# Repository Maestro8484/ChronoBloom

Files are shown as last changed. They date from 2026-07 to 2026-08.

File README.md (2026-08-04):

# ChronoBloom

A 3-ring NeoPixel wall clock on the Seeed XIAO ESP32-C3. Seconds and minutes share the outer 60-LED ring, the way they share one track of marks on a real clock, and the hour hand is a spoke across the 24 and the 12. Web UI, NTP sync, OTA updates, ambient-light auto dimming, and Focus Reminder nudges for when you lose track of time. The diffused rings bloom like a flower, hence the name.

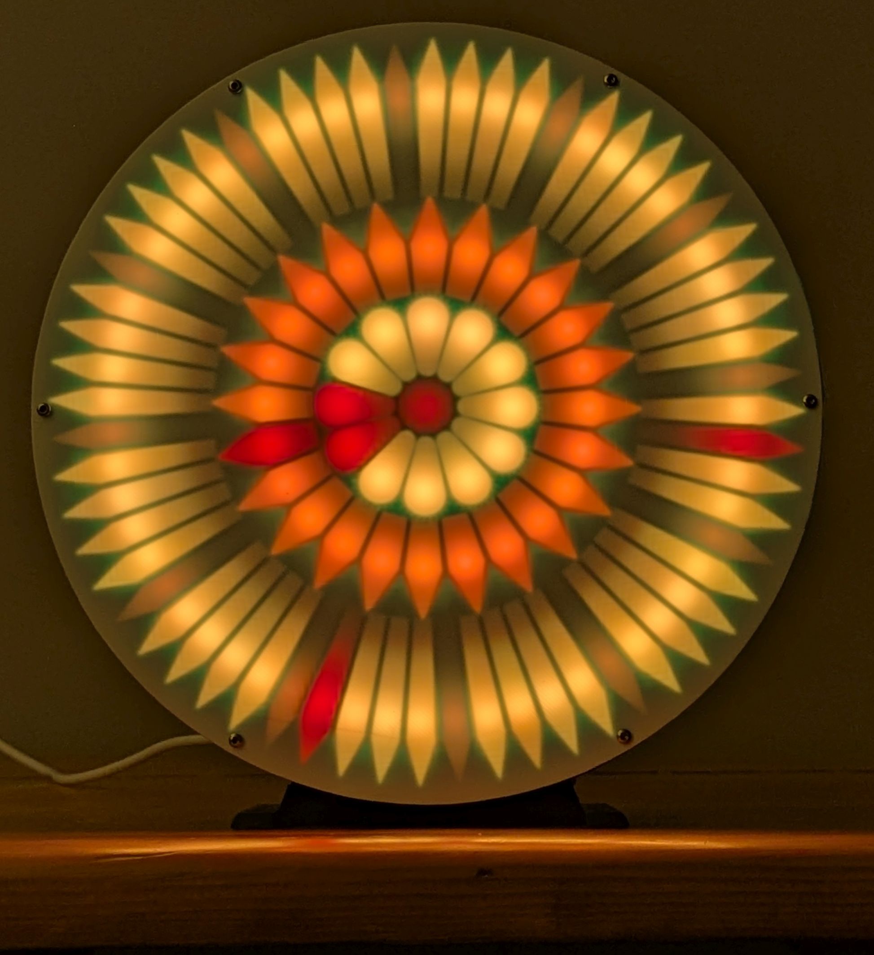
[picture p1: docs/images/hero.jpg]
ChronoBloom 8-inch build, Sunflower theme


ChronoBloom Demo (https://www.youtube.com/watch?v=KO6YdUoTq6A)

## You run the whole thing from a web page

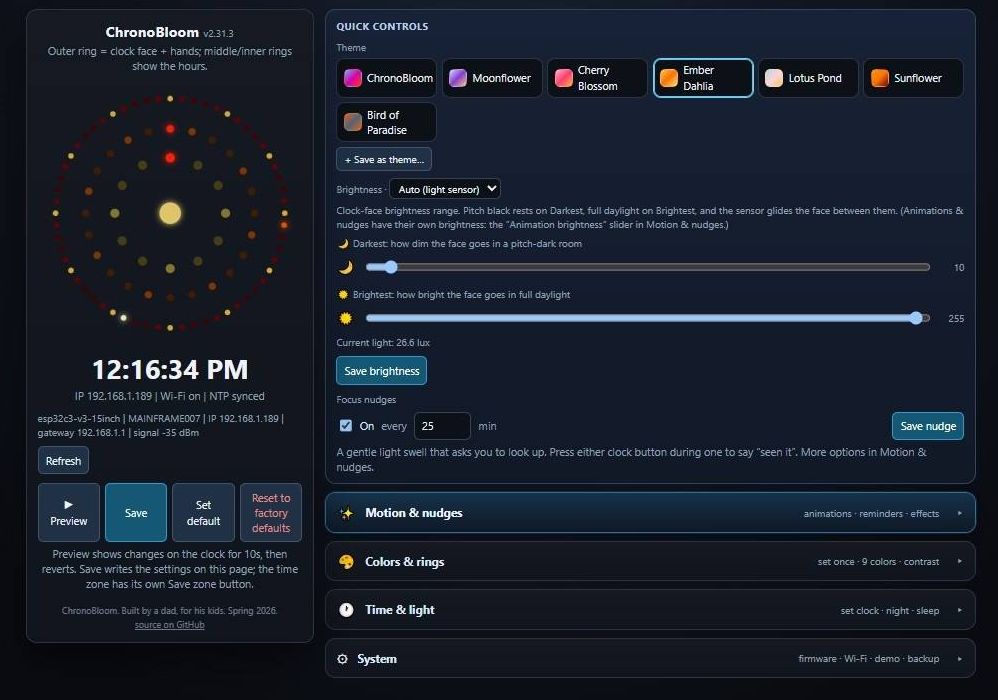
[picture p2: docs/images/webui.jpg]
The ChronoBloom web UI


No app, no account, no cloud. The clock serves this page itself, so you open it from a phone or a
laptop on the same wifi and everything is live as you change it: seven face themes, the color and
brightness of every ring on its own, eleven contrast presets, which animation the chimes and the
nudges play, the light sensor limits, your time zone, firmware updates and a settings backup.

More on it below, and there's a [full three and a half minute
tour](https://www.youtube.com/watch?v=FKXAHg8D2Fs) of every setting.

## Why I built it

I hyperfocus, and I lose hours to the wrong thing. Alarms don't fix it. One lands mid-thought, I
swipe it away, and I've already forgotten it. A change of light in the room does work. So I put it
in the thing I already look up to. And to look pretty.

The clock doesn't nag and there's nothing to dismiss. Every so often the light does something slow
and obvious at the edge of your vision, and you get to decide what happens next. An alarm demands.
A nudge asks. It helps that it's pretty, and that it's already on the wall doing a job, so I never
resent it going off.

The version that gets me is small and ordinary: I went downstairs to print a coloring page, found a
project on the way, and came back up an hour later empty-handed. The project will still be there
tomorrow. My kids being this age won't.

ChronoBloom is a clock built by a dad to keep time, and to keep life above the project at hand.
Look up. Shift gears. Tend to what matters.

The feature is called Focus Reminders and it's in [docs/FOCUS_REMINDERS.md](docs/FOCUS_REMINDERS.md).
Everything else on this clock got built around it.

### About the photos and the video

They don't do it justice, and I don't think a camera can. These are bright, narrow-band
addressable LEDs behind a diffuser. Your eye adapts locally, so a deep saturated red sitting
right next to a pale gold reads correctly, both at once. A sensor can't do that. It clips
whichever channel is brightest, fights the white balance, and blooms the highlights, so the
saturated hues come back either washed out or blown to white.

Getting even these shots took far more takes than it should have (ISO 10, 1/50, dark room) for
quality I'd call barely acceptable. So treat them as a hint, not a record. In other words it
looks better in person, and that's the one thing here I can't show you.

## What it does

- Time from NTP over WiFi, with timezone and DST rules. No RTC chip.
- Web UI on your LAN for colors, brightness, animations, and per-ring settings
- Seven face themes, six named for real blooming flowers (Moonflower, Cherry Blossom, Ember Dahlia, Lotus Pond, Sunflower, Bird of Paradise) and built from that flower's own colors
- Eleven curated contrast presets, plus nine colors you can set one ring element at a time
- Animation palettes are radial: petals on the outer ring, throat on the inner, stamen at the
  center, color ramping rim to core so a chime or a nudge reads as the clock blooming
- Quarter-hour, half-hour, and top-of-hour chime animations (3/3/5 styles)
- A light sensor drives auto-brightness. Pitch black room, LEDs sleep. Light returns, clock wakes.
- Focus Reminders: visual nudge animations at intervals you pick, built for interrupting hyperfocus. A peripheral ask, not an alarm.
- WiFi setup in the browser at flash time, or via captive portal on first boot. No hardcoding credentials.
- OTA firmware updates from a browser after the first USB flash
- Settings persist in EEPROM, with a user-saved defaults slot

## How this compares

[WLED](https://kno.wled.ge/) is a brilliant effects engine with a huge ecosystem, and it beats this project on effect count and community by a mile, but a ring clock like this one is a usermod you compile yourself. [Clockwise](https://github.com/jnthas/clockwise) is a browser-flashable 64x64 matrix clock, and nothing here touches its pixel-art faces. ChronoBloom is clock-first for this three-ring shape: per-ring hands, chimes, focus nudges, a per-frame power budget, lux sleep, and its own browser flasher. If you want an LED playground, run WLED. If you want this clock, this is its firmware.

## Bill of materials

Prices swing. Shop around.

| Part | Qty | Notes | Where |
|---|---|---|---|
| Seeed XIAO ESP32-C3 | 1 | The brain. USB-C, WiFi, tiny. About $10 for one, cheaper per board in a 3-pack. | [Amazon, single](https://www.amazon.com/dp/B0B94JZ2YF?tag=maestro8484-20) / [Amazon, 3-pack](https://www.amazon.com/dp/B0DGX3LSC7?tag=maestro8484-20) |
| WS2812B 241-LED ring set | 1 | Sold as a 9-ring kit (WESIRI), about $26. You use the 60, 24, and 12 rings plus 1 loose pixel for the center. Rest goes in the parts bin. Rings come pre-assembled with 3-wire JST leads. | [Amazon](https://www.amazon.com/WESIRI-WS2812B-Individually-Addressable-Controller/dp/B083VWVP3J?tag=maestro8484-20) |
| VEML7700 lux sensor module | 1 | Optional but worth it. Auto-brightness and dark-room sleep. Usually sold as a 2-pack. | [Amazon](https://www.amazon.com/dp/B0DRRGVTLH?tag=maestro8484-20) |
| Momentary push buttons | 2 | Time up/down, factory reset combo. Prewired 7mm ones save you a soldering job. | [Amazon](https://www.amazon.com/Gebildet-250VAC-Prewired-Momentary-Railway/dp/B083JWJPW5?tag=maestro8484-20) |
| USB-C panel-mount socket | 1 | The power inlet. Mounts in the printed stand; its 5V and ground run up to the XIAO's 5V pin. The charger plugs in here, not into the XIAO. | [Amazon](https://www.amazon.com/dp/B0FNN4JMG3?tag=maestro8484-20) |
| USB-C phone charger, 2A | 1 | Plugs into the panel-mount socket. Any phone charger does it. I run mine on 2A. You almost certainly own one already. | Whatever is in your drawer |
| 300 ohm resistor | 1, optional | Inline on the LED data line. Good practice, and it costs nothing if you have one. Mine run fine without it, so do not let a missing resistor stop you building. | Parts bin, or any resistor kit |
| M2.5 fine thread bolts | 8 | The only fastener in the build. They pass through the front three parts and the back cover, and thread into the ring. **Fine thread, not coarse.** Coarse will strip a printed hole. An assorted box is cheaper than buying one size. | [Amazon](https://www.amazon.com/gp/product/B0GT4PFGSK?tag=maestro8484-20) |

**Why 2A is enough.** All 97 LEDs at full white would want about 5.8A, which sags the rail and browns
the board out. The firmware never lets that happen: before every frame it adds up what the pixels are
about to draw and, if it would cross the budget, dims that one frame to fit. The ceiling is set to
1800mA, sized for a 5V 2A supply. Normal frames pass through untouched.

*Some links above are Amazon affiliate links. As an Amazon Associate I earn from qualifying purchases. It costs you nothing extra and it doesn't change which parts I recommend. Buy them anywhere you like, the build doesn't care.*

Plus a 3D printer, a spool of basic PLA, a bit of white PLA for the front diffuser, some wire, and hot glue or cable ties.

## Build it, step by step

Six steps from a box of parts to a running clock. Each one has a check. If a check fails, jump to the matching row in [If it doesn't work](#if-it-doesnt-work).

**What you need to be able to do:** print, and ideally solder a little. Flashing needs no toolchain, it's a web page.

The rings arrive pre-assembled with 3-wire JST connectors, so nothing here is fine-pitch or fiddly. Soldering the chain is about getting a joint that stays put in a clock hanging on a wall for years, not about making the connection possible in the first place. If you buy the XIAO with pins presoldered, and use the prewired buttons from the BOM, you can get most of the way with a scrap of protoboard and Dupont jumpers. You can force Dupont pins into the JST housings too, but they are the wrong size for it and it will let you down eventually, so solder the ring chain if you can.

1. **Print the parts.** Print the 8" set (below): the frame ring, the **reflector** that sits behind the LEDs and shapes the light into pointed hands, the **front diffuser** that softens them into a bloom, the **spacer** that sets the depth and keeps light from bleeding between rings, the back cover and the stand. The reflector and the diffuser do opposite jobs, so do not swap them, and the spacer is not optional. Settings and the front-diffuser rules are in [docs/PRINTING.md](docs/PRINTING.md). Basic PLA for everything except the front diffuser, which has to be white.
   *Check:* parts release cleanly from the bed, and the three ring seats hold the 60, 24, and 12 LED rings without forcing.
2. **Wire it.** Follow [Wiring](#wiring). Ring data leaves GPIO10, ideally through the 300 ohm resistor, the rings feed from the XIAO's 5V pin, and the sensor takes 3V3.
   *Check:* meter on continuity across 5V and GND before you plug anything in. No beep means no short.
3. **Flash the firmware.** Easiest is the browser flasher at [maestro8484.github.io/ChronoBloom/flasher](https://maestro8484.github.io/ChronoBloom/flasher/). Building from source works too, see [Flash it](#flash-it).
   *Check:* within a few seconds the rings glow blue, or the browser offers to set up WiFi. Blue means the firmware is alive.
4. **Get it on WiFi.** Use the browser WiFi setup if it appears, or join the `esp32c3-clock-setup` network and pick yours. See [WiFi setup](#wifi-setup).
   *Check:* `http://esp32c3-v3-8inch.local/` opens the web UI.
5. **Set your time zone.** In the web UI, Time & light, Time zone. Pick a zone or paste your own.
   *Check:* the clock shows your correct local time within a few seconds. No reboot needed.
6. **Fit the front diffuser and close it up.** The thin printed white PLA sheet sits over the rings.
   *Check:* the light blooms soft and even, with no single LED points poking through.

## Two builds

### 8" build (start here)

The recommended path, and the one the files here are tuned for. The scale is what it is: sized so the rings from the 241-LED kit seat precisely, not to suit any particular printer. Largest part is 209 mm square, which fits a 220 mm bed (Ender 3 class) and sits comfortably on a 256 mm one. Single NeoPixel chain of 97 LEDs: the three rings, then the center pixel. A thin white PLA front diffuser over the face. A desk kickstand ships with the files; there's no wall-mount feature in the 8" parts, so hanging it is on you. Weighs about 500g.

Build environment: `esp32c3_v3_8inch`

### 15" build (showcase)

198% scale, which is where the outer ring's LED spacing lands right. Frame prints in thirds with alignment pins. The front diffuser needs one of:

- Laser-cut acrylic (600mm x 410mm bed) with parchment paper behind it
- 0.5mm white PLA face printed on an XXL-bed printer

Separate center pixel strip on GPIO20. This is the wall piece. Build the 8" first, then decide if you want to go big.

Build environment: `esp32c3_v3_15inch`

### 3D print files

Current 8" set: [docs/publish/ChronoBloom_3D_Files/ChronoBloom_8inch/V13/](docs/publish/ChronoBloom_3D_Files/ChronoBloom_8inch/V13/). Six printable parts plus an assembly 3MF with the print profiles already set, a second 3MF showing the stack in assembly order, and SVGs of the flat parts for anyone cutting rather than printing. 15" set: [ChronoBloom_15inch/](docs/publish/ChronoBloom_3D_Files/ChronoBloom_15inch/). Print settings and the front-diffuser rules are in [docs/PRINTING.md](docs/PRINTING.md). CC BY 4.0, credit Steve Manley (see [NOTICE](NOTICE)).

Two of those parts do opposite jobs and the names matter. The **reflector** sits behind the LEDs and shapes the light into pointed hands, and that's the part remixed from Steve Manley's design. The **front diffuser** is a separate thin white sheet over the face that softens the pixels into a bloom. That one's mine, and it's the fussy one to print.

The **spacer** is the third one people skip, and it earns its place twice. Its raised rings stand exactly as tall as the WS2812B rings sit once they're seated in the reflector, so the stack closes at the right height, and those same rings sit between the 60, the 24 and the 12 as walls so one ring's light doesn't wash into the next. Flat side faces away from the front of the clock.

**Holding it together.** M2.5 fine thread bolts, and nothing else. No glue, no pins, no inserts. The ring is the spine: it's 21 mm thick and everything threads into it. One bolt runs from the front through all three front parts, the diffuser, the reflector and the spacer, and bites into the ring. The back cover bolts into that same ring from behind. The pass-through holes are 2.9 mm so the bolt slides, and the ring's own holes are 2.6 mm so the thread cuts in and holds.

Use **fine** thread. Coarse M2.5 strips a printed hole on the first turn. If your printer runs tight and a bolt won't start, open the ring holes with a 2.6 mm bit rather than forcing it, and leave the 2.9 mm holes alone.

The LED rings drop straight into the recessed seats in the printed core, no forcing, no rework. Measured with calipers, the rings are 172 mm across the outer 60, 92 mm across the middle 24 and 52 mm across the inner 12, with a 6 mm opening in the middle for the single center LED. Any WS2812B rings at those diameters will seat.

## Wiring

```
XIAO Pin    GPIO    Function                Notes
─────────────────────────────────────────────────────────────
D10         GPIO10  NeoPixel data (rings)   Through 300 ohm resistor (optional)
D7          GPIO20  NeoPixel data (center)  15" build only
D3          GPIO5   Button UP               INPUT_PULLUP, polled
D9          GPIO9   Button DOWN             INPUT_PULLUP, polled
D4          GPIO6   I2C SDA                 VEML7700
D5          GPIO7   I2C SCL                 VEML7700
5V/VIN      -       LED power rail          Fed from the panel-mount USB-C socket in the stand; one charger powers everything
GND         -       Common ground           Board and LED rings
3V3         -       VEML7700 power only     Do NOT power LEDs
─────────────────────────────────────────────────────────────
AVOID: GPIO2, GPIO8 (boot strapping); GPIO3/GPIO4 (JTAG)
```

Don't hold the DOWN button (GPIO9) at power-on. It's the ESP32-C3 boot pin.

Two USB-C sockets exist in a finished build, and they are not interchangeable. The
**panel-mount socket in the stand** is the power inlet: the charger plugs in there, and its
5V and ground run up to the XIAO's 5V/VIN pin. The **XIAO's own USB-C port** is for flashing
only. They share one power net inside the board, so never have both live at once: unplug the
stand's power before you connect a flashing cable.

### Chain order

One data line runs through everything, biggest ring first, each ring's DOUT into the next one's DIN:

```
GPIO10 --[300 ohm]--> DIN [ 60-ring ] DOUT --> DIN [ 24-ring ] DOUT --> DIN [ 12-ring ] DOUT --> center pixel
                          seconds and                24h hand                12h hand              status
                          minutes
```

That's 97 LEDs on one wire, and the firmware counts them in exactly that order: the center is
the last pixel in the chain. Get the order wrong and the clock lights up but the face is
scrambled, because every index lands on the wrong ring.

The rings all run the same way, outer to inner, most LEDs to fewest. Watch the DIN and DOUT
markings on each ring rather than guessing from the physical layout.

They come pre-assembled with 3-wire JST leads, one set in and one set out: 5V, ground and data.
That makes the direction easy to read, and it means you can dry-fit the whole chain and power it
up to check the order before committing to solder.

**The center pixel can be its own wire instead.** The 15" build already does this, on GPIO20,
and the firmware supports it as a build option. Worth doing if you'd rather drive the center
from something else, since it is only the status indicator: it shows WiFi and board state, and
the web UI can set it to a bloom pulse, status only, off, or a temperature readout if you ever
add a sensor for it.

Full pin maps, LED indexing, power math, and assembly notes: [docs/HARDWARE.md](docs/HARDWARE.md)

## Flash it

Easiest way: [maestro8484.github.io/ChronoBloom/flasher](https://maestro8484.github.io/ChronoBloom/flasher/). Chrome or Edge on a desktop, plug the board in over USB-C, click the button. No install.

If you'd rather build from source, that path stays fully open too. Needs [PlatformIO](https://platformio.org/) (VS Code extension or CLI).

```
git clone https://github.com/Maestro8484/ChronoBloom.git
cd ChronoBloom
```

The 8" is what `pio run` builds by default. Pass `-e esp32c3_v3_15inch` if you want the 15".

First flash over USB:

```
pio run -e esp32c3_v3_8inch -t upload --upload-protocol esptool --upload-port COMx
```

Swap `COMx` for your port (`/dev/ttyACM0` on Linux). Serial monitor runs at 115200.

Every flash after that is OTA from a browser:

1. Build: `pio run -e esp32c3_v3_8inch`
2. Open `http://esp32c3-v3-8inch.local/update`
3. Upload `.pio/build/esp32c3_v3_8inch/firmware.bin`

Inner ring shows blue during update, green on success, red on failure. Device reboots itself.

## WiFi setup

No credentials in code. On first boot the clock listens over the same USB cable for a browser-based WiFi setup (the flasher page above may offer this right after flashing). Type your network name and password there and you're done.

If that doesn't show up, or you skip it, the clock opens its own captive portal instead:

1. Join the WiFi network `esp32c3-clock-setup` from your phone (no password)
2. A setup page opens (or go to `http://192.168.4.1`)
3. Pick your network, enter the password
4. Clock saves it and connects. It remembers across power cuts

After that it auto-connects on boot. If the password changes or the network disappears, the portal comes back.

Then open the web UI: `http://esp32c3-v3-8inch.local/` (or the IP from your router's device list).

## The web UI

Everything is set from here. No app, no account, no cloud. It is one page served off the clock itself, so it works on a phone or a laptop on the same network.

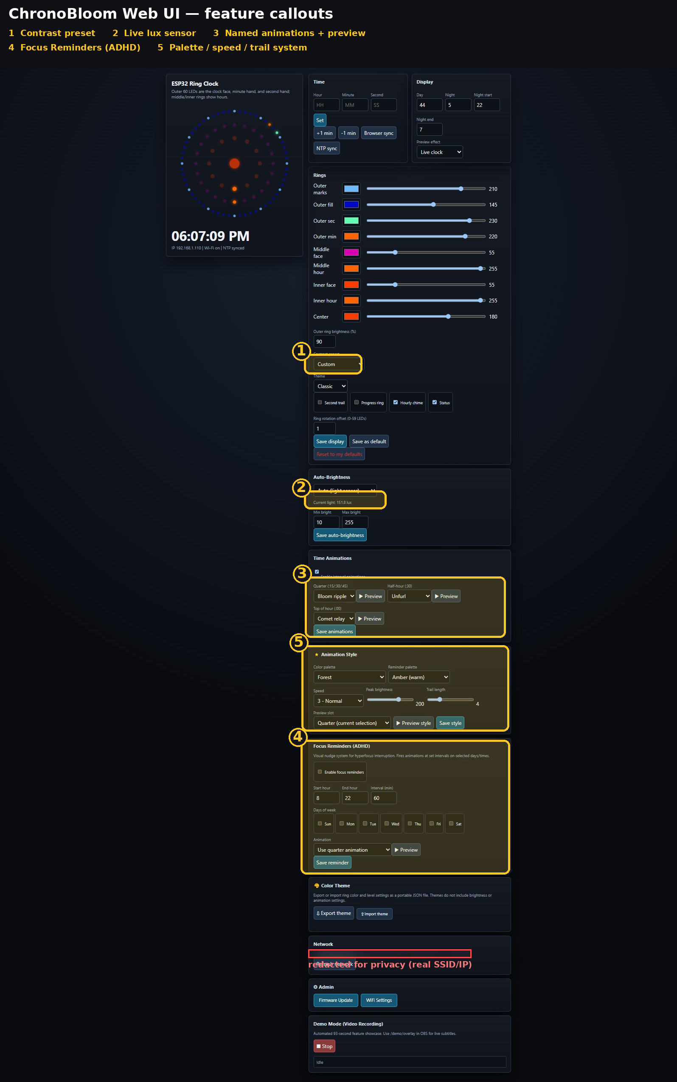
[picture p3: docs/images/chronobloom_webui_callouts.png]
The ChronoBloom web UI, with the main controls labelled


Quick controls sit at the top for the things you change often. The four sections below them hold the rest: motion and nudges, colors and rings, time and light, and system tools like firmware updates and settings backup.

There's a full tour of it on video, about three and a half minutes, every setting: [ChronoBloom web UI walkthrough](https://www.youtube.com/watch?v=FKXAHg8D2Fs).

**One thing to know before you hang it up.** There's no password on any of this. Anyone who can reach the clock on your network can open the page, change every setting, read which network it's joined to, and push new firmware to it. That's a deliberate trade for a thing that lives on your wall and gets set up once, and it's the same trade most LAN gadgets make, but it does mean this belongs on your home network and not on the open internet. Don't port-forward it.

If an update ever leaves it unable to boot, there's no automatic rollback. Plug it into USB and flash it again with the [browser flasher](https://maestro8484.github.io/ChronoBloom/flasher/), which is the same two minutes as the first flash.

## If it doesn't work

The likeliest snags, keyed to the build steps above.

| What you see | Step | Try this |
|---|---|---|
| Parts warp, or a ring won't seat in its seat | 1 | Slow the print, check bed adhesion. A little cleanup of stringing around the seats is normal. |
| Everything lights, but the hands are on the wrong rings | 2 | Chain order. It has to be 60, then 24, then 12, then the center pixel, each ring's DOUT into the next ring's DIN. Any other order and the firmware's indexes land on the wrong ring. |
| One ring works, everything after it stays dark | 2 | A joint failed at that point in the chain. Data only flows one way through these rings, so the break is at the DOUT of the last ring that works, or the DIN of the first that doesn't. |
| Something smells hot | 2 | Kill power immediately. Continuity-test 5V to GND before powering up again. |
| No serial port shows up when flashing | 3 | Use a USB-C cable that carries data, not a charge-only one. Close anything else holding the port (serial monitor, Arduino IDE). |
| Rings never turn blue after a flash | 3 | Reseat the cable and flash again. The rings feed from the XIAO 5V pin, so if they never light, check that joint and the data line. A weak computer USB port may not carry full demo brightness; a 2A charger will. |
| `esp32c3-v3-8inch.local` won't open | 4 | Use the clock's IP from your router's device list. Some networks block mDNS name lookup. |
| Time is wrong by whole hours | 5 | Set the time zone in step 5. A missing or bad zone falls back to UTC. |
| Light looks patchy or single dots show through | 6 | That's the front diffuser. Check it printed solid with no sparse gap in the middle, and that the surface fill came out Monotonic and not Concentric. Thickness is worth a couple of tries. See [docs/PRINTING.md](docs/PRINTING.md). |

## Docs

- [docs/HARDWARE.md](docs/HARDWARE.md): pins, LED mapping, power, construction
- [docs/PRINTING.md](docs/PRINTING.md): print settings and the diffuser
- [docs/FEATURES.md](docs/FEATURES.md): every feature, current and planned
- [docs/ANIMATIONS.md](docs/ANIMATIONS.md): animation catalog and triggers
- [docs/API.md](docs/API.md): web endpoints, settings JSON, client examples
- [docs/TROUBLESHOOTING.md](docs/TROUBLESHOOTING.md): when it doesn't work
- [docs/ARCHITECTURE.md](docs/ARCHITECTURE.md): codebase structure, for contributors
- [docs/FOCUS_REMINDERS.md](docs/FOCUS_REMINDERS.md): the focus-nudge feature in depth
- [docs/HISTORY.md](docs/HISTORY.md): the full decade-long design story
- [docs/CHANGELOG.md](docs/CHANGELOG.md): version history

## Support

One person built and maintains this as a hobby project. Support is best effort. Open an issue with the bug report or build help template and I'll get to it when I can. No SLA, no promises, but I do read everything.

If ChronoBloom saved you time, you can [buy me a coffee](https://buymeacoffee.com/maestro8484). Never expected, always appreciated.

## Origin story and credits

**Steve Manley** built the original NeoPixel Ring Clock in 2015 (Arduino Nano, DS3234 RTC, 3D printed frame). The electronics weren't the draw (ESP32s and addressable LEDs were already familiar territory). It was his 3D-printed design: the way the reflector shapes and throws the LED glow into crisp pointed hands, like a real clock. The printed reflector in this repo, the part that casts and shapes the light, is a remix of his design. The front diffuser is a separate part and a separate job, and that one is mine.

From there, a decade of builds by **Maestro8484**:

- **First edition**: Arduino Nano + RTC + two buttons. Setting time through interrupt-driven buttons was fiddly, but it ran for 2-3 years.
- **ESP8266 port**: same clock, new brain. Ran fine for years; never needed WiFi features.
- **8" build**: the replicable one, and what this repo targets. Sized until the off-the-shelf rings seated precisely. Largest part measures 209 mm square, about 8 inches, which is where the name comes from. Alongside it, a custom 10" glow-in-dark wall clock built around Steve's reflector with UV LEDs behind the frame.
- **15" build**: the 8" design scaled ~198% so the outer ring pitch exactly matches side-lit WS2812B strip LED spacing. Much print-and-diffuser trial and error; parchment paper beat every 3D-printed diffuser from 0.8mm down to 0.2mm.
- **ChronoBloom (2026)**: ground-up rewrite on the XIAO ESP32-C3: web UI, NTP, OTA, lux-sensor auto-brightness, Focus Reminders. The two buttons stay as a hardware fallback.

Thanks to Steve for the design that started all of this. Attribution: [NOTICE](NOTICE). Full story: [docs/HISTORY.md](docs/HISTORY.md).

## License

Firmware: [Apache 2.0](LICENSE). Hardware/STL files: [CC BY 4.0](LICENSE-HARDWARE).

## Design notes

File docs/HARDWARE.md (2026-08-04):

# ChronoBloom ESP32-C3 -- Hardware Specifications

## LED Configuration

### Ring Layout
- **Outer ring**: 60 LEDs (seconds hand + minute hand + quarter-hour markers)
- **Middle ring**: 24 LEDs (hour hand display + ambient fill)
- **Inner ring**: 12 LEDs (hour hand display + ambient fill)
- **Center pixel**: 1 LED (status indicator, breathing animation)

### Variants
**8" Clock (esp32c3_v3_8inch)**:
- Total: 97 LEDs on single strip (60 + 24 + 12 rings, then center pixel)
- Ring pixel offset: 0 (logical ring LED 0 is physical index 0)
- Center pixel: physical index 96 (last in chain)
- Data line: GPIO10 -> 300 ohm resistor (optional) -> DIN of the outer ring

Physical index 0 is a working ring LED. If it dies, everything after it goes dark
too -- a known WS2812B property, because each pixel reads the data and re-sends it
to the next one. The fix is replacing that one pixel, not the whole ring.

> **Note on "sacrificial" first pixels.** Some WS2812B builds put an extra LED
> ahead of the rings, keep it permanently dark, and use it purely to clean up the
> data signal: the ESP32-C3 drives its data pin at 3.3 V, the LEDs want about
> 3.5 V to read a reliable "1" off a 5 V supply, and the first LED re-sends the
> signal at its own full 5 V for everything behind it. ChronoBloom's original 8"
> prototype carried one from early signal troubleshooting. **It was removed on
> 2026-08-01, along with the firmware support for it.** All builds are now the
> plain 97-LED chain.
>
> **Placement is the point.** The sacrificial LED goes right at the board, beside
> the 5 V rail, so the weak 3.3 V signal only travels a couple of centimetres
> before being re-sent as a clean full-swing 5 V one -- and it is that strong
> signal which then makes the long run out to the rings. So it buys data-line
> distance as well as reliability: not by boosting the far end, but by shrinking
> the fragile stretch to almost nothing. Put it at the far end instead and it
> achieves nothing, because the marginal signal has already made the trip.
>
> It is still worth understanding, because it explains a family of "first LED
> flickers", "random sparkle", "works cold, glitches warm" faults -- and one
> genuinely counter-intuitive case where a *better* 5 V supply makes things worse,
> because the LED's threshold scales with its supply voltage. `src/main.cpp` has
> the full plain-English write-up above the LED geometry constants, including the
> symptom list. A 74AHCT125 buffer is the purpose-built version of the same idea,
> fitted in the same place for the same reason, and is what to use on a long run.

**15" Clock (esp32c3_v3_15inch)**:
- Main strip: 96 LEDs (rings only, physical indexes 0-95)
- Separate center strip: 1 LED on GPIO20 (CENTER_PIXEL_SEPARATE_OUTPUT=1)
- Ring offset: 0 -- physical index 0 is the first ring LED (12 o'clock, outer ring)

---

## Pin Assignments (XIAO ESP32-C3)

### NeoPixel Data
| Pin | GPIO | Function | Notes |
|---|---|---|---|
| D10 | GPIO10 | NeoPixel rings (DIN) | 300 ohm resistor inline, optional |
| D7 | GPIO20 | Center pixel (DIN) | 15" variant only |

### User Input
| Pin | GPIO | Function | Notes |
|---|---|---|---|
| D3 | GPIO5  | Button UP | INPUT_PULLUP, polled (no ISR), 50ms debounce |
| D9 | GPIO9  | Button DOWN  | INPUT_PULLUP, polled (no ISR), 50ms debounce; also XIAO BOOT pin -- do not hold at power-on reset |
| (n/c)  | GPIO3  | Unused | JTAG TCK -- do NOT use for ISR inputs |
| (n/c)  | GPIO4  | Unused | JTAG TDI -- do NOT use for ISR inputs |

> **Button hold-to-repeat**: Short press plus or minus 1 min. Hold >500ms: repeat plus or minus 1 min every 150ms.
> Hold >2s: repeat plus or minus 60 min per fire. Release stops immediately.
>
> **Factory reset**: Hold UP (GPIO5) at power-on -> red LEDs appear ->
> add DOWN (GPIO9) and hold both 3s -> white flash -> reboot into WiFi portal.
> GPIO9 must NOT be held at the power-on instant (enters download mode).

### I2C Bus (Sensors)
| Pin | GPIO | Function  | Wire Color | Connected Devices |
|---|---|---|---|---|
| D4 | GPIO6  | I2C SDA | Green | VEML7700 (0x10) |
| D5 | GPIO7  | I2C SCL | Yellow | VEML7700 |

### Power
| Pin | Function | Notes |
|---|---|---|
| 5V / VIN  | Board input AND LED power rail | Fed from the USB-C panel-mount socket in the stand, the build's power inlet. The XIAO's own USB-C port is for flashing only; its VBUS line and this pin share one internal net, so power put on either one reaches both. The rings tap this same pin; there is no separate LED supply |
| GND | Common ground | Rings share ground with the XIAO |
| 3V3 | Logic power only | **Do NOT power LEDs from 3.3V.** The VEML7700 lux sensor is its only load |

**Never power the board from the 5V pin and the XIAO's own USB-C port at the same
time.** The hazard is a flashing cable in the XIAO's socket while the stand's
panel-mount inlet is live; the panel-mount inlet alone is the normal route.
Because the two are the same net, doing both back-feeds one source into the
other with nothing in between to stop it. That is only safe with a blocking
diode (an "OR-ing" or ideal-diode circuit) between the two inputs. This board
has no such diode fitted. Pick one power source and unplug the other before
connecting the second.

A 5V 2A supply wired directly to the 5V pin powers the whole clock. The
firmware sums each frame's LED draw and dims any frame that would cross the
1.8A budget, so the supply is never overdrawn. Details under Power
Requirements below.

### Avoid These Pins
- **GPIO2, GPIO8** -- ESP32-C3 boot strapping pins. Never use for peripherals.
- **GPIO9** -- also a strapping pin (BOOT). It works for exactly one job: the polled
  pull-up Button DOWN, as wired above. Nothing else, and never held low at the
  power-on instant (that puts the chip in download mode).

---

## Sensors

### VEML7700 Ambient Light Sensor
- **I2C Address**: 0x10 (default, fixed)
- **Range**: 0-120,000 lux with auto-gain
- **Power**: 3.3V
- **Purpose**: auto-brightness and dark-room display sleep
- **Library**: Adafruit_VEML7700

**Wiring**:
```
VEML7700 VCC -> XIAO 3.3V
VEML7700 GND -> XIAO GND
VEML7700 SDA -> GPIO6 (green wire)
VEML7700 SCL -> GPIO7 (yellow wire)
```

---

## Physical Construction

### Materials
**Frame**:
- Any PLA, 3D printed. UV glow-in-the-dark PLA is a nice touch: it charges off the LEDs and glows softly after the display sleeps.

**Diffuser**:
- 8": 0.6mm printed white PLA over the face (see [PRINTING.md](PRINTING.md))
- 15": laser-cut acrylic with parchment paper behind it, or a 0.5mm printed PLA face

### Scale Variants
**8" Clock**:
- Sized so the 241-LED kit's rings seat precisely. Largest part measures 209 mm square, about 8 inches, so a 220 mm bed (Ender 3 class) is enough
- Single-piece parts where possible

**15" Clock**:
- 200% scale
- Frame prints in thirds, joined with alignment pins
- Acrylic face needs a 600mm x 410mm laser bed

### Assembly Notes
- LED rings mounted with cable ties or hot glue
- Wire management: route all wires through center, exit at bottom

---

## Power Requirements

### LED Power Consumption
- **Per LED**: ~60mA at full white (all channels 100%)
- **Typical usage**: ~20mA per LED (colored, not full brightness)
- **Total worst-case** (97 LEDs, 8" variant): 5.8A @ 5V (rare, only during full-white test)
- **Typical operation**: 1.5-2A @ 5V (clock display mode)

### Recommended Power Supply
A 5V 2A supply wired to the 5V/VIN pin is enough. The firmware caps total LED draw at 1800mA (`MAX_LED_MILLIAMPS`): before every frame it adds up what the pixels are about to draw and dims that frame if it would cross the budget. So the worst-case 5.8A can't actually happen.

### ESP32-C3 Power
- **Active WiFi**: ~120mA @ 3.3V
- **Powered via**: 5V/VIN pin on this build. The USB-C socket is an alternate input on the same net, not a second simultaneous source -- see the warning under Pin Assignments > Power.

---

## Mounting
- **Wall-mounted**: Keyhole slots in back frame (15" variant)
- **Desktop stand**: 3D printed kickstand (8" variant)
- **Weight**: ~500g (8"), ~1.2kg (15")

---

## Firmware Pin Mapping (Code Reference)

### Build Flags (platformio.ini)
```ini
-D LED_DATA_PIN=10
-D CENTER_PIXEL_PIN=20           # 15" variant only
-D CENTER_PIXEL_SEPARATE_OUTPUT=1 # 15" variant only
-D LUX_SENSOR_I2C_SDA=6
-D LUX_SENSOR_I2C_SCL=7
```

### Ring Config (main.cpp)
```cpp
// Both variants use RING_PIXEL_OFFSET = 0.
// Raise it only if your chain has unused LEDs before the outer ring.
constexpr RingConfig RING_OUTER_60  = {60, RING_PIXEL_OFFSET,      true};  // 60 LEDs
constexpr RingConfig RING_MIDDLE_24 = {24, RING_PIXEL_OFFSET + 60, true};  // 24 LEDs
constexpr RingConfig RING_INNER_12  = {12, RING_PIXEL_OFFSET + 84, true};  // 12 LEDs
```

### LED Indexing (8" variant, default geometry)
- **Physical strip indexes 0-59**: Outer ring (seconds/minutes), logical 0-59
- **Physical strip indexes 60-83**: Middle ring (hours), logical 0-23
- **Physical strip indexes 84-95**: Inner ring (hours), logical 0-11
- **Physical strip index 96**: Center pixel

> If a chain ever carries unused LEDs ahead of the outer ring, raise
> `RING_PIXEL_OFFSET` and `CLOCK_PIXEL_COUNT` to match, via a `[led_chain]`
> override in `platformio.local.ini`. Firmware geometry and real wiring must
> always agree: a mismatch rotates the whole clock face by one LED.

### LED Indexing (15" variant)
- **Physical strip indexes 0-59**: Outer ring, logical 0-59
- **Physical strip indexes 60-83**: Middle ring, logical 0-23
- **Physical strip indexes 84-95**: Inner ring, logical 0-11
- **Separate strip index 0**: Center pixel (GPIO20)

---

## Testing & Calibration

### I2C Bus Scan (Check Sensor Connection)
```cpp
Wire.begin(6, 7);
for (uint8_t addr = 1; addr < 127; addr++) {
  Wire.beginTransmission(addr);
  if (Wire.endTransmission() == 0) {
    Serial.print("Found I2C device at 0x");
    Serial.println(addr, HEX);
  }
}
// Expected: 0x10 (VEML7700)
```

### LED Mapping Test
Add to `setup()` for visual verification:
```cpp
// Light each ring in sequence
for (int i = 0; i < 60; i++) {
  strip.setPixelColor(i + RING_PIXEL_OFFSET, strip.Color(255, 0, 0));
  strip.show();
  delay(50);
}
```

### Brightness Calibration
- **Dark room** (0-1 lux): Target brightness ~15
- **Evening light** (10 lux): Target brightness ~60
- **Indoor day** (100 lux): Target brightness ~120
- **Bright window** (1000 lux): Target brightness ~200
- **Direct sun** (10,000+ lux): Target brightness 255

Adjust logarithmic curve in `LuxSensor::autoBrightness()` if needed.

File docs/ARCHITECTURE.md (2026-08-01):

# Architecture: Focus Reminder System (v2.0+)

## Overview
The Focus Reminder system is a non-blocking scheduler that fires attention-grabbing NeoPixel animations at user-configured intervals during active hours on selected days. Designed for ADHD hyperfocus interruption and task switching cues.

## Components

### FocusReminderScheduler Class
- **Location:** `src/main.cpp` (new in v2.0)
- **Scope:** Application-level scheduler, independent of WebUI
- **Loop cycle:** Called once per main loop iteration (every ~1ms)
- **State stored in:** `ClockSettings.focusReminder_*` fields (EEPROM-backed)

### Scheduling Logic
```
checkAndFire(now) {
  1. Check master enable flag
  2. Get current day-of-week (from the NTP-synced epoch; filter skipped if never synced)
  3. Validate day matches bitmask
  4. Validate current hour in window [startHour, endHour)
  5. Validate interval elapsed: (now - lastFireMs) >= (intervalMinutes * 60000ms)
  6. If all pass: trigger animation + update lastFireMs
}
```

### Animation Reuse
Reminders can invoke existing `ClockRenderer` methods (or fire a dedicated nudge):
- `triggerQuarterAnimation(now)` -- Slow Comet, Dual Orbit, or Bloom Ripple
- `triggerHalfHourAnimation(now)` -- Unfurl, Three Comets, or Breathe
- `triggerHourAnimation(now)` -- Ceremony, Galaxy Spin, Supernova, Comet Relay, or Deep Breath

Six dedicated nudge animations also exist (modes 6-11: Gentle Pulse, Orbiting Orb, Ripple In, Heartbeat, Slow Bloom, Firefly). All reminder animations are non-blocking `millis()`-based state machines; the loop, web UI, and time-keeping run throughout.

### EEPROM Schema
```cpp
struct ClockSettings {
  // ... existing 180 bytes ...
  
  // Focus Reminders (16 bytes total)
  uint8_t focusReminder_enabled;          // 1 byte: 0=off, 1=on
  uint8_t focusReminder_startHour;        // 1 byte: 0-23
  uint8_t focusReminder_endHour;          // 1 byte: 0-23
  uint16_t focusReminder_intervalMinutes; // 2 bytes: 1-1440
  uint8_t focusReminder_daysMask;         // 1 byte: bitmask Sun(0)-Sat(6)
  uint8_t focusReminder_animation;        // 1 byte: 0-11 (0-5 reuse chime anims, 6-11 dedicated nudges)
  uint8_t focusReminder_durationSeconds;  // 1 byte: reserved for v2 (currently unused)
  uint32_t focusReminder_lastFireMs;      // 4 bytes: reserved; fire time is tracked in RAM only
  // 3 bytes reserved for future expansion
};
```

**Validation:** `SettingsStore::valid()` checks all fields are in legal range.
**Defaults:** Reminder disabled, 08:00-22:00 window, 60-min interval, no days selected, animation 0 ("Use quarter animation").
**Persistence:** Auto-saved to EEPROM on WebUI "Save reminder" button.

### WebUI Integration
- **Panel:** "Focus Reminders (ADHD)" (new section in main settings page)
- **Controls:**
  - Enable/disable toggle
  - Start/end hour (number inputs, 0-23)
  - Interval (number input, 1-1440 minutes)
  - Days-of-week selector (7 checkboxes, Sun-Sat, stored as bitmask)
  - Animation dropdown (9 options: reuse the quarter/half-hour/hour chime animation, or one of the six dedicated nudges)
  - Save button (POSTs to `/settings` endpoint)
- **Real-time sync:** Reminder config loaded at page load, updates reflected after save

### Time Validation
- Window is half-open: `[startHour, endHour)` (e.g., 08:00-22:00 fires 08:00-21:59)
- Wrapped windows supported: if `startHour > endHour`, window crosses midnight (e.g., 22:00-08:00)
- Day-of-week: 0=Sunday, 6=Saturday (bitmask, e.g., 0x7F = all days)

### Interval Timing
- Last fire timestamp stored as `millis()` at time of animation trigger
- Interval calculated as: `uint32_t(intervalMinutes) * 60000UL` milliseconds
- Clock wraps at ~49 days; interval logic handles correctly via unsigned arithmetic
- Fire occurs when: `(now - lastFireMs) >= intervalMs`

### Serial Logging
Each fire logs:
```
[FocusReminder] Fired at HH:MM (interval=N min)
```
Enable via Serial monitor at 115200 baud.

### No Blocking on Reminder Fire
- Scheduler call is non-blocking (< 1ms)
- Animation trigger calls `renderer_.triggerReminderDirectAnimation(mode, now)`
- Reminder animations are non-blocking `millis()`-based state machines; no `delay()`

### Day-of-Week Calculation
Computed from the NTP-synced system epoch via `localtime_r()` (`tm_wday`, 0=Sun).
If the epoch was never synced (offline boot, time set via buttons/web), the day
filter is skipped rather than silently never firing; the hour window still applies.

---

## Testing Checklist

- [ ] Firmware compiles (pio build)
- [ ] Device boots, WebUI loads, new "Focus Reminders (ADHD)" panel visible
- [ ] Enable toggle works (setting persists after reboot)
- [ ] Start/end hour inputs work (0-23 range enforced)
- [ ] Interval input works (1-1440 range, clamped)
- [ ] Days-of-week toggles set bitmask correctly
- [ ] Animation dropdown selects animation type
- [ ] Save button POSTs to `/settings` and triggers reload
- [ ] Disable reminder: animation does not fire (confirmed via console log)
- [ ] Set time to within window + matching day, wait interval: animation fires
- [ ] Interval fires multiple times: every 60 min (if set to 60)
- [ ] Outside time window: no fire
- [ ] Non-matching day: no fire (requires an NTP-synced clock)

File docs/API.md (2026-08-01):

# ChronoBloom ESP32-C3 -- Web API Reference

> Ground truth: `src/main.cpp` (`setupRoutes()`, `setupDemoModeRoutes()`, `struct ClockSettings`).
> If this document and the source disagree, the source wins and this file is stale.
> Schema below matches `SETTINGS_VERSION 19` (firmware v2.30.x/v2.31.0 era).

## HTTP Endpoints

**Base URL**: `http://esp32c3-v3-8inch.local/` (or direct IP address)

Example IPs in this document use the documentation range `192.0.2.x`; your device will have a real LAN address (check `/net` or your router).

---

## GET Endpoints

### `GET /`
**Description**: Serve main web UI page

**Response**: HTML page with embedded JavaScript and CSS

**Features**:
- Live SVG clock preview (updates every 90ms)
- Time controls (manual set, browser sync, NTP sync, +/- minute, time zone)
- Display settings (brightness, schedule, themes)
- Ring color pickers (9 elements: outer marker, outer fill, seconds, minutes, hours, middle face, inner face, inner hour, center)
- Petal depth slider (0-100, all three rings)
- Animation controls (second trail, progress ring, chimes, interval animations, Animation Style panel with preview)
- Auto-brightness controls (mode, Darkest/Brightest sliders, live lux display)
- Focus Reminders panel
- Demo mode controls (start/stop, pre-roll, live status)
- Network info panel

---

### `GET /time`
**Description**: Get current clock time and status

**Response**:
```json
{
  "hour": 14,
  "minute": 32,
  "second": 18,
  "ntpSynced": true,
  "wifi": true,
  "ip": "192.0.2.100"
}
```

**Polling**: Web UI polls this every 1 second

---

### `GET /temperature`
**Description**: Get temperature sensor reading (future)

**Response** (when sensor available):
```json
{
  "available": true,
  "celsius": 22.5
}
```

**Response** (when sensor not available):
```json
{
  "available": false
}
```

**Note**: Currently placeholder. BME280/SHT31 sensor not yet implemented.

---

### `GET /lux`
**Description**: Get ambient light sensor reading

**Response** (when VEML7700 available):
```json
{
  "available": true,
  "lux": 123.4,
  "autoBrightness": 150
}
```

**Response** (when sensor not available):
```json
{
  "available": false
}
```

**Polling**: Web UI polls this every 2 seconds when auto-brightness mode active

**Fields**:
- `lux`: Current light level (0-120,000 lux range, auto-gain)
- `autoBrightness`: Calculated brightness value (0-255) based on logarithmic curve

---

### `GET /lux/override`
**Description**: Diagnostic lux override -- pin the sensor to any value so the brightness response can be swept remotely, or release it back to the real sensor

**Parameters** (query string, one required):
- `lux` (float, >= 0): hold the sensor at this value
- `clear` (any value): release the override

**Response**:
- `{"override":true,"lux":42.0}` when set
- `{"override":false}` when cleared
- `{"available":false}` when no sensor
- `400 {"error":"need ?lux=X or ?clear=1"}` when neither parameter given

---

### `GET /net`
**Description**: Get network information

**Response**:
```json
{
  "hostname": "esp32c3-v3-8inch",
  "ssid": "YOUR_SSID",
  "ip": "192.0.2.100",
  "gateway": "192.0.2.1",
  "subnet": "255.255.255.0",
  "dns": "192.0.2.1",
  "rssi": -45,
  "status": 3
}
```

**Fields**:
- `rssi`: WiFi signal strength in dBm (typical range: -30 to -80)
- `status`: WiFi connection status code (3 = WL_CONNECTED)

---

### `GET /diag`
**Description**: One-call diagnostics: uptime, firmware and settings version, time, NTP state, WiFi state, lux and the full brightness chain, ring levels, power-limiter state, animation state, timezone, save count

**Response fields** (JSON): `uptime_sec`, `firmware_version`, `settings_version`, `time`, `ntp_synced`, `ntp_last_delta_sec`, `wifi_status`, `wifi_ssid`, `wifi_rssi`, `wifi_ip`, `lux`, `brightness_target`, `brightness_ramped`, `effective_brightness`, `outer_marker_level`, `outer_filler_level`, `hours_level`, `middle_hour_level`, `inner_hour_level`, `center_level`, `middle_ambient_scale`, `inner_ambient_scale`, `button_event_count`, `free_heap`, `clock_pixel_count`, `ring_pixel_offset`, `default_outer_ring_offset`, `outer_ring_offset`, `anim_phase`, `last_anim_source`, `last_anim_mode`, `display_sleep`, `reel_active`, `master_fade`, `est_milliamps`, `limiter_brightness`, `max_milliamps`, `timezone`, `settings_save_count`

`effective_brightness` is computed through the same `autoSpanMap()` the renderer uses, so `/diag` can never disagree with what the LEDs are doing.

---

### `GET /settings`
**Description**: Get all current settings

**Response** (all keys, values are examples):
```json
{
  "dayBrightness": 44,
  "nightBrightness": 5,
  "nightStartHour": 22,
  "nightEndHour": 7,
  "centerSource": 0,
  "secondTrail": 0,
  "progressSeconds": 0,
  "hourlyChime": 1,
  "statusAnimations": 1,
  "outerMarkerColor": "#6EB9FF",
  "outerMarkerLevel": 225,
  "outerFillerColor": "#0008C8",
  "outerFillerLevel": 145,
  "secondsColor": "#64FFB4",
  "secondsLevel": 230,
  "minutesColor": "#FF6400",
  "minutesLevel": 220,
  "hoursColor": "#DC00B4",
  "hoursLevel": 255,
  "middleFaceColor": "#DC00B4",
  "innerFaceColor": "#FF3C00",
  "innerHourColor": "#6EB9FF",
  "innerHourLevel": 255,
  "centerColor": "#FF3C00",
  "centerLevel": 180,
  "autoBrightnessMode": 1,
  "minAutoBrightness": 10,
  "maxAutoBrightness": 153,
  "quarterAnimation": 3,
  "halfHourAnimation": 1,
  "hourAnimation": 4,
  "intervalAnimationsEnabled": 1,
  "focusReminder_enabled": 0,
  "focusReminder_startHour": 8,
  "focusReminder_endHour": 22,
  "focusReminder_intervalMinutes": 60,
  "focusReminder_daysMask": 0,
  "focusReminder_animation": 0,
  "focusReminder_durationSeconds": 60,
  "outerRingOffset": 0,
  "animationPalette": 7,
  "animationSpeed": 3,
  "animationBrightness": 157,
  "trailLength": 6,
  "reminderPalette": 0,
  "outerRingBrightness": 77,
  "middleFaceScale": 39,
  "innerFaceScale": 39,
  "darkRoomOff": 0,
  "secondTrailLength": 4,
  "secondTrailStyle": 2,
  "progressLevel": 90,
  "progressStyle": 0,
  "petalDepth": 45,
  "timezone": "MST7MDT,M3.2.0,M11.1.0",
  "tzConfigured": true,
  "hasUserDefaults": false
}
```

**Color format**: Hex RGB (`#RRGGBB`)
**Level values**: 0-255 (brightness intensity for each element)
**Mode enums**: See Settings Structure section below
**`tzConfigured`** (v2.31.0): read-only. `true` once a time zone has been saved to NVS; drives the first-run timezone banner in the web UI. `POST /settings` does not accept it -- strip it before re-POSTing a saved settings backup.

---

### `GET /anim/status`
**Description**: Whether an animation is currently playing, and which phase. Lets an external sequencer (the demo reel designer's Live Run) event-pace triggers instead of guessing wall-clock durations.

**Response**: `{"animating":true,"phase":"HR2"}`

**CORS**: This is the one CORS-open endpoint (`Access-Control-Allow-Origin: *`) -- read-only status, no side effects, and the designer tool runs from a different origin.

---

### `GET /wifi`
**Description**: WiFi settings page (HTML). Shows the saved SSID and current connection status; form posts to `POST /wifi`.

---

### `GET /update`
**Description**: Firmware update page (HTML). Shows the running firmware version and accepts a `.bin` upload via `POST /update`.

---

### `GET /demo/status`
**Description**: Demo mode state for the web UI and overlay

**Response** (running): `active`, `preroll` (bool), `preroll_ms` (remaining pre-roll, when pre-rolling), `step`, `steps`, `subtitle`, `elapsed_ms`, `step_duration_ms`
**Response** (idle): `{"active":false}`

---

### `GET /demo/overlay`
**Description**: Full-screen 1920x1080 OBS-ready browser source (HTML) with fade transitions; mirrors `/demo/status` subtitles. Stays blank during pre-roll so no subtitle is composited onto the black lead-in.

---

## POST Endpoints

### `POST /set`
**Description**: Manually set clock time

**Parameters** (application/x-www-form-urlencoded):
- `hour` (int, 0-23, required)
- `minute` (int, 0-59, required)
- `second` (int, 0-59, required)

**Example**:
```
POST /set
Content-Type: application/x-www-form-urlencoded

hour=14&minute=30&second=0
```

**Response**: `200 OK "ok"` or `400 Bad Request "missing hour/minute/second"`

**Side effects**: Triggers STATUS_TIME_SYNC animation (1.2 sec)

---

### `POST /syncBrowser`
**Description**: Sync clock to browser's local time

**Parameters** (application/x-www-form-urlencoded):
- `hour` (int, 0-23, required)
- `minute` (int, 0-59, required)
- `second` (int, 0-59, required)

**Example**:
```javascript
const d = new Date();
fetch('/syncBrowser', {
  method: 'POST',
  headers: {'Content-Type': 'application/x-www-form-urlencoded'},
  body: `hour=${d.getHours()}&minute=${d.getMinutes()}&second=${d.getSeconds()}`
});
```

**Response**: `200 OK "ok"` or `400 Bad Request "missing hour/minute/second"`

**Side effects**: Triggers STATUS_TIME_SYNC animation (1.5 sec)

---

### `POST /syncNtp`
**Description**: Force immediate NTP time sync

**Parameters**: None

**Response**: `200 OK "ok"` or `503 Service Unavailable "ntp unavailable"`

**Side effects**:
- Triggers STATUS_TIME_SYNC animation (1.5 sec) on success
- Triggers STATUS_WIFI_FAIL animation (1.5 sec) on failure

**Failure conditions**:
- WiFi not connected
- NTP server unreachable
- Time received is before cutoff (< Jan 2024)

---

### `POST /addMinute`
**Description**: Increment time by 1 minute

**Parameters**: None

**Response**: `200 OK "ok"`

**Side effects**: Triggers STATUS_BUTTON animation (0.7 sec)

---

### `POST /subMinute`
**Description**: Decrement time by 1 minute

**Parameters**: None

**Response**: `200 OK "ok"`

**Side effects**: Triggers STATUS_BUTTON animation (0.7 sec)

---

### `POST /previewAnimation`
**Description**: Fire an animation immediately for preview -- does not modify saved settings

**Parameters** (application/x-www-form-urlencoded):
- `type` (string, required): `quarter` | `halfhour` | `hour` | `reminder`
- `mode` (int, required): animation index within the type
  - `quarter`: 1-3
  - `halfhour`: 1-3
  - `hour`: 1-5
  - `reminder`: 0-11

**Optional style overrides** (non-persistent, apply to this preview only, auto-cleared when the animation ends):
- `palette` (0-3 moods, 7 = clock colors)
- `speed` (1-5)
- `brightness` (50-255)
- `trail` (2-12)
- `reminderPalette` (0-3 moods, 7 = clock colors)

**Example**:
```
POST /previewAnimation
Content-Type: application/x-www-form-urlencoded

type=hour&mode=4
```

**Response**: `200 OK "ok"` | `400 Bad Request "<error>"`

**Side effects**: Triggers the specified animation on the LED rings immediately. No settings are written -- the old flow persisted the style via `POST /settings` before every preview, which cost an EEPROM flash commit per click.

---

### `POST /settings`
**Description**: Update display settings. Only keys present in the request are touched; everything else keeps its saved value.

**Parameters** (application/x-www-form-urlencoded, all optional):

**Brightness**:
- `dayBrightness` (int, 0-255)
- `nightBrightness` (int, 0-255)
- `nightStartHour` (int, 0-23)
- `nightEndHour` (int, 0-23)

**Display**:
- `centerSource` (int, 0-4: 0=status + bloom breathing, 1=bloom only, 2=status only, 3=temperature when a sensor exists, 4=off)
- `secondTrail` (int, 0-1)
- `progressSeconds` (int, 0-1)
- `hourlyChime` (int, 0-1)
- `statusAnimations` (int, 0-1)

**Ring Colors** (hex format `#RRGGBB`):
- `outerMarkerColor`, `outerFillerColor`, `secondsColor`, `minutesColor`, `hoursColor`, `middleFaceColor`, `innerFaceColor`, `innerHourColor`, `centerColor`

**Ring Levels** (int, 0-255):
- `outerMarkerLevel`, `outerFillerLevel`, `secondsLevel`, `minutesLevel`, `hoursLevel`, `innerHourLevel`, `centerLevel`

**Auto-Brightness**:
- `autoBrightnessMode` (int, 0-2: 0=manual, 1=auto, 2=scheduled)
- `minAutoBrightness` (int, 5-255) -- the Darkest slider
- `maxAutoBrightness` (int, 5-255) -- the Brightest slider

**Time-Interval Animations**:
- `quarterAnimation` (int, 0-3: 0=off, 1=Slow comet, 2=Dual orbit, 3=Bloom ripple)
- `halfHourAnimation` (int, 0-3: 0=off, 1=Unfurl, 2=Three comets, 3=Breathe)
- `hourAnimation` (int, 0-5: 0=off, 1=Ceremony, 2=Galaxy spin, 3=Supernova, 4=Comet relay, 5=Deep breath)
- `intervalAnimationsEnabled` (int, 0-1)

**Animation Style**:
- `animationPalette` (int; shared 5-option list, v2.27.0: `0`=Golden hour (warm), `1`=Moonlight (cool), `2`=Dawn (soft-warm), `3`=Twilight (muted-cool), `7`=Clock colors -- default. Any other value is coerced to `7`. Moods live in `tools/palettes/palettes.json` `mood_palettes`; `7` is ring-mapped from the face colors in firmware)
- `animationSpeed` (int, 1-5: 1=slow, 3=normal, 5=fast)
- `animationBrightness` (int, 50-255)
- `trailLength` (int, 2-12)
- `reminderPalette` (int; **same** 5-option list as `animationPalette`: `0-3` moods, `7`=Clock colors. Independent of `animationPalette` so a nudge can read differently from a chime)

**Focus Reminders**:
- `focusReminder_enabled` (int, 0-1)
- `focusReminder_startHour` (int, 0-23)
- `focusReminder_endHour` (int, 0-23) -- start == end is treated as an always-on 24h window (v2.31.0)
- `focusReminder_intervalMinutes` (int, 1-1440)
- `focusReminder_daysMask` (int, 0-127: bitmask Sun=bit0 .. Sat=bit6)
- `focusReminder_animation` (int, 0-11: 0-5 delegate to the chime animation slots, 6-11 dedicated nudges)
- `focusReminder_durationSeconds` (int, 1-60) -- **reserved**: accepted and stored, not yet used by the firmware

**Face / ring tuning**:
- `outerRingOffset` (int, 0-59: clockwise LED rotation applied to all rings at render time)
- `outerRingBrightness` (int, 0-100: percent multiplier on outer ring colors)
- `middleFaceScale` (int, 0-255: middle ring ambient level)
- `innerFaceScale` (int, 0-255: inner ring ambient level)
- `darkRoomOff` (int, 0-1: blank all LEDs in a pitch-black room, auto mode only)
- `petalDepth` (int, 0-100: how deeply ring fills are shaded between petals; 0 = flat fill). Legacy `petalMode` (0/1) is still accepted as an alias when `petalDepth` is absent, so custom themes saved before v2.30.0 keep their texture.

**Second-hand accessories**:
- `secondTrailLength` (int, 2-12)
- `secondTrailStyle` (int, 0-2: 0=classic geometric, 1=linear, 2=smooth gamma comet)
- `progressLevel` (int, 0-255: tint strength of the progress arc)
- `progressStyle` (int, 0-1: 0=uniform arc, 1=comet gradient)

**Timezone**:
- `timezone` (string, POSIX TZ, e.g. `MST7MDT,M3.2.0,M11.1.0`). Not a `ClockSettings` field -- it lives in NVS. An invalid string returns `400` and nothing is saved.

**Misc**:
- `silent` (any value): suppress the settings-saved status animation

**Example**:
```
POST /settings
Content-Type: application/x-www-form-urlencoded

dayBrightness=200&nightBrightness=20&autoBrightnessMode=1&secondsColor=#FF0000
```

**Response**: `200 OK "ok"` | `400 Bad Request` (invalid timezone) | `503 Service Unavailable` (firmware update in progress -- settings are locked so a flash write cannot collide with the OTA partition write)

**Side effects**:
- Settings saved to EEPROM
- Triggers STATUS_SETTINGS_SAVED animation (1.3 sec) unless `silent`
- Clock display updates immediately with new colors/brightness

---

### `POST /settings/preview`
**Description**: Non-persistent "Preview on clock": render the posted settings for a short TTL with no EEPROM write, then auto-revert to the saved face. Safe during OTA. Same parameter set as `POST /settings`.

**Extra parameter**: `ttl` (int, ms, optional; default 10000, clamped 1000-30000)

**Response**: `200 OK "ok"`

---

### `POST /settings/preview/clear`
**Description**: Cancel an in-flight preview and return to the saved face immediately

**Response**: `200 OK "ok"`

---

### `POST /settings/reset`
**Description**: Reset settings to defaults (user-saved defaults if present, else factory)

**Response**: `200 OK "ok"` | `503` during a firmware update

---

### `POST /settings/saveDefault`
**Description**: Save the current settings as the user defaults (second EEPROM slot at offset 128, magic 0xD2). `POST /settings/reset` restores this set from then on.

**Response**: `200 OK "ok"` | `503` during a firmware update

---

### `POST /reel/begin`
**Description**: Latch demo-reel Live Run mode: the live clock face is not drawn between previewed animations (black instead) and the device generates gentle cross-dissolves itself off each animation's start/end edges

**Parameters**: `ms` (int, optional; default 8000, clamped 2000-20000) -- idle crash-guard: if nothing animates for this long the clock returns to its face on its own, so a closed or crashed browser can never strand it black

**Response**: `200 OK "ok"`

---

### `POST /reel/end`
**Description**: End reel mode: gently dissolve back to the live clock face

**Response**: `200 OK "ok"`

---

### `POST /wifi`
**Description**: Save WiFi credentials from the `/wifi` page and reconnect

**Parameters**: `ssid` (string, 1-32 chars, required), `pass` (string)

**Response**: `200 OK "Saved. Reconnecting to <ssid>..."` | `400` on bad SSID length

---

### `POST /update`
**Description**: Upload a firmware `.bin` (multipart form upload from the `/update` page). Streams chunks to the OTA partition, verifies, reboots on success.

**Response**: `200` "Update successful, rebooting..." | `400` "No update in progress" | `413` "File too large" | `500` on begin/write/end failure

---

### `POST /demo/start`
**Description**: Start the demo reel (video recording sequence)

**Parameters**: `delay` (int, seconds, optional, clamped 0-60) -- capture pre-roll: holds the clock fully dark before the reel opens, so a camera can be rolling and settled and frame one is a fade-up out of clean black. Handled on-device, so the countdown survives the browser tab closing.

**Response**: `200 {"status":"started"}`

---

### `POST /demo/stop`
**Description**: Stop the demo reel immediately

**Response**: `200 {"status":"stopped"}`

---

### `POST /demo/brightnessCycle`
**Description**: Run only the auto-brightness demo cycle (lux override sweep), standalone

**Parameters**: `ms` (int, optional; default 14000) -- cycle duration

**Response**: `200 {"status":"started"}`

---

## Settings Structure (EEPROM, SETTINGS_VERSION 19)

### ClockSettings Struct

Regenerated from `src/main.cpp` (`struct ClockSettings`, `SETTINGS_VERSION = 19`). Field order below is the EEPROM layout order.

```cpp
struct ClockSettings {
  uint8_t magic;                    // 0xC1 (validation byte)
  uint8_t version;                  // 19 (SETTINGS_VERSION)

  // Brightness
  uint8_t dayBrightness;            // 0-255, default 44
  uint8_t nightBrightness;          // 0-255, default 5
  uint8_t nightStartHour;           // 0-23, default 22
  uint8_t nightEndHour;             // 0-23, default 7

  // Display
  uint8_t centerSource;             // 0-4: what the center LED shows when idle
                                    // (0=status+bloom, 1=bloom, 2=status, 3=temperature
                                    // when a sensor exists, 4=off). Reuses the EEPROM
                                    // byte of the retired colorTheme field.
  uint8_t secondTrail;              // 0-1 (tints over the face since v16)
  uint8_t progressSeconds;          // 0-1 (tints over the face since v16)
  uint8_t hourlyChime;              // 0-1, default 1
  uint8_t statusAnimations;         // 0-1, default 1

  // Ring colors. Note middleFace and innerFace are RGB only (their levels are
  // the *FaceScale fields further down); the rest are RGB + level.
  uint8_t outerMarkerRed, outerMarkerGreen, outerMarkerBlue, outerMarkerLevel;
  uint8_t outerFillerRed, outerFillerGreen, outerFillerBlue, outerFillerLevel;
  uint8_t secondsRed, secondsGreen, secondsBlue, secondsLevel;
  uint8_t minutesRed, minutesGreen, minutesBlue, minutesLevel;
  uint8_t hoursRed, hoursGreen, hoursBlue, hoursLevel;          // middle 24h hand
  uint8_t middleFaceRed, middleFaceGreen, middleFaceBlue;       // middle ring ambient
  uint8_t innerFaceRed, innerFaceGreen, innerFaceBlue;          // inner ring ambient
  uint8_t innerHourRed, innerHourGreen, innerHourBlue, innerHourLevel; // inner 12h hand
  uint8_t centerRed, centerGreen, centerBlue, centerLevel;

  // Auto-brightness
  uint8_t autoBrightnessMode;       // 0=manual, 1=auto, 2=scheduled; default 1
  uint8_t minAutoBrightness;        // 5-255 (Darkest), default 10
  uint8_t maxAutoBrightness;        // 5-255 (Brightest), default 153

  // Time-interval animations
  uint8_t quarterAnimation;         // 0-3, default 3 (Bloom Ripple)
  uint8_t halfHourAnimation;        // 0-3, default 1 (Unfurl)
  uint8_t hourAnimation;            // 0-5, default 4 (Comet Relay)
  uint8_t intervalAnimationsEnabled; // 0-1, default 1

  // Focus Reminders (added v8)
  uint8_t  focusReminder_enabled;         // 0-1, default 0
  uint8_t  focusReminder_startHour;       // 0-23, default 8
  uint8_t  focusReminder_endHour;         // 0-23, default 22
  uint16_t focusReminder_intervalMinutes; // 1-1440, default 60
  uint8_t  focusReminder_daysMask;        // bitmask Sun(bit0)..Sat(bit6)
                                          // (factory default becomes all days in v2.31.0)
  uint8_t  focusReminder_animation;       // 0-11: 0-5 reuse the chime anims,
                                          // 6-11 dedicated nudges
  uint8_t  focusReminder_durationSeconds; // 1-60. RESERVED: accepted via POST
                                          // /settings and stored, but not yet
                                          // used by the firmware.
  uint32_t focusReminder_lastFireMs;      // INTERNAL: RAM-only bookkeeping,
                                          // ignore it. Never meaningfully
                                          // persisted; not settable.

  // Ring rotation (added v10)
  uint8_t outerRingOffset;          // 0-59: clockwise LED rotation, all rings

  // Animation customization (added v11)
  uint8_t animationPalette;         // 0-3 moods, 7=Clock colors (default); others coerce to 7
  uint8_t animationSpeed;           // 1-5, default 3
  uint8_t animationBrightness;      // 50-255, default 157
  uint8_t trailLength;              // 2-12, default 6
  uint8_t reminderPalette;          // same 5-option list, independent of animationPalette

  // Face tuning (added v12-v14)
  uint8_t outerRingBrightness;      // 0-100 percent, default 77
  uint8_t middleFaceScale;          // 0-255, default 39
  uint8_t innerFaceScale;           // 0-255, default 39

  uint8_t darkRoomOff;              // 0-1 (added v15), default 0

  // Second-hand accessory tuning (added v16)
  uint8_t secondTrailLength;        // 2-12, default 4
  uint8_t secondTrailStyle;         // 0-2, default 2 (smooth)
  uint8_t progressLevel;            // 0-255, default 90
  uint8_t progressStyle;            // 0-1, default 0 (uniform)

  // Petal depth (added v17 as an on/off flag, widened to 0-100 in v19)
  uint8_t petalDepth;               // 0-100, default 45. 0 = flat fill.

  // RETIRED (v19): held autoBrightnessGain (v18). Folded into
  // maxAutoBrightness on migration; byte kept zeroed to preserve the layout.
  uint8_t reservedGain;
};
```

**EEPROM window**: 256 bytes total. Main slot at offset 0 (magic 0xC1); user-saved defaults slot at offset 128 (magic 0xD2, written by `POST /settings/saveDefault`). Compile-time static_asserts guard both boundaries.

**Not in the struct**: the timezone (NVS, `clock`/`tz`) and WiFi credentials (NVS, `wifi` namespace). Neither is touched by settings migrations or factory reset of the struct.

### Default Values

`SettingsStore::defaults()` in `src/main.cpp` is authoritative -- the values below were read from it at settings v19 and are the ChronoBloom theme:

**Brightness**:
- Day: 44 (~17%), Night: 5 (~2%), night schedule 22:00-07:00
- Auto: mode 1 (sensor), Darkest 10, Brightest 153 (the same daylight peak the pre-v19 defaults produced)

**Colors** (RGB @ level):
- Outer marker: periwinkle blue (110, 185, 255) @ 225
- Outer filler: deep royal blue (0, 8, 200) @ 145
- Seconds: mint green (100, 255, 180) @ 230
- Minutes: orange (255, 100, 0) @ 220
- Hours (middle hand): hot pink/magenta (220, 0, 180) @ 255
- Middle face: hot pink (220, 0, 180), scale 39
- Inner face: warm orange (255, 60, 0), scale 39
- Inner hour hand: periwinkle (110, 185, 255) @ 255 (v2.30.1 -- was magenta, zero hue contrast against the middle hand)
- Center: warm orange-red (255, 60, 0) @ 180

**Animations** (factory defaults):
- Quarter-hour: Bloom Ripple (mode 3), Half-hour: Unfurl (mode 1), Top of hour: Comet Relay (mode 4), interval animations enabled
- Style: palette 7 (Clock colors), speed 3, brightness 157, trail 6; reminder palette 0 (Golden hour)
- Petal depth: 45

---

## Error Responses

### `400 Bad Request`
**Causes**:
- Missing required parameters
- Invalid parameter format
- Out-of-range values
- Invalid POSIX timezone string on `POST /settings`

**Example**: `POST /set` without `hour` parameter returns:
```
400 Bad Request
missing hour/minute/second
```

### `503 Service Unavailable`
**Causes**:
- NTP sync requested but WiFi disconnected, NTP unreachable, or time invalid (`POST /syncNtp`)
- Settings write requested while a firmware update is running (`POST /settings`, `/settings/reset`, `/settings/saveDefault` all answer `Firmware update in progress -- settings locked`; a flash commit mid-OTA can corrupt the half-written image)

---

## CORS & Security

**CORS**: `GET /anim/status` is CORS-open (`Access-Control-Allow-Origin: *`; read-only, no side effects). Every other endpoint is same-origin only.

**Authentication**: None. Anyone on the local network can access all endpoints.

**Rate limiting**: None. Endpoints can be called unlimited times.

**Future considerations**:
- Basic authentication for `/settings` POST
- Rate limiting for NTP sync (max 1/minute)
- API key for external integrations

---

## WebSocket Support

**Status**: Not implemented

**Future**: Live time updates could use WebSocket instead of 1-second polling to reduce HTTP overhead.

---

## MQTT Topics (Future)

**When MQTT support added**:

> Note: topic prefix `chronobloom-clock` below is the planned firmware identifier. Final topic names will be confirmed when MQTT is implemented.

**Subscribe** (commands from Home Assistant):
- `chronobloom-clock/command/brightness` -- Set brightness (0-255)
- `chronobloom-clock/command/mode` -- Set display mode
- `chronobloom-clock/command/animation` -- Trigger specific animation

**Publish** (state to Home Assistant):
- `chronobloom-clock/state` -- Current time, brightness, mode (JSON)
- `chronobloom-clock/sensor/lux` -- Ambient light level
- `chronobloom-clock/sensor/temperature` -- Temperature (when sensor added)

---

## Client Libraries

### JavaScript (Web UI)

**Fetch time**:
```javascript
const response = await fetch('/time');
const data = await response.json();
console.log(`Current time: ${data.hour}:${data.minute}:${data.second}`);
```

**Save settings**:
```javascript
const params = new URLSearchParams();
params.set('dayBrightness', 200);
params.set('secondsColor', '#FF0000');

await fetch('/settings', {
  method: 'POST',
  headers: {'Content-Type': 'application/x-www-form-urlencoded'},
  body: params.toString()
});
```

### Python (Home Automation)

**Get current time**:
```python
import requests

response = requests.get('http://esp32c3-v3-8inch.local/time')
data = response.json()
print(f"Current time: {data['hour']}:{data['minute']}:{data['second']}")
```

**Set brightness**:
```python
requests.post('http://esp32c3-v3-8inch.local/settings', data={
  'dayBrightness': 200,
  'nightBrightness': 10
})
```

### Curl (Command Line)

**Sync to NTP**:
```bash
curl -X POST http://esp32c3-v3-8inch.local/syncNtp
```

**Get diagnostics**:
```bash
curl http://esp32c3-v3-8inch.local/diag
```

**Set time**:
```bash
curl -X POST http://esp32c3-v3-8inch.local/set \
  -d "hour=14&minute=30&second=0"
```

---

## WiFi Provisioning

### First-Boot Portal

**Behavior**:
- On first boot, if no saved WiFi credentials exist, the device first listens for Improv WiFi over USB serial (bounded window, used by the browser flasher), then opens a WiFi access point
- SSID: `esp32c3-clock-setup` (no password required)
- IP address: `192.168.4.1`
- Portal window (v2.31.0): 10 minutes on a never-provisioned first boot, 2 minutes on a previously-connected unit, 15 minutes after factory reset (then falls through to AP mode)

### WiFi AP Fallback

If all STA connection attempts fail (wrong password, network unavailable), the device starts a software AP and runs the full web server at `192.168.4.1`. Clock display, web UI, and settings are all functional in AP mode. NTP, mDNS, and OTA are skipped until a STA connection is established. While nobody is connected to the setup AP, the device retries the known credentials every 5 minutes and reboots into normal mode on success.

**Portal page**:
1. Displays list of available WiFi networks (SSIDs)
2. User selects their SSID and enters password
3. Device stores credentials (WiFiManager library manages storage)
4. Device connects to saved network
5. Portal closes automatically

**Credential Storage**:
- WiFi SSID and password stored in NVS (separate from clock settings)
- Persists across reboots
- Can also be changed any time via the `/wifi` page

**Error Handling**:
- If the portal window closes without credentials, the portal reappears on next boot
- Invalid credentials (password changed in router): portal reappears on next boot
- WiFi network unavailable: portal reappears on next boot

---

## OTA (Over-The-Air) Firmware Updates

### Overview

After initial USB flash, firmware updates can be deployed over WiFi using ArduinoOTA protocol on port 3232, or by uploading a `.bin` on the `/update` page.

### OTA Protocol Details

**Port**: 3232 (TCP)
**Authentication**: None. Current firmware calls `ArduinoOTA.begin()` without a password; OTA is open to the local network.
**Protocol**: ArduinoOTA binary protocol (not HTTP/HTTPS)

### Update Command

```powershell
# Build new firmware
pio run -e esp32c3_v3_8inch

# Upload via OTA to device at mDNS hostname
pio run -e esp32c3_v3_8inch -t upload --upload-port esp32c3-v3-8inch.local:3232

# Or upload to device by IP address
pio run -e esp32c3_v3_8inch -t upload --upload-port 192.0.2.100:3232
```

### Update Flow

1. **Build phase**: PlatformIO compiles firmware (.bin file)
2. **Connection phase**: PlatformIO connects to device on port 3232
3. **Upload phase**: Binary streamed to device (shows progress % in serial monitor if connected)
4. **Flash phase**: Device writes new firmware to flash memory
5. **Verify phase**: Device verifies flash integrity
6. **Reboot phase**: Device automatically reboots with new firmware
7. **Status animations**:
   - During upload: inner ring shows blue
   - On success: inner ring shows green
   - On failure: inner ring shows red

### Status Indicators

**Serial output during OTA**:
```
[OTA] Update starting...
[OTA] Progress: 45000/703962 (6.4%)
[OTA] Progress: 90000/703962 (12.8%)
...
[OTA] Update complete, rebooting...
```

### Troubleshooting OTA

**Port 3232 not responding**:
- Device must be on WiFi (test with `ping esp32c3-v3-8inch.local`)
- Check firewall: port 3232 may be blocked
- Restart device and try again (OTA server initializes ~30-60s after boot)
- Verify mDNS is working: ping should resolve hostname to IP

**Network interruption during upload**:
- Blue animation stops, device may reboot
- Try again with stronger WiFi signal (move closer to router)
- Check router is not dropping connection on specific devices

**Authentication failure**:
- Current firmware sets no OTA password, so an auth failure means the device is still running an older build that did
- Reflash once over USB (or the `/update` page) to bring it to the current firmware

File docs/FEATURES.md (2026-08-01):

# ChronoBloom ESP32-C3 -- Feature Catalog

## Current Features (Implemented ✅)

### Time Display
- ✅ **Analog 3-ring clock** -- Hours/minutes/seconds shown via LED position
- ✅ **Per-ring color customization** -- RGB color pickers for 9 elements (outer marker, outer fill, seconds, minutes, hours, middle face, inner face, inner hour, center)
- ✅ **Per-ring brightness control** -- Independent intensity sliders (0-255)
- ✅ **Quarter-hour markers** -- Every 5th LED on outer ring
- ✅ **Progress fill** -- Dim arc showing seconds elapsed
- ✅ **Fading trail** -- 4-LED trail behind second hand
- ✅ **Petal depth on all three rings** (v2.30.0) -- one 0-100 slider shades every ring's fill with the same crest-to-seam profile, so the face reads as rows of petals instead of flat glow. Crests align into four radial spokes at 12/3/6/9; the outer ring's 5-minute markers are never shaded so the hour marks stay crisp. 0 = flat fill (the old off). Per-theme depths ship in `tools/themes/themes.json`
- ✅ **Center status pixel** -- Breathing idle animation, status indicator

### Brightness Control
- ✅ **Manual brightness** -- Day/night sliders
- ✅ **Scheduled brightness** -- Auto-switch at configurable hours
- ✅ **VEML7700 auto-brightness** -- Lux-based logarithmic curve
- ✅ **Three modes** -- Manual / Auto (sensor) / Scheduled (day/night)
- ✅ **Two-slider auto response: Darkest / Brightest** (v2.30.0) -- the lux curve is span-mapped onto exactly [Darkest..Brightest]: pitch black lands on the Darkest slider, full daylight on the Brightest slider, and neither can be silently defeated. Replaces the retired v18 "Overall dimness" gain, whose label read backwards and whose pre-clamp multiply could pin the face at the floor with the sensor ignored. Migration folds the stored gain into Brightest so no deployed unit's daylight peak jumps
- ✅ **Dark-room display sleep** (v2.5.0) -- Auto mode + `darkRoomOff`: 30 s below 0.3 lux blanks all LEDs, wakes above 2.0 lux

### Animations
- ✅ **Hourly chime** -- Sweep + center pulse (8 sec)
- ✅ **Status animations** -- WiFi connect, button press, NTP sync, settings save
- ✅ **Center idle breathing** -- Slow pulse when no status active
- ✅ **Time-interval animations** -- Escalating intensity at :15/:30/:00 (v2.4.0 overhaul: 29 legacy modes replaced with 16 palette-aware animations)
  - Quarter-hour (:15/:45, modes 1-3): Slow comet, Dual orbit, Bloom ripple
  - Half-hour (:30, modes 1-3): Unfurl, Three comets, Breathe
  - Top of hour (:00, modes 1-5): Ceremony, Galaxy spin, Supernova, Comet relay, Deep breath
- ✅ **Animation palette system** (simplified v2.27.0) -- **one shared 5-option list** applies to both interval chimes and reminders: `Clock colors (default)` (ring-mapped from the configured face colors) + 4 temperature/mood palettes **Golden hour (warm)**, **Moonlight (cool)**, **Dawn (soft-warm)**, **Twilight (muted-cool)**. Each mood is **four explicit per-ring colors** (outer/middle/inner/center) rendered solid per ring -- the same model as Clock colors. Since v2.31.1 each mood **travels hue from ring to ring** (outer rim to center core) while brightening inward; before that they were single-hue lightness ramps, which made every bloom animation read as one flat wash. Keep the hue travel when re-tuning -- it is the point. Source of truth `tools/palettes/palettes.json` (`mood_palettes` -> `rings`) -> `tools/gen_palettes.py` -> `src/anim_palettes.h`. Values are authored **gamma-aware** (route through `gammaColor`, gamma 2.2); the `target` field records the intended on-strip appearance and `rings` is its inverse-gamma. Try candidates on a live clock without flashing via `scripts/tune_palette.py`. The 10 prior flower palettes were removed and archived (`docs/archive/flower_palettes_2026-07-14.md`)
- ✅ **Animation style controls** -- Speed (1-5), peak brightness (50-255), trail length (2-12 LEDs)
- ✅ **Reminder palette** -- an **independent selection** from the same 5-option list (Clock colors + 4 moods), so a reminder/nudge can read differently from an interval chime. Applies to every reminder-triggered animation incl. nudge modes 0-2, which delegate to the chime animations

### Smart Features
- ✅ **NTP time sync** -- Network Time Protocol with timezone/DST support
- ✅ **Runtime time zone** (v2.28.0) -- set in the web UI (Time & light -> Time zone): 18 common zones plus an "Other" field taking any POSIX TZ string. Stored in NVS (`clock`/`tz`), not in `ClockSettings`, so no settings migration; `NTP_TIMEZONE_TZ` in `platformio.ini` is only the default for a fresh or factory-reset unit. Applies immediately with no reboot and no NTP round trip, since the ESP keeps the system clock in UTC and only `tzset()` has to re-run. Rejected strings return 400 rather than silently meaning UTC
- ✅ **First-run timezone banner** (v2.31.0) -- a freshly flashed clock prompts for its time zone in the web UI instead of silently running in the build default, so the first thing a new builder sees is the right time
- ✅ **Time-truth cue** (v2.31.0) -- until NTP syncs or the time is set by hand, a short amber inner-ring chase fires every 10 s, so unconfirmed time looks different from set time. Respects the status-blips toggle
- ✅ **Offline DST tick** (v2.31.0) -- local time is re-derived from the epoch once a minute while WiFi is down, so a DST change lands on time offline. Suppressed after a manual time set
- ✅ **Web UI** -- Full-featured control interface with live preview
- ✅ **Unified Save** (v2.31.0) -- the main Save button now writes the reminder and animation-style fields too, so one press covers the whole settings set. The sectional save buttons remain as conveniences. Time zone is the exception: it has its own Save zone button; the main Save does not write it
- ✅ **Browser time sync** -- One-click sync from phone/computer clock
- ✅ **EEPROM persistence** -- All settings survive power cycles (settings schema v19; see Settings Structure below)
- ✅ **WiFi web server** -- mDNS hostname (esp32c3-v3-8inch.local)
- ✅ **Live SVG preview** -- Clock updates every 90ms in web UI
- ✅ **Animation toggles** -- Enable/disable individual effects
- ✅ **Theme selection** -- 7 presets: ChronoBloom (clock default), Moonflower, Cherry Blossom, Ember Dahlia, Lotus Pond, Sunflower, Bird of Paradise. Each sets the full face color set plus animation style in one click
- ✅ **Manual time adjustment** -- H:M:S entry and +/- minute controls via WebUI
- ✅ **Improv WiFi (v2.29.0)** -- Browser-configured WiFi over USB serial at flash time (official improv-wifi/sdk-cpp protocol, `improv/Improv @ 1.2.6`). Window on an unprovisioned device before falling back to the captive portal: 10s of silence closes it, but any complete Improv frame from a browser holds it open another 60s, so the window survives a user reading the dialog and typing a password (v2.31.4). Serviced only while unprovisioned/AP-fallback, never once connected
- ✅ **WiFi provisioning portal** -- Captive portal on first boot; AP fallback at 192.168.4.1 if STA unavailable. Portal windows (v2.31.0): 10 min on a never-provisioned first boot, 2 min on a previously-connected unit, 15 min after factory reset (then falls through to AP mode)
- ✅ **OTA firmware updates** -- ArduinoOTA (espota) and web UI `/update` page; no USB cable required after first flash
- ✅ **mDNS reconnect** -- Hostname re-advertised automatically after WiFi reconnect

### Physical Buttons
- ✅ **Physical UP/DOWN buttons** -- GPIO5(UP) / GPIO9(DOWN), polled (no ISRs), 50ms debounce
  - Short press: +1/-1 minute
  - Hold >500ms: auto-repeat +1/-1 minute every 150ms
  - Hold >2000ms: switches to +60/-60 minutes per fire (hour jump)
  - Release: repeat stops immediately
  - No-WiFi time adjustment without WebUI

### Focus Reminders
- ✅ **Focus Reminders (ADHD support)** -- Visual nudge animations at configurable intervals to interrupt hyperfocus
  - Single configurable rule: interval (1-1440 min), active hours window, days-of-week bitmask
  - Modes 0-2: delegate to existing time-interval animations (quarter/half/hour slots)
  - Modes 6-11: dedicated reminder animations (Gentle pulse, Orbiting orb, Ripple in, Heartbeat, Slow bloom, Firefly)
  - All reminder animations use the reminder palette, capped by a shared `NUDGE_CEIL` (205/255) so a nudge reads as a swell, never an alert flash -- an ask, not an alarm
  - Enable/disable toggle
  - Configurable per-day schedule (Sun-Sat)
  - **Gentle escalation** (v2.31.0) -- from the second unacknowledged nudge on, the same swell plays a second time ~6 s after the first: it asks twice, at the same brightness, never louder. Before v2.31.0 every nudge was identical and played once
  - **Button acknowledgment** (v2.31.0) -- pressing either physical button during a nudge or within ~15 s after acknowledges it: escalation clears and the interval restarts. The ack press does not adjust the time; later presses do, as usual
  - **Quick nudge control** (v2.31.0) -- a Focus nudges row in the web UI Quick controls: on/off + interval + save, two taps from landing
  - **Preset buttons** (v2.31.0) -- Pomodoro 25m / Check-in 30m / Hourly buttons in the reminder section fill the common setups in one click
  - **24h window** (v2.31.0) -- start hour == end hour now means always-on (previously a zero-width window that never fired)
  - **Factory default days: all 7** (v2.31.0) -- a fresh unit that enables reminders gets nudges immediately instead of a silently empty days mask
  - Fire timestamp stored in RAM only -- not persisted to EEPROM (field `focusReminder_lastFireMs` reserved in struct but unused since v2.1.1)
  - Web UI panel: "Focus Reminders (ADHD)"

### Demo Mode
- ✅ **Demo Mode** -- press **Demo** in the web UI and the clock plays itself: a hands-off tour through the chimes, the hour animations, the nudges and the auto-brightness range, then returns to telling the time. Good for showing someone what it does without waiting for the top of the hour. Non-blocking state machine, so the clock stays responsive throughout
  - 9-step sequence (`DemoMode::steps[]` in `src/main.cpp`): title card (8.8s), quarter chime (5.6s), half-hour chime (11s), top-of-hour chime (17s), hour animation showcase (36.5s), focus reminder nudges (20s), center LED status (6.8s), auto-brightness cycles (14.85s), open-source end card (10.85s)
  - Total runtime: ~131 seconds. The animation steps are event-paced and depend on which styles are configured, so per-step figures are estimates at `animationSpeed` 3, not exact bounds; each transition includes a ~0.8s dissolve and breather
  - LuxSensor override: simulates two quick room-darkening/brightening cycles to demo the faster (150ms poll) auto-brightness response
  - **Pre-roll** (v2.30.0): `POST /demo/start?delay=<seconds>` (0-60) holds the clock fully dark before the demo opens, so a camera can be rolling and settled and frame one is a fade-up out of clean black. Handled on-device, so the countdown survives the browser tab closing; web UI has a Pre-roll seconds box with live countdown
  - Web endpoints: `POST /demo/start`, `POST /demo/stop`, `POST /demo/brightnessCycle` (auto-brightness sweep standalone), `GET /demo/status`, `GET /demo/overlay`
  - `/demo/status` returns: active state, pre-roll state (`preroll` + `preroll_ms`), current step, subtitle, elapsed time, step duration
  - `/demo/overlay` HTML: full-screen 1920x1080, OBS-ready browser source with fade transitions; stays blank during pre-roll so no subtitle lands on the black lead-in
  - Web UI controls: Start/Stop buttons, live status display (step counter + progress bar)
  - Buttons ignored during demo; all web endpoints continue normal operation
  - No settings version change, no EEPROM impact

### Web UI Features
- ✅ **Time controls** -- Manual set, browser sync, NTP sync, increment/decrement (WebUI); physical buttons re-added v2.0.6 (GPIO5=UP, GPIO9=DOWN)
- ✅ **Display settings** -- Day/night brightness, schedule hours
- ✅ **Ring controls** -- 9 color elements: outer marker, outer fill, seconds, minutes, hours, middle face, inner face, inner hour, center (levels where applicable), plus the petal depth slider
- ✅ **Animation controls** -- Second trail, progress ring, hourly chime, status animations, interval animations, palette/speed/brightness/trail controls
- ✅ **Animation preview** -- Preview button on every animation selector; Animation Style panel with live preview by type
- ✅ **12-hour AM/PM display** -- Clock header shows 12h format with AM/PM
- ✅ **Live sensor data** -- Current lux reading updates every 2 seconds
- ✅ **Auto-brightness controls** -- Mode selection, min/max limits
- ✅ **Network info** -- IP address, WiFi SSID, signal strength, NTP sync status
- ✅ **Demo Mode controls** -- Start/Stop buttons, live status display for video recording sequences

---

## Planned Features (Priority Order)

### High Priority
- [ ] **Sunrise/sunset detection** -- VEML7700 detects daylight transitions, triggers warm fade animations
- [ ] **Holiday auto-animations** -- Date-triggered effects (Christmas, Halloween, New Year, Easter, user birthday)
- [ ] **Multiple Focus Reminder rules** -- 3-5 concurrent reminder rules

### Medium Priority
- [ ] **Theme presets** -- Save/load entire color schemes to EEPROM slots (named presets)
- [ ] **BME280 temp/humidity sensor** -- Color-coded center pixel (blue=cold, red=hot), web UI display
- [ ] **MQTT for Home Assistant** -- Publish state, subscribe to commands
- [ ] **Sunrise alarm** -- 5-minute gradual brightness increase simulating dawn
- [ ] **Pomodoro timer mode** -- 25/5 work/break visual countdown on outer ring

### Low Priority
- [ ] **Lux history graph** -- 60-minute trend chart in web UI (canvas or SVG)
- [ ] **Circadian rhythm color shift** -- Warm orange evening, cool blue morning (auto-adjusts based on lux)
- [ ] **Motion detection proxy** -- Sudden lux spike = person approaching, trigger welcome animation
- [x] **Power saving mode** -- Done v2.5.0 as dark-room display sleep (`darkRoomOff`)
- [ ] **Multi-clock network sync** -- Master/slave mode for synchronized animations across multiple clocks
- [ ] **LED mapping test mode** -- `/ledtest?pixel=N` and `/ledwalk` endpoints for physical verification
- [ ] **Animation playlist** -- Auto-rotate effects every N minutes in demo mode
- [ ] **Custom schedules** -- Different animations at different times/days
- [ ] **Voice control** -- Alexa/Google Assistant via MQTT bridge

---

## Removed Features (Was Implemented, Now Removed)

**Physical buttons (GPIO3/GPIO4)** -- removed v2.0.4, re-added v2.0.6 on safe pins
- Originally GPIO3/GPIO4 (JTAG TCK/TDI): spurious ISR fires with USB connected -> removed v2.0.4
- Re-added v2.0.6 on GPIO5(UP)/GPIO9(DOWN) using polled reads, no ISRs
- v2.0.7: GPIO swap to GPIO5=UP, GPIO9=DOWN; hold-to-repeat added (500ms->1min/150ms, 2s->60min/fire)
- See CHANGELOG [2.0.4], [2.0.6], [2.0.7] for full context

---

## Rejected Features (Do Not Implement)

### Why These Don't Fit
The clock's purpose is **elegant analog timekeeping through light and color**. The 3-ring LED topology (60/24/12) is optimized for circular time display, not general-purpose pixel matrix.

### Specific Rejections

❌ **Game modes** (Tetris/Snake/Pong)
- Requires rectangular pixel grid
- Obscures time display entirely
- Wrong use case for a clock

❌ **Text scrolling / message display**
- Insufficient pixel density (96 LEDs total)
- Ring topology makes text unreadable
- Better suited for 8x8 or larger matrices

❌ **Pixel art upload / painting interface**
- 96 LEDs in concentric circles ≠ rectangular canvas
- Can't map bitmap images to ring topology meaningfully

❌ **7-segment digital display overlay**
- Conflicts with analog aesthetic
- Would require hiding ring LEDs = wasted hardware
- If you want digital, buy a different clock

❌ **Music visualization / audio reactive mode**
- Would obscure time display during playback
- I2S mic + FFT would constantly override clock
- Dedicated LED strip projects exist for this purpose

❌ **Social media counters / stock tickers**
- This is not an information dashboard
- No way to display numbers/text clearly
- Use Tidbyt or LaMetric for this

❌ **Audio speaker mode / Bluetooth speaker**
- Feature creep beyond timekeeping
- Adds speaker hardware complexity
- Not what this project is about

❌ **E-ink companion display**
- Unnecessary complexity
- If you need date/temp text, add a separate e-ink module elsewhere

❌ **Video playback / GIF animation upload**
- 96 LEDs total, circular topology
- Cannot render video meaningfully
- Wrong hardware entirely

---

## Feature Request Guidelines

### Before Proposing a New Feature, Ask:

1. **Does it enhance timekeeping?** (Better readability, more accurate, more informative about time?)
2. **Does it use the ring topology effectively?** (Radial symmetry, position = time metaphor?)
3. **Is it visually compatible?** (Light bloom aesthetic, flower-like petal effect?)
4. **Does it stay true to analog display?** (No trying to make digital displays from circular LEDs)
5. **Is the complexity justified?** (Simple is better, don't add features just because you can)

### Good Feature Examples:
- ✅ Moon phase indicator (inner ring changes color based on lunar cycle)
- ✅ Tide indicator (for coastal users, outer ring shows high/low tide position)
- ✅ Countdown to event (outer ring fills as event approaches)
- ✅ Weather-based color themes (cloudy = gray, sunny = yellow, rainy = blue)
- ✅ Air quality indicator (center pixel color = AQI level)

### Bad Feature Examples:
- ❌ Display email notifications as scrolling text
- ❌ Play YouTube videos on the LED rings
- ❌ Cryptocurrency price charts
- ❌ Turn it into a smart speaker
- ❌ Instagram follower counter

---

## Settings Structure (EEPROM v19)

> The struct sketch below is a summary; `src/main.cpp` (`struct ClockSettings`,
> `SETTINGS_VERSION`) is authoritative -- `docs/API.md` carries the full
> regenerated field list. Additions since v11:
> `middleFace*`/`innerFace*`/`innerHour*` colors, `outerRingBrightness`,
> `middleFaceScale`, `innerFaceScale` (v12-v14), `darkRoomOff` (v15),
> `secondTrailLength`/`secondTrailStyle`/`progressLevel`/`progressStyle` (v16),
> petal flag (v17), auto-brightness gain (v18, retired), petal depth 0-100 +
> gain fold (v19). A second EEPROM slot at offset 128 stores user-saved
> defaults (v2.4.5+, magic 0xD2); compile-time static_asserts guard both
> layout boundaries.

### Stored Configuration
**Total size**: 256 bytes (main slot at 0, user-defaults slot at 128)  
**Magic byte**: 0xC1 (main), 0xD2 (user defaults)  
**Version**: 19

**Fields**:
```cpp
struct ClockSettings {
  uint8_t magic;                    // 0xC1 (validation)
  uint8_t version;                  // 19 (SETTINGS_VERSION)
  
  // Brightness
  uint8_t dayBrightness;            // 0-255
  uint8_t nightBrightness;          // 0-255
  uint8_t nightStartHour;           // 0-23
  uint8_t nightEndHour;             // 0-23
  
  // Display
  uint8_t centerSource;             // 0-4: idle center LED role (reuses the retired colorTheme byte)
  uint8_t secondTrail;              // 0=off, 1=on (tints over the face, v16)
  uint8_t progressSeconds;          // 0=off, 1=on (tints over the face, v16)
  uint8_t hourlyChime;              // 0=off, 1=on
  uint8_t statusAnimations;         // 0=off, 1=on
  
  // Ring colors (9 elements; middleFace/innerFace are RGB only -- their levels
  // are the *FaceScale fields below. Full layout in docs/API.md)
  uint8_t outerMarkerRed, outerMarkerGreen, outerMarkerBlue, outerMarkerLevel;
  uint8_t outerFillerRed, outerFillerGreen, outerFillerBlue, outerFillerLevel;
  uint8_t secondsRed, secondsGreen, secondsBlue, secondsLevel;
  uint8_t minutesRed, minutesGreen, minutesBlue, minutesLevel;
  uint8_t hoursRed, hoursGreen, hoursBlue, hoursLevel;         // middle 24h hand
  uint8_t middleFaceRed, middleFaceGreen, middleFaceBlue;      // v14
  uint8_t innerFaceRed, innerFaceGreen, innerFaceBlue;         // v14
  uint8_t innerHourRed, innerHourGreen, innerHourBlue, innerHourLevel; // v14
  uint8_t centerRed, centerGreen, centerBlue, centerLevel;
  
  // Auto-brightness (VEML7700)
  uint8_t autoBrightnessMode;       // 0=manual, 1=auto, 2=scheduled
  uint8_t minAutoBrightness;        // 5-255
  uint8_t maxAutoBrightness;        // 5-255
  
  // Time-interval animations (v2.4.0 set; higher legacy modes are sanitized away)
  uint8_t quarterAnimation;         // 0=off, 1=Slow comet, 2=Dual orbit, 3=Bloom ripple
  uint8_t halfHourAnimation;        // 0=off, 1=Unfurl, 2=Three comets, 3=Breathe
  uint8_t hourAnimation;            // 0=off, 1=Ceremony, 2=Galaxy spin, 3=Supernova, 4=Comet relay, 5=Deep breath
  uint8_t intervalAnimationsEnabled; // 0=off, 1=on

  // Focus Reminders (added v8)
  uint8_t focusReminder_enabled;             // 0=off, 1=on
  uint8_t focusReminder_startHour;           // 0-23 (active window start)
  uint8_t focusReminder_endHour;             // 0-23 (active window end)
  uint16_t focusReminder_intervalMinutes;    // 1-1440 (minutes between nudges)
  uint8_t focusReminder_daysMask;            // bitmask Sun(bit0)..Sat(bit6); factory default all days since v2.31.0
  uint8_t focusReminder_animation;           // 0-5=delegate to time anims; 6-11=dedicated reminder anims
  uint8_t focusReminder_durationSeconds;     // 1-60 (added v9). RESERVED: accepted+stored, not yet used
  uint32_t focusReminder_lastFireMs;         // INTERNAL: RAM-only bookkeeping, ignore

  // Ring rotation (added v10)
  uint8_t outerRingOffset;          // 0-59: clockwise LED rotation applied to all rings at render time

  // Animation customization (added v11)
  uint8_t animationPalette;         // Shared 5-option list (v2.27.0): 0=Golden hour(warm),1=Moonlight(cool),2=Dawn(soft-warm),3=Twilight(muted-cool),7=Clock colors (default). Other values -> 7.
  uint8_t animationSpeed;           // 1-5 (1=slow, 3=normal, 5=fast)
  uint8_t animationBrightness;      // 50-255 peak brightness during animations
  uint8_t trailLength;              // 2-12 LEDs (chase/sweep trail length; interval anims)
  uint8_t reminderPalette;          // Same 5-option list as animationPalette (v2.27.0): 0-3 moods, 7=Clock colors

  // ...outerRingBrightness, middleFaceScale, innerFaceScale (v12-14), darkRoomOff (v15)...

  // Second-hand accessory tuning (added v16)
  uint8_t secondTrailLength;        // 2-12 LEDs (clock-face second trail length)
  uint8_t secondTrailStyle;         // 0=classic geometric, 1=linear, 2=smooth (gamma comet)
  uint8_t progressLevel;            // 0-255 tint strength (alpha) of the progress arc over the face
  uint8_t progressStyle;            // 0=uniform arc, 1=comet gradient (brighter toward the second hand)

  // Petal depth (added v17 as an on/off flag, widened to 0-100 in v19)
  uint8_t petalDepth;               // 0-100 seam shading across all three rings; 0=flat fill

  // Retired v19: held autoBrightnessGain (v18); folded into maxAutoBrightness
  // on migration, byte kept zeroed to preserve the layout
  uint8_t reservedGain;
};
```

### Version History
- **v1-5**: Original ESP8266 versions (deprecated)
- **v6**: Initial ESP32-C3 release (March 2026)
- **v7**: Added VEML7700 auto-brightness + time-interval animations (May 2026)
- **v8**: Added Focus Reminders scheduler (May 2026); v7 settings auto-reset to v8 defaults on first boot
- **v9**: Added `focusReminder_durationSeconds` (animation duration 1-60s; repurposed from reserved block)
- **v10**: Added `outerRingOffset` (software ring rotation 0-59 LEDs; web UI "Ring rotation offset" control)
- **v11**: Added `animationPalette`, `animationSpeed`, `animationBrightness`, `trailLength`, `reminderPalette` (animation customization system)
- **v12**: Added per-ring face brightness (`outerRingBrightness`, `middleFaceScale`, `innerFaceScale`) -- v2.4.2
- **v13**: v2.4.4/2.4.5 era (user-saved defaults slot added alongside)
- **v14**: Split inner-ring palettes (`middleFace*`, `innerFace*`, `innerHour*` color/level fields) -- v2.4.7
- **v15**: Added `darkRoomOff` (dark-room display sleep) -- v2.5.0
- **v16**: Added `secondTrailLength`, `secondTrailStyle`, `progressLevel`, `progressStyle` (second-hand accessory tuning; trail/progress now tint over the face) -- v2.12.0. **First version bump with a prefix-preserving migration** -- deployed units keep all their settings (no wipe).
- **v17**: Added `petalMode` (petal texture on/off flag) -- v2.25.0
- **v18**: Added `autoBrightnessGain` (retired one version later; its pre-clamp multiply could pin the face at the floor) -- v2.26.0
- **v19**: `petalMode` widened to `petalDepth` (0-100, all three rings, one shared profile); gain retired to `reservedGain` (zeroed, folded into `maxAutoBrightness` on migration so no unit's daylight peak jumps). Same offsets, no struct growth, no wipe -- v2.30.0

### Bumping Settings Version
When adding fields (append at the end -- never reorder existing ones):
1. Update `ClockSettings` struct (append new fields)
2. Update `SettingsStore::defaults()` with new defaults
3. Increment `SETTINGS_VERSION` by 1
4. Add a migration branch in `SettingsStore::begin()` (see the v15->v16 case): keep the old struct prefix, seed the new fields, re-stamp the version. This preserves every existing setting -- **no wipe**. (Omitting the migration falls back to a full reset to `defaults()` on next boot, the pre-v16 behavior.)

---

## Stability / OTA Infrastructure (Maturation Track)

Target state: device is flashable, debuggable, and verifiable entirely over WiFi with
no USB cable or serial monitor required.

### Done
- ✅ **Task 2** -- `WiFi.setAutoReconnect(true)` confirmed in `setupWiFi()`
- ✅ **Task 3** -- `ArduinoOTA.onError()` calls `ESP.restart()` on stall
- ✅ **Task 4** -- Software watchdog: `esp_task_wdt` 10s window in `loop()`
- ✅ **Web UI firmware update** -- `/update` page accepts `.bin` upload; fixed FormData + `UPDATE_SIZE_UNKNOWN`

### Planned
- ✅ **Task 1** -- `/diag` endpoint: uptime, firmware version, boot reason, free heap, WiFi stats, NTP sync status, NTP last delta, button event count (2026-05-13)
- ✅ **Task 6** -- Physical buttons re-added: GPIO9(UP)/GPIO5(DOWN), polled, 50ms debounce, `ButtonInput` class (2026-05-13)
- ✅ **Task 5** -- Button-hold factory reset on boot (2026-05-13): hold UP at power-on -> red LEDs; add DOWN, hold both 3s -> clears EEPROM, blue LEDs while portal broadcasts `esp32c3-clock-setup`

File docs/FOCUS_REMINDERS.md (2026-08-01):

# Focus Reminders Guide

## What is it?
A visual interrupt built into the clock. When enabled, the rings fire a short light animation at set intervals during your chosen hours. A nudge to look up: check in, stretch, hydrate, switch tasks. It's an ask, not an alarm. Some sessions you'll blow right past it, and that's fine. The clock asks, it doesn't demand.

**Good for:** redirecting hyperfocus, pomodoro-style breaks, homework reminders, bedtime cues, leaving-the-house alerts, screen break nudges.

## Quick Start

### Fast path: Quick controls
The **Focus nudges** row in the Quick controls at the top of the page turns nudges on or off and sets the interval. Two taps from landing. Use the full section below when you want the window, days, animation, or colors.

### 1. Open WebUI
- Desktop: `http://esp32c3-v3-8inch.local` (or device IP address)
- Expand the **Motion & nudges** card (it starts collapsed)
- Scroll to the **Focus reminders (nudges)** section

### 2. Configure
- **Enable focus reminders:** Check the box
- **Start hour:** When you want nudges to begin (e.g., 08 for 8 AM)
- **End hour:** When you want them to stop (e.g., 22 for 10 PM). Same hour in both fields means a full 24-hour window (v2.31.0). End earlier than start wraps past midnight (e.g., 22 to 06).
- **Interval (min):** How often in minutes (e.g., 60 for every hour)
- **Presets:** The Pomodoro 25m, Check-in 30m, and Hourly buttons in the reminder section fill the common setups in one click
- **Days of week:** Check which days to enable (Mon-Fri for work, all days for hobby)
- **Reminder animation:** Pick the visual style. Six dedicated gentle nudges (Gentle Pulse, Orbiting Orb, Ripple In, Heartbeat, Slow Bloom, Firefly), or "Use quarter/half-hour/hour animation" to reuse one of your configured clock animations
- **Colors:** The **Reminder colors (nudges)** picker sits under Animation style in the same card. Pick a different palette there so a nudge reads differently from a chime, then click **Save style**.

### 3. Save
- Click the **Save reminder** button (since v2.31.0 the main Save button writes these fields too; Save reminder stays as a convenience)
- Settings save to device memory (persist across power-off/reboot)
- The first nudge fires as soon as the current day and hour match your window, no full-interval wait. After that the interval counts from the last fire or acknowledgment, on device uptime, not wall-clock marks like :00 or :30. A reboot restarts the cadence.

### 4. Test
- Click the preview arrow next to the Reminder animation dropdown to fire the nudge on the device right now
- Or set the clock time to within your window on a selected day; the first nudge fires as soon as the window matches
- Check Serial monitor (115200 baud) for the log: `[FocusReminder] Fired at...`

## Examples

### Pomodoro-Style (Work)
- Enable: YES
- Start: 09 (9 AM)
- End: 17 (5 PM)
- Interval: 25 (every 25 min, Pomodoro timer)
- Days: Mon-Fri
- Animation: Gentle Pulse (soft, frequent-friendly)

### Bedtime Reminder (Daily)
- Enable: YES
- Start: 21 (9 PM)
- End: 22 (10 PM)
- Interval: 10 (every 10 min for 1 hour)
- Days: All
- Animation: Heartbeat (a noticeable two-thump)

### Screen Break (Background)
- Enable: YES
- Start: 08 (8 AM)
- End: 23 (11 PM)
- Interval: 120 (every 2 hours)
- Days: All
- Animation: Slow Bloom (pretty, unhurried)

## Animation Styles

| Name | Feel | Use Case |
|---|---|---|
| **Gentle Pulse** | A slow breath with a warm hue drift | Frequent reminders (25-60 min) |
| **Orbiting Orb** | Quiet and localized: one orb on the inner ring | Background nudges you don't want to intrude |
| **Ripple In** | Rings swell inward in sequence | Moderate reminders (60-120 min) |
| **Heartbeat** | Two soft thumps | Important cues you shouldn't miss |
| **Slow Bloom** | An unhurried flower opening | Calm, meditative reminders |
| **Firefly** | An asynchronous warm twinkle swarm | Gentle but clear check-ins |

All six are capped at ~80% brightness so they read as a swell, never an alarm, and render in the reminder palette you select (Clock colors, Golden hour, Moonlight, Dawn, or Twilight). You can also pick "Use quarter/half-hour/hour animation" to fire one of your configured clock animations as the reminder instead.

## Known Limitations (v1)

- **Single reminder only:** Only one rule configured. Plan for multi-reminder in future update.
- **No quiet mode:** Reminder fires even during night/sleep hours inside your window (tighten the start/end window, or use the separate night-brightness schedule as a workaround).
- **Day filter needs NTP:** The day-of-week comes from the NTP-synced clock. If the clock has never synced (offline boot, time set by hand), the day filter is skipped and the reminder fires on any selected-hours day.
- **No snooze:** Once fired, interval resets. No way to delay the next fire.
- **Escalation is gentle and new (v2.31.0):** From the second unacknowledged nudge on, the same swell plays a second time about 6 seconds after the first. It asks twice; it never gets brighter. Press either clock button during a nudge, or within about 15 seconds after, to acknowledge: escalation clears and the interval restarts. That press does not adjust the time; the next one does, as usual. Before v2.31.0 every nudge was identical and played once. Still an ask, not an alarm.
- **Brief visual takeover:** While a reminder plays (~2-4.4s) the animation owns the display, but it's non-blocking, so Wi-Fi, the web UI, and time-keeping keep running throughout.

## Troubleshooting

### Animation doesn't fire at expected time
- **Check 1:** Is it enabled? (Motion & nudges card, "Enable focus reminders" checkbox)
- **Check 2:** Is the clock's current time within the start/end window? (the time readout at the top of the page)
- **Check 3:** Is today a selected day? (verify days-of-week checkboxes)
- **Check 4:** Has a full interval passed since the last fire or acknowledgment? (The first nudge after enabling fires as soon as the window matches.)
- **Check 5:** Open Serial monitor (115200 baud), watch for `[FocusReminder] Fired at...` log

### Settings not saving
- Refresh WebUI (Ctrl+F5)
- Check browser console for errors (F12)
- Verify the clock is connected to WiFi (the status line under the live clock preview reads "Wi-Fi on")
- Try **Save brightness** first (quick controls at the top) to verify saves work at all

### Clock time is wrong
- Sync via NTP: **Time & light** card, "Sync to internet" button
- Or set manually: **Time & light** card, enter the time, "Set time" button
- Reminders only fire when time is correct

## Advanced: Debug via Serial

Connect USB to ESP32-C3, open serial monitor (115200 baud):
```
[FocusReminder] Fired at 14:30 (interval=60 min)
```

Decode: Fired at 2:30 PM on a 60-minute interval. Use to verify timing.

## Future Enhancements (Roadmap)

- [ ] Multiple reminder rules (3-5 simultaneous)
- [ ] Quiet/sleep mode exemption
- [ ] Custom labels ("Lunch break", "Leave house", etc.)
- [x] Test-now button (the preview arrow next to the animation dropdown fires the reminder on the device)
- [x] Gentle escalation + button acknowledgment (v2.31.0)
- [ ] Soft audio alert (buzzer) option
- [ ] Snooze/delay next fire
- [ ] Integration with Home Assistant automations

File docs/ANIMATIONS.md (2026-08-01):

# Animation Catalog

> **Current animation set -- verified against source at v2.27.3 (2026-07-17).**
> v2.4.0 replaced the original 29-mode catalog with 16 palette-aware animations.
> The per-mode descriptions below now document that live set (they were legacy /
> historical through v2.9.x and were rewritten to match source in v2.10.2).
> v2.9.7 made the bloom-family animations theme-faithful (each ring blooms in its
> own clock color). v2.27.0 collapsed the 10 flower palettes and the 4 separate
> reminder palettes into ONE shared 5-option list (Clock colors + 4 moods) used
> by both chimes and nudges; the removed flower palettes are archived in
> `docs/archive/flower_palettes_2026-07-14.md`. v2.27.2 added the Firefly nudge
> (mode 11). All reflected below.
> The live set (`AnimPhase` enum + Web UI labels):
>
> | Slot | Modes | Web UI labels |
> |---|---|---|
> | Quarter (:15/:45) | 1-3 | Slow comet, Dual orbit, Bloom ripple |
> | Half-hour (:30) | 1-3 | Unfurl, Three comets, Breathe |
> | Top of hour (:00) | 1-5 | Ceremony, Galaxy spin, Supernova, Comet relay, Deep breath |
> | Reminder | 6-10 (0-5 delegate to the slots above) | Gentle pulse, Orbiting orb, Ripple in, Heartbeat, Slow bloom |
>
> Since v2.5.0, firmware bounds (`sanitize()`, POST clamps, `/previewAnimation`)
> match this set exactly. The Animation Style system (palette/speed/brightness/
> trail) still applies as described in its section below.

## v2.8.0 Feel Pass (2026-07-03)

No modes were added, removed, or renumbered -- this pass reworked the following in
place, purely for visual feel. Full detail in `docs/CHANGELOG.md` [2.8.0]; summary:

- **Reminder nudges (modes 6/8/9/10 -- Gentle Pulse, Ripple In, Heartbeat, Slow Bloom)**:
  every reminder's peak brightness is now capped by a shared `NUDGE_CEIL` (205/255,
  ~80%) so a nudge never blasts full intensity. Gentle Pulse and Ripple In got longer,
  softer envelopes with a subtle warm hue drift. Heartbeat was rebuilt from a hard
  140ms/80ms strobe into two eased 350ms/550ms swells -- same two-thump cadence, now a
  breath instead of a warning flash. Slow Bloom now unfurls its inner-12 stamen ring
  (previously skipped).
- **Galaxy Spin (hour mode 2)**: `spinWave()` replaced by two-arm `galaxyWave()` with a
  true-black floor, applied to every palette (gradient palettes used to render flat
  with no dark lanes). Added slow hue drift, twinkling "star" pixels in the dark lanes,
  and a twinkling core.
- **Comet Relay (hour mode 4)**: each comet head now sweeps the palette as it travels,
  with the trail lagging a few hue-steps behind -- reads as a rainbow spiral instead of
  a flat-colored comet.
- **Bloom Ripple (quarter mode 3) / Unfurl (half-hour mode 1)**: explicit flower-part
  coloring from the center out -- warm gold stamen (center + inner-12, palette-independent)
  -> stigma (middle-24, palette) -> petals (outer-60, palette), via new `stamenColor()`.
  **Superseded:** v2.9.7 made both animations theme-faithful, so the center is now
  `bloomColor(3, 0)` -- its own configured/palette color -- not the palette-independent warm
  gold described above (verified `animQ3` main.cpp:2170, `animH1` main.cpp:2195).
  `stamenColor()` still exists but no longer drives these two.
- **Demo Mode**: hour showcase (step 4) now plays Ceremony -> Galaxy Spin -> Supernova ->
  Comet Relay (was 3, now 4); reminder step (step 5) plays Gentle Pulse -> Ripple In ->
  Heartbeat -> Slow Bloom once each (was Gentle Pulse x2 + Heartbeat x2) to demonstrate
  the full gentled-nudge range. Total demo runtime ~110s (was ~99s). The step table
  lives in `DemoMode::steps[]` in `src/main.cpp`.

## Animation Design Principles

### Core Philosophy
Animations exist to **acknowledge the passage of time** and **provide visual feedback**, not to obscure the clock display. All animations are time-bound and return to normal clock display.

### Rules
1. **Hands always win** -- After animation ends, clock display must be accurate
2. **Escalating intensity** -- More frequent events = shorter/subtler animations
3. **Configurable** -- User can disable or select specific animations
4. **Time-bound** -- All animations have fixed maximum duration
5. **Brightness-aware** -- Respect user's brightness settings (day/night/auto)

---

## Animation Triggers

### Time-Interval Animations

**Quarter-Hour** (:15, :30, :45) -- **Subtle acknowledgment** (2-3 sec)
- Frequency: 4x per hour
- Intensity: Low
- Purpose: Mark 15-minute intervals without disruption

**Half-Hour** (:00, :30) -- **Medium celebration** (4-6 sec)
- Frequency: 2x per hour
- Intensity: Medium
- Purpose: Significant time marker, brief visual interest

**Top of Hour** (:00 only) -- **Full spectacle** (8-12 sec)
- Frequency: 1x per hour
- Intensity: High
- Purpose: Hourly celebration, showcase LED capabilities

### Status Animations

**Wi-Fi Connecting** (up to 20 sec)
- Blue spinning dot on inner ring
- Shown during boot WiFi connection attempt
- Transitions to success/fail animation

**Wi-Fi Success** (1.5 sec)
- Green spinning dot on inner ring
- Confirms successful connection

**Wi-Fi Failure** (2 sec)
- Red spinning dot on inner ring
- Indicates connection timeout

**Button Press** (0.7 sec)
- Orange spinning dot on inner ring
- Immediate visual feedback for manual time adjustment

**Time Sync** (1.2-1.5 sec)
- Cyan spinning dot on inner ring
- Shown after NTP sync or browser sync

**Settings Saved** (1.3 sec)
- Purple spinning dot on inner ring
- Confirms EEPROM write success

**OTA Update In Progress** (variable duration)
- Blue spinning dot on inner ring (brighter: 0x0000FF)
- Shown during over-the-air firmware upload
- Duration: until upload completes or fails (typically 5-30 sec)
- No user action needed during update

**OTA Update Success** (2 sec)
- Green spinning dot on inner ring (bright: 0x00FF00)
- Confirms firmware written and verified successfully
- Device reboots automatically after animation

**OTA Update Failed** (2+ sec)
- Red spinning dot on inner ring (bright: 0xFF0000)
- Indicates upload error (connection lost, verification failed, etc.)
- Portal may reappear on next boot

**Center Idle** (continuous)
- Slow breathing pulse on center pixel (1.8 sec period)
- Only active when no other status showing
- Can be disabled via `statusAnimations` setting

---

## Quarter-Hour Animations (modes 1-3, ~2.3-2.8s)

Short, low-intensity acknowledgments fired at :15/:45 (and :30 if no half-hour animation is set).

### 1. Slow Comet
**Mode**: `quarterAnimation = 1` (`animQ1`, ~2.5s)

A single bright pixel travels once clockwise around the outer 60-ring, trailing `trailLength` fading tail LEDs behind it, with an eased brightness attack and release. Color comes from the outer band (`bandColor(0)`): the outer-marker color on **Clock colors**, or that ring's color on a mood palette.

### 2. Dual Orbit
**Mode**: `quarterAnimation = 2` (`animQ2`, ~2.8s)

Two pixels half a ring apart (30 LEDs) orbit the outer 60-ring together, each with its own fading trail. The lead orbiter uses the outer band color and the second uses the center band color, so the two arms read as distinct rather than as a duplicate.

### 3. Bloom Ripple (default)
**Mode**: `quarterAnimation = 3` (`animQ3`, ~2.3s)

A bloom ripples outward from the heart: center, then inner-12, then middle-24, then outer-60 light on staggered onsets and fade back. Since v2.9.7 each ring blooms in its own clock color: center->`centerColor`, inner->`innerHourColor`, middle->`hoursColor`, outer->`outerMarkerColor` via `bloomColor()`. On a mood palette each ring uses that palette's color for the ring instead. The default quarter animation and the signature ChronoBloom effect.

---

## Half-Hour Animations (modes 1-3, ~5s)

Medium-intensity markers fired at :30.

### 1. Unfurl (default)
**Mode**: `halfHourAnimation = 1` (`animH1`, ~5s)

Petals unfurl from the heart outward. The center stamen lights first, then the inner-12, middle-24 and outer-60 rings each fill in progressively, LED by LED, on staggered onsets -- a flower opening. Ring colors via `bloomColor()`.

### 2. Three Comets
**Mode**: `halfHourAnimation = 2` (`animH2`, ~5s)

One comet per ring (outer, middle, inner), all travelling the same direction, each with a fading trail in its ring's band color -- a coordinated three-ring relay rather than three unrelated chasers.

### 3. Breathe
**Mode**: `halfHourAnimation = 3` (`animH3`, ~5s)

All three rings breathe together on phase-offset sine waves (inner leads, outer lags), gamma-weighted so the troughs settle gently into dark instead of stepping through the low PWM levels. Ring colors via `bandColor()`.

---

## Top-of-Hour Animations (modes 1-5, ~8-9s)

The full hourly spectacle, fired at :00.

### 1. Ceremony (default)
**Mode**: `hourAnimation = 1` (`animHr1`, ~9s)

A stately full-clock reveal: the outer-60 fills clockwise, then the middle-24 fills counter-clockwise, then the inner-12 fills, and finally the center stamen eases in and gently pulses. The grandest of the hour animations. Ring colors via `bloomColor()`.

### 2. Galaxy Spin
**Mode**: `hourAnimation = 2` (`animHr2`, ~9-10s)

Two bright spiral arms rotate against dark "space" lanes (`galaxyWave()` with a true-black floor), the hue drifting slowly across the run, with occasional white "star" pixels twinkling in the dark lanes and a twinkling galactic core. Reworked in v2.8.0 to carve dark lanes on every palette.

### 3. Supernova
**Mode**: `hourAnimation = 3` (`animHr3`, ~8s)

A bright core ignites, then expanding shells detonate outward (inner->middle->outer), each easing in, before a global fade over the final second. Ring colors via `bloomColor()`; since v2.9.7 the outer shell lights on every palette (it used to go dark on some).

### 4. Comet Relay
**Mode**: `hourAnimation = 4` (`animHr4`, ~8s)

A relay of comets hands off outer->middle->inner. Each comet's head sweeps the palette as it travels, with its trail lagging a few hue-steps behind, so it reads as a rainbow spiral rather than a flat comet. A warm stamen dot lights at the finish.

### 5. Deep Breath
**Mode**: `hourAnimation = 5` (`animHr5`, ~9s)

The whole flower swells and settles on one long gamma-weighted breath -- every ring and the center rise and fall together. Ring colors via `bandColor()`.

---

## Reminder Animations (modes 6-11, ~2-4.4s)

Triggered by the Focus Reminder scheduler (not by clock time) when `focusReminder_animation` is 6-11. All use the **reminder palette** (`reminderPalette`), selected independently of the chime palette so a nudge can read differently from an interval chime. Since v2.10.3 the reminder palette applies to **every** reminder-triggered animation: nudge modes 0-2, which delegate to the quarter/half-hour/hour chime animations, also render in the reminder palette instead of the chime's animation palette. Every reminder's peak brightness is capped by a shared `NUDGE_CEIL` (205/255, ~80%) so it reads as a swell, never an alert flash (v2.8.0 feel pass).

### ANIM_REM1 -- Gentle Pulse
**Mode**: `focusReminder_animation = 6` (`animRem1`, ~3.6s)

A slow ~1.2s rise / brief crest / ~1.9s fall across all rings -- a breath, not a blink -- with a subtle warm hue drift over the swell.

### ANIM_REM2 -- Orbiting Orb
**Mode**: `focusReminder_animation = 7` (`animRem2`, ~3s)

The outer ring holds a dim wash while a single orb orbits the inner-12 with a short trail. The quietest, most localized nudge.

### ANIM_REM3 -- Ripple In
**Mode**: `focusReminder_animation = 8` (`animRem3`, ~2.8s)

Rings swell inward in sequence -- outer, middle, inner, center -- each with a soft ~600ms rise / ~1.1s fall.

### ANIM_REM4 -- Heartbeat
**Mode**: `focusReminder_animation = 9` (`animRem4`, ~2.1s)

Two eased swells in a two-thump cadence (350ms rise / 550ms fall), the second beat quieter -- a heartbeat that breathes rather than strobes (rebuilt from a hard strobe in v2.8.0).

### ANIM_REM5 -- Slow Bloom
**Mode**: `focusReminder_animation = 10` (`animRem5`, ~4s)

A slow bloom opens outer->middle->inner->center over ~4s, completing petals-inward to the stamen.

### ANIM_REM6 -- Firefly
**Mode**: `focusReminder_animation = 11` (`animRem6`, ~4s)

Fourteen fixed points scattered across the three rings breathe on their own staggered cycles (~1.4s period, roughly 55% of cycles hosting a light), so the swarm drifts rather than pulses in unison. The whole nudge fades in over ~0.7s and out over ~0.9s.

Unlike every other nudge, Firefly repaints the idle face first and drifts the swarm across it, rather than painting onto the cleared buffer `renderAnimFrame()` hands it. Lighting only a handful of pixels on a cleared strip would blank the clock for four seconds, which reads as the display switching off. The face keeps its own `effectiveBrightness` and the swarm is the overlay.

---

## Animation Style System

All palette-aware animations use these shared controls:

| Setting | Field | Range | Effect |
|---|---|---|---|
| Color palette (chimes) | `animationPalette` | 0-3, 7 | One shared 5-option list since v2.27.0: 7 = Clock colors (default, ring-mapped face colors), 0 = Golden hour (warm), 1 = Moonlight (cool), 2 = Dawn (soft-warm), 3 = Twilight (muted-cool). Each mood is four explicit per-ring colors (outer/middle/inner/center) rendered solid per ring. Any other value sanitizes to 7 (`sanitizePaletteValue`) |
| Reminder palette (nudges) | `reminderPalette` | 0-3, 7 | The same 5-option list as `animationPalette`, selected independently so a nudge can read differently from a chime. Applies to every reminder-triggered animation, including delegated nudge modes 0-2 |
| Speed | `animationSpeed` | 1-5 | 0.5x / 0.75x / 1x / 1.5x / 2x time multiplier |
| Peak brightness | `animationBrightness` | 50-255 | Max LED brightness during animation |
| Trail length | `trailLength` | 2-12 | LEDs in chase/sweep trail |

The `paletteColor(position, useReminderPalette)` helper maps 0-255 -> palette color at `animationBrightness`. The `scaledElapsed(elapsed)` helper applies speed scaling to timing.

### Palette 7 renders the face, including its sameness (know this before filming)

`Clock colors` (7) is the default and faithfully reproduces the configured face -- the rings
fusing into one flower is its documented intent (`bloomColor()`, main.cpp:1845-1847). The
consequence: **if the face theme is a tight color family, every bloom animation reads as one
hue.** Checked against both live units 2026-07-28 -- the 15" has `hoursColor #B30000` and
`innerHourColor #B40404` (the same red to the eye), and the 8" has outer/middle/center all one
orange. Bloom Ripple on palette 7 therefore looks monochrome on both, which is correct behavior,
not a bug.

For a camera, select a **mood palette (0-3)** instead. Since v2.31.1 the moods travel hue from
ring to ring (rim to core) while brightening inward, which is what makes a bloom read as radial
on video. Try any candidate ramp on a live clock without flashing:
`python scripts/tune_palette.py --mood 0 --anim quarter:3`.

---

## Implementation Reference

### Trigger Logic (loop)
```cpp
const ClockTime time = timeModel.get();
static uint8_t lastMinute = 255;

if (settingsStore.get().intervalAnimationsEnabled && time.minute != lastMinute && time.second == 0) {
  lastMinute = time.minute;
  
  if (time.minute == 0) {
    // Top of hour
    renderer.triggerHourAnimation(millis());
  } else if (time.minute == 30) {
    // Half-hour
    renderer.triggerHalfHourAnimation(millis());
  } else if (time.minute % 15 == 0) {
    // Quarter-hour
    renderer.triggerQuarterAnimation(millis());
  }
}
```

### Animation Method Signature
```cpp
void renderAnimationName(uint32_t now) {
  // Animation code here
  // Must restore clock display at end
}
```

### Key Helper Functions
```cpp
uint32_t scale(uint32_t color, uint8_t amount);        // Scale RGB by 0-255
uint32_t pulse(uint32_t color, uint32_t now, ...);     // Breathing effect
void setRingPixel(const RingConfig &ring, uint8_t idx, uint32_t color);
void setCenterPixel(uint32_t color);
```

---

## Adding New Animations

### Process
1. **Design** -- Sketch timing and visual effect on paper
2. **Implement** -- Add `renderMyAnimation(uint32_t now)` method to `ClockRenderer` class
3. **Integrate** -- Add enum value to appropriate trigger (quarter/half/hour)
4. **Web UI** -- Add option to dropdown selector
5. **Test** -- Verify animation duration, clean return to clock display

### Guidelines
- **Respect brightness** -- Use `settings_.get().dayBrightness` as reference
- **Time limit** -- Quarter=3s, Half=6s, Hour=12s maximum
- **Clean exit** -- Always return to accurate clock display
- **No blocking delays >50ms** -- Use state machine for longer animations
- **Test at extremes** -- Full brightness and minimum brightness
- **Test all variants** -- 8" and 15" clocks may look different

### Example Template
```cpp
void renderMyAnimation(uint32_t now) {
  const ClockSettings &settings = settings_.get();
  strip_.clear();
  
  // Animation sequence here
  // Use strip_.show() to update display
  // Use delay() sparingly (non-blocking preferred)
  
  // Restore normal display at end
  timeModel.markDirty();  // Force full redraw
}
```

---

## Animation Timing Chart

| Trigger | Frequency | Duration | Intensity | User Configurable |
|---|---|---|---|---|
| Quarter-hour | 4x/hour | 2-3 sec  | Low | ✅ 3 variants + off |
| Half-hour | 2x/hour | 4-6 sec  | Medium | ✅ 3 variants + off |
| Top of hour | 1x/hour | 8-12 sec | High | ✅ 5 variants + off |
| Wi-Fi connecting | Boot only | <20 sec  | Low | ❌ Always on |
| Wi-Fi success | Boot only | 1.5 sec  | Low | ✅ statusAnimations|
| Wi-Fi failure | Boot only | 2 sec | Low | ✅ statusAnimations|
| Button press | User | 0.7 sec  | Low | ✅ statusAnimations|
| Time sync | Variable  | 1.2 sec  | Low | ✅ statusAnimations|
| Settings saved | User | 1.3 sec  | Low | ✅ statusAnimations|
| Center idle | Continuous| N/A | Minimal | ✅ statusAnimations|

---

## Future Animation Ideas

### Sensor-Triggered
- **Sunrise detected** (VEML7700): 5-minute warm color fade (dark blue -> orange -> yellow)
- **Sunset detected** (VEML7700): 5-minute cool color fade (yellow -> orange -> deep purple)
- **Storm darkness** (sudden lux drop): Lightning flash effect (random white strobes)
- **Motion detected** (lux spike): Welcome rainbow chase
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

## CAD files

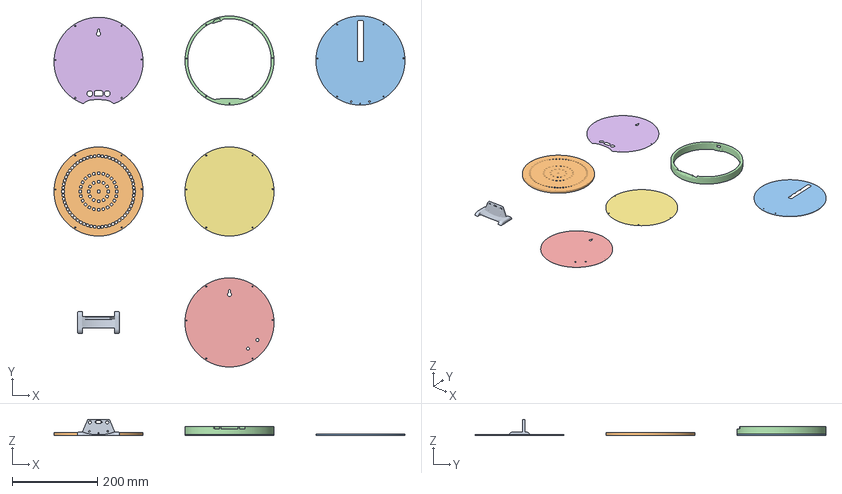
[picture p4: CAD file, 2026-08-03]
docs/publish/ChronoBloom_3D_Files/ChronoBloom_8inch/V13/Chronobloom-8inch-v13-All-AssemblyView.3mf
823.4 x 823.4 x 37.9 mm
Chronobloom-8inch-v11- (10).stl
Chronobloom-8inch-v13- (19).stl
Chronobloom-8inch-v13- (18).stl
Chronobloom-8inch-v13- (17).stl
Chronobloom-8inch-v13- (13).stl
Chronobloom-8inch-v13- (12).stl
Chronobloom-8inch-v13- (20).stl

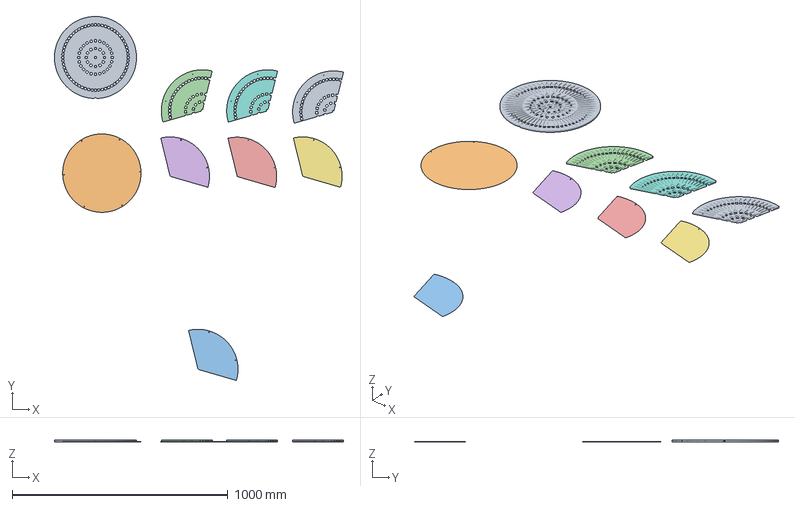
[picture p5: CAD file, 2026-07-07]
docs/publish/ChronoBloom_3D_Files/ChronoBloom_15inch/ChronoBloom-15inch-3-ring-clock(all).3mf
1339.2 x 1686.3 x 7.00 mm
Steve Manley - LED Clock Face Plate V2.1 for Neo Maximus - V1.0 - 6th May 2019.stl
led ring clock 200scale (2).stl
led ring clock 200scale (3).stl
led ring clock 200scale (8).stl x 3
led clock 185pc-diffuser.stl x 3

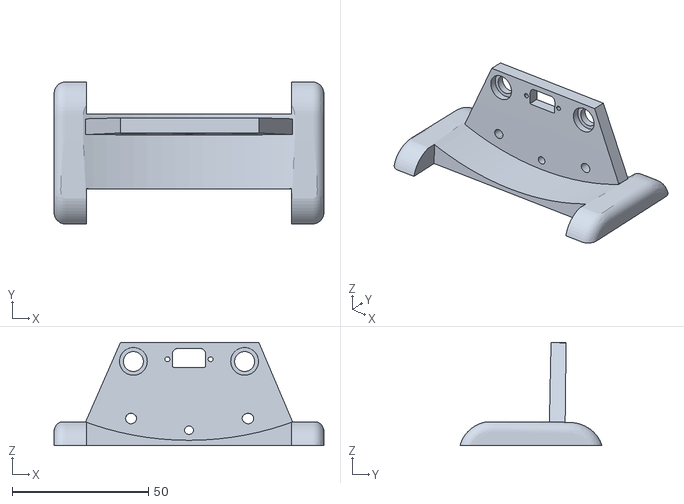
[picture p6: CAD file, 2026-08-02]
docs/publish/ChronoBloom_3D_Files/ChronoBloom_8inch/V13/Chronobloom-8inch-v13-stand.stl
99.2 x 52.1 x 37.9

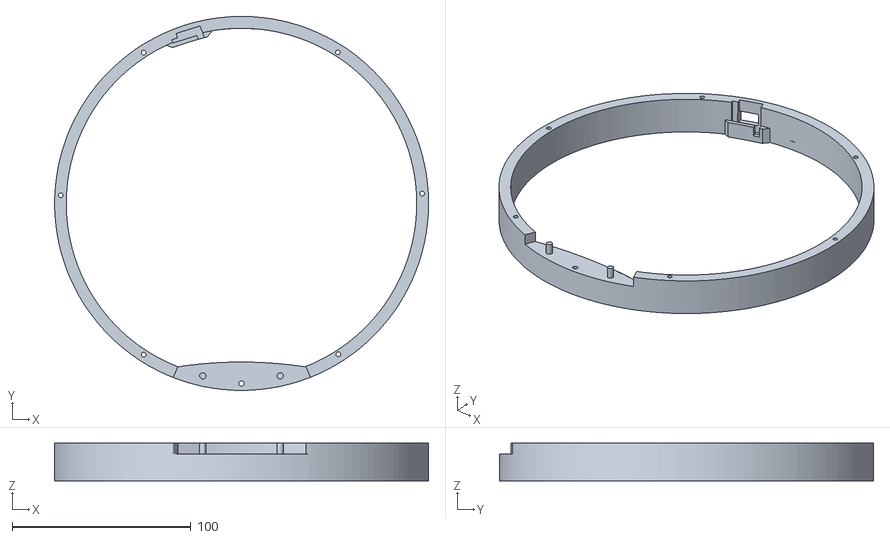
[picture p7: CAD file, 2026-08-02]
docs/publish/ChronoBloom_3D_Files/ChronoBloom_8inch/V13/Chronobloom-8inch-v13-Ring.stl
209.0 x 209.0 x 21.0

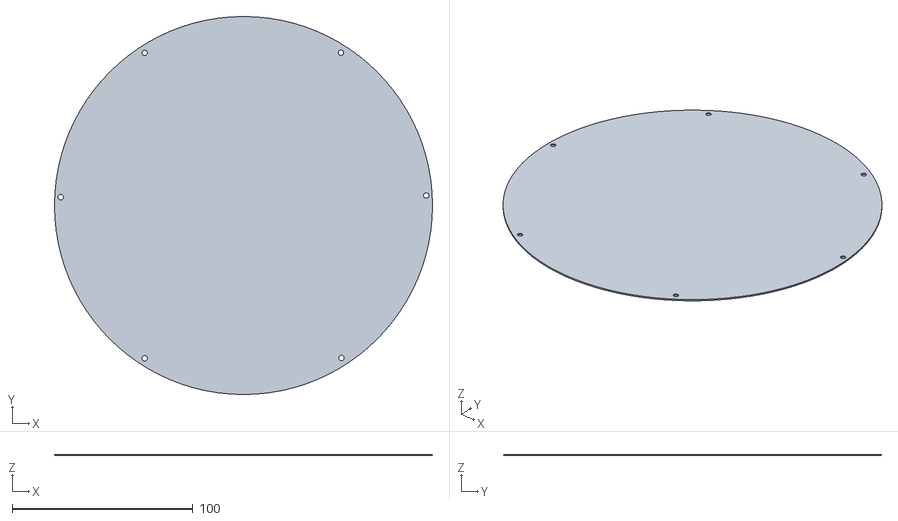
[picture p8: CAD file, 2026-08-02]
docs/publish/ChronoBloom_3D_Files/ChronoBloom_8inch/V13/Chronobloom-8inch-v13-frontDiffuser.stl
209.0 x 209.0 x 0.8

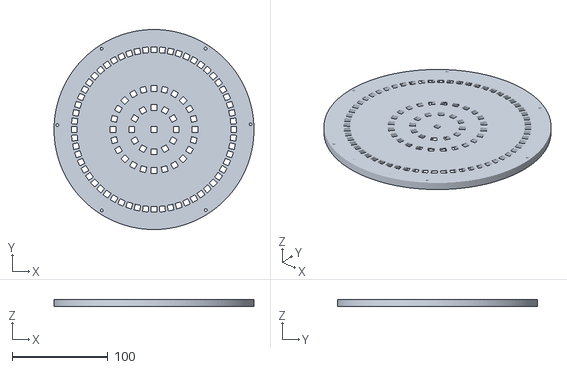
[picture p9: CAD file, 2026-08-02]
docs/publish/ChronoBloom_3D_Files/ChronoBloom_8inch/V13/Chronobloom-8inch-v13-Reflector.stl
209.0 x 209.0 x 7.00

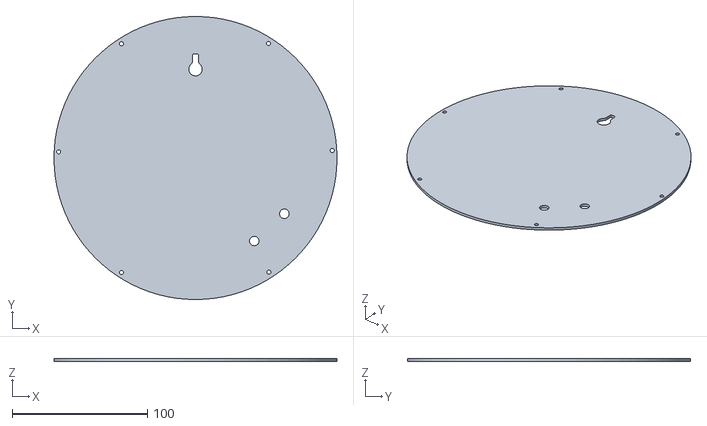
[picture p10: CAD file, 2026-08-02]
docs/publish/ChronoBloom_3D_Files/ChronoBloom_8inch/V13/Chronobloom-8inch-v13-backCover-Buttons.stl
209.0 x 209.0 x 2.00

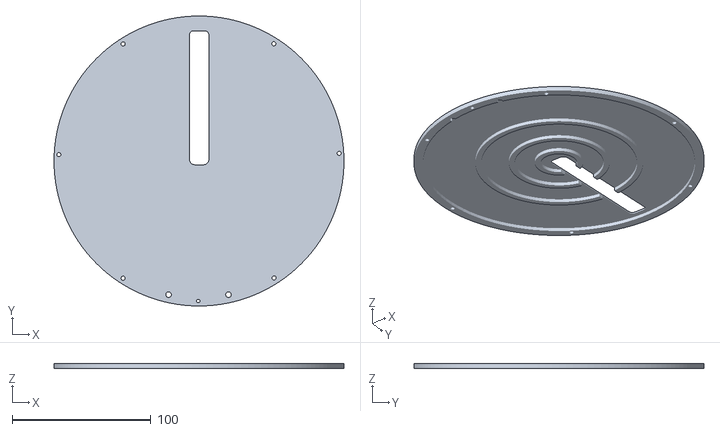
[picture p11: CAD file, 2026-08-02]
docs/publish/ChronoBloom_3D_Files/ChronoBloom_8inch/V13/Chronobloom-8inch-v13-Spacer.stl
209.0 x 209.0 x 3.30

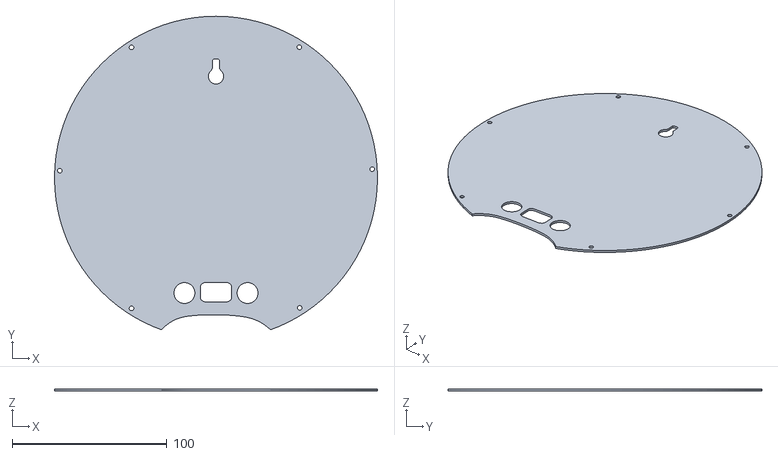
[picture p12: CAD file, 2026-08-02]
docs/publish/ChronoBloom_3D_Files/ChronoBloom_8inch/V13/Chronobloom-8inch-v13-backCover.stl
209.0 x 202.9 x 1.50

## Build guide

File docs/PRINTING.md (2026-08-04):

# Printing ChronoBloom

Covers the 8" build. The 15" files ship for the adventurous, but a guide is not written yet; the 3MF and the LightBurn SVG are the whole story for now.

Files: [docs/publish/ChronoBloom_3D_Files/ChronoBloom_8inch/V13/](publish/ChronoBloom_3D_Files/ChronoBloom_8inch/V13/). The assembly 3MF has every part with print profiles already embedded (Bambu Studio); the individual STLs are there if you want to lay them out yourself.

| Part | Qty | File |
|---|---|---|
| Everything, profiles embedded | -- | `Chronobloom-8inch-v13-All-AssemblyView.3mf` |
| Frame ring | 1 | `Chronobloom-8inch-v13-Ring.stl` |
| Front diffuser | 1 | `Chronobloom-8inch-v13-frontDiffuser.stl` |
| Reflector | 1 | `Chronobloom-8inch-v13-Reflector.stl` |
| Spacer | 1 | `Chronobloom-8inch-v13-Spacer.stl` (print it, it is not optional, see below) |
| Back plate, desk (default) | 1 | `Chronobloom-8inch-v13-backCover.stl` |
| Back plate, wall (alternative) | 1 | `Chronobloom-8inch-v13-backCover-Buttons.stl` |
| Desk stand | 1 | `Chronobloom-8inch-v13-stand.stl` |

The stand is in the assembly 3MF as well, so you get it either way.

There used to be a second project file holding the same parts arranged as a stack to look at.
The two were consolidated in August 2026, so `Chronobloom-8inch-v13-All-AssemblyView.3mf` is now
the only one and it does both jobs: it carries all seven parts with the print profiles already
set, laid out across eight plates, and you can slice it directly.

Three SVGs ship alongside for anyone cutting rather than printing the flat parts:
`ChronoBloom-FrontDiffuser.svg`, `ChronoBloom-backCover.svg` and
`ChronoBloom-backCoverButtons.svg`.

Print one back plate or the other, not both. The choice is desk or wall.

**Desk, and this is the default.** `Chronobloom-8inch-v13-backCover.stl` carries the cutout for
the stand.

**Wall.** `Chronobloom-8inch-v13-backCover-Buttons.stl`, 2 mm, with the openings for the two
momentary buttons. Both back plates are in the all-in-one assembly 3MF, so you do not have to go
looking for either.

One thing to think about before you commit to the wall version: the buttons sit on the back, so
mounted flat they end up tight against the wall and may be awkward to reach. Leave yourself a
little standoff. How much has not been measured, so treat that as a warning rather than a number.

## Two parts, two jobs, and the names matter

The **reflector** sits behind the LEDs and shapes the light into pointed hands. That's the part
descended from Steve Manley's 2015 design, and it's why the clock looks the way it does.

The **front diffuser** is a separate thin sheet over the face that softens the pixels into a
bloom. Different part, different job, and it's the fussy one.

## The frame

- **Material:** basic PLA. That's what I'd print your first one in. Glow-in-the-dark PLA on the frame is a fun thing to try if you happen to have some, since it charges off the LEDs and glows for a while after the display sleeps at night, but it isn't required and it isn't what I'd tell you to buy.
- **Layer height:** 0.2mm is fine for the frame.
- **Bed:** the largest 8" part is 209 mm square (measured from the shipped v11 STLs), so any 220 mm bed will do. A 256 mm bed (Bambu P1S class) has room to spare.
- **Supports and orientation, per part:** the assembly 3MF already carries orientation and settings, so starting from it is the safe path. Slicing the STLs yourself, here is what is known:

| Part | Orientation | Supports | Notes |
|---|---|---|---|
| Frame ring | Flat on the bed | None by design | Ring seats print flat. Unverified -- needs one slice-check |
| Front diffuser | Flat on a smooth plate | None | 0.6mm thick; settings in the diffuser section below |
| Reflector | Flat on the bed | None by design | Unverified -- needs one slice-check |
| Back cover | Flat on the bed | None by design | Unverified -- needs one slice-check |
| Stand | As laid out in the assembly 3MF | Unverified -- needs one slice-check | |

Either way, check the sliced preview before committing a long print.

## The front diffuser (this is the part that makes the bloom)

Print it, don't skip it. A bare ring is just dots; the diffuser is what turns them into soft light.
This one took a lot of failed prints to land on, so here's what's actually fixed and what you should
expect to experiment with.

- **Material:** white PLA. That one is not negotiable. PLA+ is fine.
- **Thickness:** a starting point, not a spec. 0.6mm is what works for me. PLA scatters light differently brand to brand, so expect to print a couple at different thicknesses before you're happy. Print it flat on a smooth plate.
- **Fill pattern:** set the top and bottom surface fill to **Monotonic**, not Concentric. On a thin circular part some slicers quietly fall back to Concentric even when you pick something else, which shows up as swirl artifacts in the light. Check the sliced preview, not just the settings panel, every time. Worth experimenting with as well: this is the other setting that visibly changes the result.
- **Solid all the way through:** set the top and bottom shell layer counts so together they cover the full thickness, with no sparse infill gap in the middle. A gap in a translucent part reads as a bright streak or a refraction mismatch.
- **Speed:** cap it around 100mm/s, first layer near 44mm/s. Slower layers fuse better, which means fewer tiny voids and more even light. Don't rely on the volumetric-speed cap alone at these thin layer heights.

## Ring fit

The three rings drop into printed seats on the core: 60 LEDs outer, 24 middle, 12 inner, plus one loose pixel for the center. The LEDs on each ring seat exactly into the recesses, no forcing. A little cleanup of stringing around the seats is normal.

Measured off the rings themselves with calipers, not copied from the kit listing:

| Ring | LEDs | Outer diameter |
|---|---|---|
| Outer | 60 | **172 mm** |
| Middle | 24 | **92 mm** |
| Inner | 12 | **52 mm** |
| Center | 1 | **6 mm** opening for a single LED |

Any WS2812B rings in 60/24/12 counts at those diameters will fit. The seats were sized to the rings in the WESIRI 241-LED kit from the BOM, so that kit drops straight in.

> Assembly here is words only for now. Photos of a full build are coming, and my guess is
> within a week or so of 2026-07-31. If you are reading this well after that and there are
> still no pictures, chase me. Until then, read the spacer orientation note twice.

## The spacer, and which way round it goes

The spacer is easy to mistake for an optional shim. It is not. It does two jobs.

It sets the depth. The raised rings moulded into it stand exactly as tall as the WS2812B rings
do once they are seated properly in the reflector's LED slots, so the stack closes at the right
height with no guessing and nothing pressing on the LEDs.

It stops light bleeding between rings. Those same raised rings sit between the 60, the 24 and
the 12 and act as walls, so the seconds ring does not wash into the minutes ring behind the
diffuser. Without it the face reads muddier and the hands lose their edge.

**Orientation matters: the flat side faces away from the front of the clock.** The raised rings
point in toward the LEDs. Fit it backwards and you lose both the depth setting and the light
barriers.

## Assembly hardware

**M2.5 fine thread bolts, and nothing else.** No glue, no pins, no heat-set inserts, no
soldering iron for the frame. The v13 parts changed this: earlier versions leaned on filament
offcuts as alignment pins with a drop of superglue, because the old screws could not reach
through the stack. They can now, so that whole workaround is gone. If you have read an older
version of these instructions, ignore it.

The ring is the spine of the build. It is **21 mm thick**, and everything bolts into it:

- **From the front**, one bolt runs through all three front parts, the front diffuser, the
  reflector and the spacer, and threads into the ring.
- **From the back**, the back cover bolts into the same ring.

So the ring takes the thread from both directions and holds the sandwich together on its own.

| Hole | Diameter | Where | Job |
|---|---|---|---|
| Pass-through | **2.9 mm** | front diffuser, reflector, spacer, back cover | Clearance. The bolt slides through without biting |
| Threaded | **2.6 mm** | the ring only | The M2.5 fine thread cuts its own thread here |

The 2.6 mm figure is the modelled hole. Calipered on an actual printed part the crest measures
about **2.35 mm**, which is what gives the fine thread something to bite into. If your printer
runs tight and the bolt will not start, open the ring holes with a 2.6 mm bit rather than
forcing it. Do not drill the 2.9 mm pass-through holes any wider or the bolt heads lose their
seat.

Use fine thread, not coarse. Coarse M2.5 will strip a 2.6 mm printed hole on the first pass.

The electronics are a lighter touch than you might expect too: the rings arrive with 3-wire JST
connectors already on them, so soldering the chain is about a joint that survives years on a
wall, not about making the connection at all. See the wiring section in the README.

## Credit

The frame geometry is a remix of Steve Manley's original NeoPixel Ring Clock design. See [NOTICE](../NOTICE). STL and print files are CC BY 4.0.

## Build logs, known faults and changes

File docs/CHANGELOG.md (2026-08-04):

# ChronoBloom ESP32-C3 — Changelog

> Formerly neopixelClock-esp32c3-v3

## [2.35.0] - 2026-08-04 (Hand-contrast trial: three candidate mechanisms behind a wall switch)

### Added
- **The hand-contrast wall trial** (operator: unified hands sink into same-hue faces —
  chronobloom magenta-on-magenta, Ember Dahlia's minute hand measured at 1.2x the LIFTED
  outer crests). RAM-only bitmask `handTrial=0..7` on the shared settings parser (never
  persisted, reboot clears, `/diag` gains `hand_trial`):
  - bit 1 `lift cap`: `petalPixel()`'s lift stops adding headroom at 128 so faces never
    climb toward the hands' 255 ceiling; a face the user set above 128 stays as set.
  - bit 2 `shadow halo`: the LEDs flanking the minute hand (60-ring) and middle hour hand
    (24-ring) dim to 15% of the face — a dark notch, geometric contrast immune to hue
    overlap and deep dim. Markers eclipse deliberately (the hand wins). Inner 12-ring
    left un-haloed (3 of 12 LEDs is too much throat).
  - bit 4 `whitened hands`: hour/minute colors pulled 55% toward white before gamma
    (the cream-second-hand trick applied to the time hands). Seconds untouched.
- `scripts/hand_trial.py` + `scripts/hand_trial.bat`: walks baseline / cap / cap+halo /
  cap+halo+white at day and night brightness, on the wall theme then on Ember Dahlia
  staged via the auto-reverting preview. About 2 minutes, nothing persists. Run this
  session against the live 15": the guard correctly refused on 2.34.1 and named the
  flash step.
- The full contrast report (mechanisms P1-P5, the measured failures, and the rulings
  queue Q8-Q12) lives in docs/THEME_RULES_DESIGN_2026-08-04.md.

### Files changed
- `src/main.cpp` (`g_handTrialMask`, `petalPixel` lift cap, `haloRingPixel`/`haloAround`,
  `handColor`, settings parser, `/diag`)
- `platformio.ini` (`FIRMWARE_VERSION` 2.34.1 to 2.35.0)
- `scripts/hand_trial.py`, `scripts/hand_trial.bat`
- `docs/CHANGELOG.md`, `docs/symmap.json`, `docs/FUNCTION_INVENTORY.md`

### Not verified
Both envs build clean; NOT flashed. The check: flash 2.35.0, double-click
`scripts\hand_trial.bat`, watch the four looks, reply with the winner.

## [2.34.1] - 2026-08-04 (The last green path: animations dim hue-safely; inner hour hand unified)

### Fixed
- **"Still seeing green in the center" diagnosed against the live clocks and closed.**
  The center pixel itself renders `centerColor` only (`renderCenterIdle`) and both units
  carry red centers -- mathematically incapable of green. The green lives in the BLOOM
  animations: `renderAnimFrame()` was the one dim path the v2.33.1/.2 fixes deliberately
  skipped, still using Adafruit `setBrightness()` per-channel truncation. Every chime and
  nudge bloom at night ran through it, and Golden hour's gold core `#FFD728` is exactly
  the near-tie color the green die tips over. Animations now join the face path: drawn at
  full, dimmed by the same hue-preserving `scaleStripBufferVideo(br)`.
- Deliberate side effect: animQ1/Q2's `setBrightness(animEnv)` fade envelope used to
  REPLACE the global brightness, so night chimes played at full blast. The envelope now
  composes with auto-dim. The envelope's own 300 ms fade edges still truncate; transient,
  accepted, documented at the call site.

### Changed
- **Q6 ruled from the wall** (operator: the 12-ring hour LEDs "do NOT radiate outward
  with the same color/hue on the 24-ring" in chronobloom and birdofparadise): the
  two-tone inner hour hands are gone. All seven themes now carry
  `innerHourColor`/`innerHourLevel` equal to `hoursColor`/`hoursLevel`; the whole hour
  hand radiates one color, center to rim. Ship gate PASS.
- New law amendment recorded (docs/THEME_RULES_DESIGN_2026-08-04.md, R2): every
  time indicator -- hour, minute, AND second -- must hold a scalable brightness factor
  over the face it crosses (proposed: weighted-lumen ratio >= 2:1 at every brightness,
  or a hue separation clause). Enforcement lands with the Q5 gate build; not yet checked
  per theme.

### Files changed
- `tools/themes/themes.json`, `src/web_html.h`, `docs/publish/demo_reel_designer.html`
- `src/main.cpp` (`renderAnimFrame()` only)
- `platformio.ini` (`FIRMWARE_VERSION` 2.34.0 to 2.34.1)
- `docs/CHANGELOG.md`, `docs/symmap.json`, `docs/FUNCTION_INVENTORY.md`

### Not verified
Both envs build clean; NOT flashed. The checks: flash, re-apply the theme, fire a nudge
or chime at night brightness and watch the bloom's core stay gold; confirm the chronobloom
hour hand runs magenta on both inner rings.

## [2.34.0] - 2026-08-04 (Rule 1 lands: one hand color everywhere; plus the Q3 seam-trial switch)

### Changed
- **All seven themes: the minute hand becomes the hour hand's twin** (operator ruling Q1,
  docs/THEME_RULES_DESIGN_2026-08-04.md). `minutesColor`/`minutesLevel` now equal
  `hoursColor`/`hoursLevel` in every theme. Edited in `tools/themes/themes.json`, stamped
  into `src/web_html.h` and the reel designer by `gen_themes.py`, ship gate
  (`theme_emit_check.py`) PASS afterwards. Takes effect on a unit when a theme preset is
  re-applied; saved EEPROM settings are untouched until then.
- Deliberately NOT unified: the three themes whose INNER hour hand is its own color by
  design (chronobloom `#dc00b4` middle vs `#6eb9ff` inner; birdofparadise `#ff7014` vs
  `#fff2dc`; sunflower `#b30000` vs `#b40404`). Erasing a designed two-tone hand is not
  covered by the Q1 ruling; flagged as open question Q6.

### Added
- **RAM-only seam-trial switch for the Q3 ruling** (`g_seamTrialBlack`): `seamTrial=0/1`
  accepted by the shared POST `/settings` + `/settings/preview` parser (never stored;
  EEPROM untouched; reboot resets to 0), reported as `seam_trial` in `/diag`.
  0 = deep-dim seams keep their dominant channel at 1 (pure ember, the v2.33.2 behavior),
  1 = they go black (shadow). The losing behavior and the switch itself get deleted after
  the ruling.
- `scripts/seam_trial.py` + `scripts/seam_trial.bat`: double-click A/B. Stages night
  conditions through `/settings/preview` (auto-reverting), alternates the two looks in
  labeled 12-second holds, reverts, and confirms via `/diag`. Run this session against the
  live 15": the firmware guard correctly reported 2.33.2 has no switch and pointed at the
  flash step.

### Files changed
- `tools/themes/themes.json`, `src/web_html.h`, `docs/publish/demo_reel_designer.html`
- `src/main.cpp` (`g_seamTrialBlack`, scaler keep-lit condition, settings parser, `/diag`)
- `platformio.ini` (`FIRMWARE_VERSION` 2.33.2 to 2.34.0)
- `scripts/seam_trial.py`, `scripts/seam_trial.bat`
- `docs/CHANGELOG.md`, `docs/symmap.json`, `docs/FUNCTION_INVENTORY.md`

### Not verified
Both envs build clean; NOT flashed. The checks: re-apply Ember Dahlia on a flashed unit and
confirm the minute hand renders `#FF1E00` at the hour hand's strength; then run
`scripts/seam_trial.bat` and watch the two seam candidates alternate.

## [2.33.2] - 2026-08-04 (Deep-dim hue fix, round two: petal-depth seams no longer go green)

### Fixed
- **The v2.33.1 fix held except with petal depth active: the operator reported the green
  tinge returning at exactly petalDepth 51 and up.** Diagnosed against the live 15" unit's
  own settings, read over LAN (stock Ember Dahlia, lux-driven brightness 28-79): the gold
  inner-face seam `#FFE25A` still landed on R:G ties like (2,2,0) and (1,1,0) at night
  brightness, because round-to-nearest lets a weak green channel round UP into equality
  with red. The reported 51 threshold is real in the integer math: it is where the seam's
  blue byte dies, turning gold into yellow-green a step before the ties take over.
- `scaleStripBufferVideo()` now rounds only the dominant channel (and channels equal to
  it); strictly smaller channels truncate. Quantization error becomes one-sided: a
  deep-dimmed color can only saturate toward its own dominant hue (gold to ember, violet
  to blue), never walk across hue. Whites keep rounding as a group and stay neutral;
  at high brightness the change is at most 1 code per channel.
- Verified by exact-integer simulation of the full petal pipeline at the live unit's
  values across petalDepth 40-100 and brightness 28-209: every (1,1,0)/(2,2,0) tie
  collapses to its ember dominant; no output anywhere exceeds the color's ideal G:R ratio.

### Known residue, deliberately untouched
- A truly deep seam at output magnitude 1-2 renders as pure dominant (ember) rather than
  gold: at that dimness 8-bit WS2812 output cannot express the ratio at all per frame.
  The industrial fix would be temporal dithering, which needs a continuous high-rate
  refresh this clock's 1 fps idle deliberately avoids.
- `renderAnimFrame()` still dims through Adafruit `setBrightness()` (unchanged from
  v2.33.1's note).

### Files changed
- `src/main.cpp` (`scaleStripBufferVideo()` only)
- `platformio.ini` (`FIRMWARE_VERSION` 2.33.1 to 2.33.2)
- `docs/CHANGELOG.md`, `docs/symmap.json`, `docs/FUNCTION_INVENTORY.md`

### Not verified
Built clean, NOT flashed. The check: on the flashed unit (the 15" at .189 — note the 8"
at .110 still runs 2.32.0), Ember Dahlia, petal depth 51-plus, night brightness: seams
should read deep ember, never green.

## [2.33.1] - 2026-08-03 (Deep-dim hue fix: orange petals no longer turn green at low brightness)

### Fixed
- **Colors walked off-theme at low brightness -- the operator's Ember Dahlia photos showed
  the orange middle face rendering GREEN at brightness 9 while true-to-theme at 209.**
  Root cause, reproduced numerically from the shipped theme bytes: `scaleStripBufferVideo()`
  floored every nonzero channel at 1, so at brightness 9 the middle-face `#ff7000` became
  (2,1,0) at the petal crest and (1,1,0) at the seam -- a green channel that should be 0.07
  of a step pinned at a full step -- and the WS2812B green die's roughly double luminous
  efficacy renders 1:1 R:G as green. Only 9 output levels exist at that dim; which channels
  survive IS the hue.
- `scaleStripBufferVideo()` now rounds each channel to nearest instead of truncating, and a
  lit pixel that would round to black keeps only its dominant channel at 1. Deep-dimmed
  colors now collapse toward their dominant primary (ember stays ember) instead of toward
  the floor-of-ones mud. Same simulation, after: crest (3,0,0), seam (1,0,0).
- The lux auto-brightness path feeds this same scaler, so "hue shifts with the lux sensor"
  is the same defect and gets the same fix.

### Known residue, deliberately untouched
- `renderAnimFrame()` still dims animation frames through Adafruit `setBrightness()`
  (truncating, no floor), and two chime animations drive their envelope through
  `setBrightness()` directly -- animations at deep dim will still hue-collapse toward
  dominant channels. Separate change with its own risks; not smuggled into this fix.
- Equal-RGB whites still read cool/greenish at very low codes: that is die efficacy
  (physics), not scaler math. The former green×0.69 white-balance was removed deliberately
  in the WLED-parity work; not reintroduced here.

### Files changed
- `src/main.cpp` (`scaleStripBufferVideo()` only)
- `platformio.ini` (`FIRMWARE_VERSION` 2.33.0 to 2.33.1)
- `docs/CHANGELOG.md`, `docs/symmap.json`, `docs/FUNCTION_INVENTORY.md`

### Not verified
Built clean, NOT flashed and NOT observed on hardware. The check that would confirm it:
same room, same theme, slider at 9 -- the middle ring should read ember red, not green.

## [2.33.0] - 2026-08-03 (Nudge acknowledgment removed: a nudge is not something you call off)

### Removed
- **Button acknowledgment of focus nudges, and the escalation that depended on it.**
  Operator's ruling: it is a reminder nudge, not an alarm to be called off. The
  acknowledgment is looking up and letting it change what you do next, which happens in
  the room and not on the device.
- `FocusReminderScheduler::acknowledge()` and `ackWindowActive()`, the `ackUntilMs_`,
  `firesSinceAck_` and `repeatPending_` state, and the `ACK_WINDOW_MS` (15 s) and
  `REPEAT_DELAY_MS` (6 s) constants.
- The escalation swell. It only ever meant "you did not acknowledge, so I am asking
  again", so with acknowledgment gone the counter could never reset and every nudge from
  the second onward would have repeated forever. Every nudge is now identical: the tenth
  is the same ask as the first.

### Changed
- The two buttons set the time and nothing else. Previously a press within 15 s of a
  nudge was eaten as an acknowledgment instead of adjusting the clock.
- Disabling reminders now clears only `lastFireMs_`, since the other RAM state is gone.
- Serial line on fire drops the `unacked=` field.

### Why this is written down at length in the source
A future session looking at `FocusReminderScheduler` will see no acknowledgment path and
may read it as an oversight. It is not. The comment block above the `private:` section
records the reasoning so nobody helpfully adds it back.

### Files changed
- `src/main.cpp` (FocusReminderScheduler, and the button handling in the main loop)
- `platformio.ini` (`FIRMWARE_VERSION` 2.32.0 to 2.33.0)
- `docs/CHANGELOG.md`

### Not verified
Built clean, NOT flashed and NOT observed on hardware. The check that would confirm it:
fire a nudge on a real unit, press a button during the swell, and confirm the clock
advances by a minute instead of the nudge being swallowed.

---

## [2.32.0] - 2026-08-01 (Sacrificial-pixel support removed; every build is now the same 97-LED chain)

Both envs build clean (8": RAM 11.3%, Flash 61.8% / 809,508 B. 15": RAM 11.3%, Flash 61.8% /
809,718 B). **Not yet observed on hardware.** The check that would confirm it: flash the 8" and
look at the face — the 12 o'clock marker must sit at physical top and the centre pixel must light.
A one-LED rotation would mean firmware geometry and real wiring disagree.

### Removed
- **The "sacrificial first pixel" build option is gone**, along with every trace of it in firmware:
  the `SACRIFICIAL_PIXEL_ENABLED` / `SACRIFICIAL_PIXEL_INDEX` macros, the three `#error` geometry
  guards that referenced them, `LedRenderer::setSacrificialPixelDark()` and its three call sites in
  the demo-black, animation and face render paths, the `sac=` field in the boot LED summary line,
  and the "Sacrificial pixel: enabled/disabled" boot serial block.

  Context: the maintainer's original 8" prototype had one extra WS2812B spliced in ahead of the
  rings, kept dark, whose only job was to re-drive the board's 3.3 V data signal at a full 5 V for
  the LEDs behind it. It was added while chasing early signal problems, was never actually needed,
  and was **physically removed on 2026-08-01**. The firmware option went with it so that every
  build — the maintainer's included — is the identical 97-LED chain everyone else builds.

- **`sacrificial_enabled` removed from the `GET /diag` response.** It could only ever report
  `false` after this change. `docs/API.md` updated. Nothing in the repo consumed it; verified by
  search before removal.

### Added
- **A plain-English write-up of the level-shifting problem**, in `src/main.cpp` above the LED
  geometry constants. Explains why a 3.3 V board driving 5 V WS2812Bs is marginal by design, how a
  spare first LED works around it, why siting it **at the board beside the 5 V rail** is the whole
  mechanism (it shortens the fragile 3.3 V stretch to almost nothing and hands the long run to the
  rings a clean 5 V signal, so it buys data-line distance as well as reliability), the symptom list
  that points at logic levels rather than a dead LED, and the
  counter-intuitive case where a truer 5 V supply breaks a chain that worked on a sagging one.
  `docs/HARDWARE.md` and `docs/TROUBLESHOOTING.md` carry shorter versions.

### Changed
- `platformio.ini` `[led_chain]` is now just the 8" chain geometry, with the sacrificial pixel as a
  historical note rather than a supported flag. `platformio.local.ini.example`'s override example is
  now a generic "chain with unused LEDs at the front" case.
- Public copy updated where it claimed the firmware still supports the option:
  `docs/publish/HACKADAY.md`, `docs/publish/REDDIT_ESP32.md`, and the matching blocks in
  `docs/publish/launch.json` (`launch_hq.html` regenerated). Corrected a mislabelled fact-sheet row
  that described the **centre status pixel** as "Sacrificial single pixel, troubleshooting-only".

### Files changed
`src/main.cpp`, `platformio.ini`, `platformio.local.ini.example`, `docs/API.md`,
`docs/HARDWARE.md`, `docs/TROUBLESHOOTING.md`, `docs/LAUNCH_GAPS.md`, `docs/publish/HACKADAY.md`,
`docs/publish/REDDIT_ESP32.md`, `docs/publish/PUBLISH.md`, `docs/publish/RELEASE_MANIFEST.md`,
`docs/publish/launch.json`, `docs/publish/launch_hq.html`, `docs/FUNCTION_INVENTORY.md`,
`docs/symmap.json`, `docs/CHANGELOG.md`

## [2.31.5] - 2026-07-31 (No more 10-second pause on every boot of a portal-set-up clock)

Built clean on both envs. **Not yet observed on hardware.** The check that would confirm it: set a
board up through the clock's own setup network, then power it off and on with USB serial open. The
teal ring and the `[Improv] No stored WiFi credentials` line should not appear at all, and the
portal's `*wm:AutoConnect` line should arrive at roughly 0.5 s instead of roughly 9.5 s.

### Fixed
- **A clock set up through its own setup network paused 10 seconds on every power-on.** Before the
  clock does anything else it listens over USB for a browser offering it WiFi, and it skips that
  wait when it already has WiFi. It decided that by looking in one place: the credentials saved by
  the clock's own WiFi page. Credentials entered on the setup network at 192.168.4.1 are not kept
  there - the WiFi chip keeps its own copy - so the clock concluded it had never been set up and
  waited out the full window on every single boot, before it even tried to join the network.

  Since the flasher page recommends the setup network as the reliable route, that was the common
  case for anyone new, and it cost them 10 seconds of dark clock at every power-on.

  The check now asks all three places credentials can live, the same three `setupWiFi()` already
  asks: the WiFi page's own store, the WiFi chip's copy (`WiFiManager::getWiFiIsSaved()`, the same
  call `setupWiFi()` uses, rather than a second hand-written version of it), and any network baked
  in at build time. Anything found means the clock is set up and skips the wait. This can only ever
  make the clock skip the wait more readily, never less, so it cannot lock anyone out of setting up
  a new board; a board holding credentials that no longer work still falls through to the setup
  network, exactly as it does today. Sequencing was checked rather than assumed: the WiFi stack is
  started one line earlier, so it can answer the question by the time it is asked.
  (`src/main.cpp`, `WebUi::begin()`.)

## [2.31.4] - 2026-07-31 (The browser's WiFi box no longer times out mid-typing)

Built clean on both envs and **verified on hardware**, against the published 2.31.3 as a control.
Both binaries were flashed onto a fully erased board over USB and given the same test: answer the
browser handshake, then go completely silent for 35 seconds, the way a person reads the box and
types a password, then send the credentials late.

| | 2.31.3 (published) | 2.31.4 |
|---|---|---|
| Handshake answered | 0.12 s | 0.12 s |
| Setup portal opened | 9.87 s | did not open |
| Credentials sent at | 35.14 s | 35.22 s |
| Device received them | **no, silence** | yes, at 35.33 s |
| Result | timed out, portal fallback needed | provisioned at 37.91 s, connected, mDNS + NTP up |

Confirmed afterwards against the running device: `/diag` reports `firmware_version 2.31.4`.

### Fixed
- **The browser's "Configure WiFi" box timed out on a freshly flashed board.** Reported from the
  first real bare-board flash test (2026-07-30): flashing worked, the box appeared, credentials
  were entered, and it timed out anyway. Fallback to the clock's own setup network worked.

  The clock listened for a browser over USB for a fixed 10 seconds at boot and then stopped, moving
  on to the captive portal - which blocks for its whole lifetime, so the main loop never ran and
  nothing serviced the browser again. Ten seconds is less time than it takes anyone to read the
  box, pick a network and type a password, so the answer arrived at a device that had stopped
  listening. That made it the expected outcome for nearly every user, not bad luck.

  Now the deadline is pushed out as long as a client keeps talking: 10 seconds of silence still
  closes the window, but any complete, checksum-valid Improv frame - including the browser's
  opening handshake, which fires while the user is still reading the dialog - buys another 60
  seconds. A board nobody is talking to behaves exactly as before and opens the portal on the same
  schedule. Only line noise is ignored, since a partial frame never counts as a client.
  (`IMPROV_CLIENT_WINDOW_MS`, `src/main.cpp`.)

### Measured, on the way to that fix
- A client polling twice a second over USB serial gets no reply at all once the clock is connected
  to WiFi, confirming Improv is deliberately deactivated on a running clock and that USB cannot
  silently reconfigure one. Read off a live board on COM12.

## [2.31.3] - 2026-07-29 (Mood palettes, second pass: saturation held)

Data-only, no firmware logic touched. Build-verified on the 8"; **not yet observed on hardware** -
both clocks run 2.31.1.

### Fixed
- **The v2.31.1 mood palettes still read monochrome on the strip, and the cause was saturation,
  not hue.** v2.31.1 gave every mood real hue travel measured in HSL degrees, but produced its
  "brightens toward the core" by *desaturating* each ring inward. WS2812s render low saturation as
  white, so Moonlight ran 65% -> 46% -> 32% -> 8% HSV saturation: violet at the rim, then white,
  white, white. The hue travel was real in the arithmetic and invisible in the room.
  `tools/palettes/palettes.json` had warned about exactly this in its own header ("WS2812 washes
  pastels to white; keep saturation up") and the first pass ignored it.

  All four moods re-authored to hold saturation high on every ring and take the brightening from
  value instead. The core still reads as the brightest thing on the face because it is one LED
  against sixty; a point light needs no help.

  | Mood | Hue travel | Saturation range | Reads as |
  |---|---|---|---|
  | Golden hour | 38 deg | 84-95% | red-orange rim to saturated gold core |
  | Moonlight | 81 deg | 66-85% | violet rim through blue to cyan core |
  | Dawn | 63 deg | 73-85% | rose rim through coral to amber core |
  | Twilight | 80 deg | 67-81% | indigo rim through blue to teal core |

  The re-authoring pass now **gates** on saturation >= 58%, hue travel >= 35 deg, monotonic hue
  outward-to-inward, and a core brighter than the rim, refusing to write if any gate fails, so this
  class of mistake cannot land silently again.

### Note
- `src/anim_palettes.h` and `tools/gen_palettes.py` here also carry a concurrent session's
  comment-only em-dash cleanup. Those two plus `palettes.json` are one generated set; splitting
  them would leave the header disagreeing with its own source.

## [2.31.2] - 2026-07-29 (The public repo compiles again, and now it cannot stop compiling)

Two halves. First, the publish pipeline was broken and the public repo had been un-buildable since
the v2.29.0 push on 2026-07-18. Second, and the reason this is worth a version: the checks that
would have caught it are now code that runs, not prose in a document nobody executes.

### Fixed (firmware, user-visible)
- **Four em dashes removed from the web UI**, in the footer credit and the two auto-brightness
  labels (`src/web_html.h:59,74,75,77`), plus two in JS comments. `CLAUDE.md` bans em dashes in
  human-facing prose and every shipped `.md` was already clean, but nobody had ever proofread the
  UI strings, so they had been on screen since v2.30.0. This is the only reason `FIRMWARE_VERSION`
  moves: `src/web_html.h` changed.
- **The palette generator was reintroducing them.** `src/anim_palettes.h` carried seven em dashes,
  and since it is generated and headed "DO NOT EDIT", fixing the file would have been undone by the
  next run. Fixed the emitted template in `tools/gen_palettes.py` instead and regenerated. Verified
  the palette data is byte-identical: the diff is 7 comment lines and zero color values.

### Fixed
- **The published repo could not compile.** `src/main.cpp:20` includes `anim_palettes.h`, but that
  header was never added to the export manifest, so `github.com/Maestro8484/ChronoBloom` shipped a
  source file with a missing dependency. Proven by cloning the public repo and building it:
  `fatal error: anim_palettes.h: No such file or directory`. Added `src/anim_palettes.h` to the
  manifest. Both variants now build from the exact published file set (8" 809,530 B, 15" 809,750 B,
  61.8% flash, 0 warnings).
- **A bare `pio run` built the wrong variant.** `default_envs` was `esp32c3_v3_15inch`, the
  experimental 15" build, while every README command passes `-e esp32c3_v3_8inch` explicitly. Anyone
  typing plain `pio run` got 96-pixel firmware with a separate center strip on GPIO20, which on an
  8" build is a scrambled face and no error message. Now defaults to the 8".
- **One uncommitted file could jam the whole export.** The manifest globbed
  `ChronoBloom_8inch/v11/**` from the filesystem, not from git, so an untracked work-in-progress
  `.3mf` sitting in that folder failed the export gate and blocked every publish. Replaced the glob
  with the six explicit tracked filenames, which removes the failure mode by construction rather
  than by remembering to tidy up.

### Removed from the public export
Excluded, not deleted. Every file still exists in the private repo and still works; they just stop
shipping. All are recorded in the manifest's `exclude_assert` list so they cannot drift back in.
- **The demo-reel production rig**, which is maintainer tooling with no value to a builder:
  `demo_reel_designer.html`, `scripts/demo_reel_designer.bat`, `scripts/reel_server.py`, both
  `DEMO_CAPTIONS` tracks, `DEMO_MODE.md`, and all three `tools/video/*.ps1` cutting scripts.
  On-device **Demo Mode stays** — it is a button in the web UI that every user gets, so
  `docs/FEATURES.md` now describes it in user terms instead of as a video-recording state machine.
- **`ChronoBloom_QuickRef.docx`** — opened with "Built from scratch. Coded alone.", which
  contradicts the NOTICE crediting Steve Manley's original and the README's own voice.
- **`ChronoBloom_Compact_Function_Inventory.md` / `.docx`** — stated "v2.2.0, 139 functions" against
  a current 2.31.1 with 233. No generator exists for it, so it is hand-maintained and 29 versions
  stale. `docs/API.md` and `docs/ARCHITECTURE.md` cover the same ground.

### Added
- The annotated web UI screenshot is now actually used. It had been shipping into `docs/images/` at
  727 KB while no document referenced it. New "The web UI" section in `README.md` embeds it.

### Added: three new export gates, because the old failure was a doc, not a bug
The 2026-07-12 audit recommended, verbatim, "clean-clone build passes BOTH variants" as a hard
pre-publish gate. It was written into `docs/publish/qa-deep-2026-07-12-PUBLISH-PATCH.md` marked
"owner applies manually", and never performed. Eleven days of a broken public repo followed. Prose
does not run. `tools/publish/export_public.py` had five gates, all in code, all fail-closed, and all
five did their job. The missing ones are now the sixth, seventh and eighth.

- **Gate 6, em dashes in shipped prose.** Scans everything that ships, source files included,
  because `web_html.h` is UI copy and docs get proofread while UI strings do not. Two files are
  exempt through a new `em_dash_exempt` manifest key with the reasoning recorded next to it: the
  historical changelog (rewriting shipped history to satisfy a later style rule would misrepresent
  what those entries said) and `main.cpp` (about 170, all code comments, none user-visible). The
  suffix list stays broad so a new file is scanned by default; exemption is an explicit entry, never
  a silent default.
- **Gate 7, flasher version match.** The flasher manifest's version must equal `FIRMWARE_VERSION`,
  every binary it references must be in the export set, and no stale binary of another version may
  ride along. This is the gate for the drift that had Pages serving 2.29.0 against a 2.31.1 source
  tree with nothing tying the two numbers together.
- **Gate 8, the export set must compile.** Materializes the export into a throwaway directory and
  builds every `[env:...]` in the shipped `platformio.ini`, the way a stranger's clone would. Env
  list is derived, not hardcoded, so a new variant is covered with no change here. Runs last because
  it is the slow one, and skips if a cheaper gate already failed. `--no-build-check` exists and says
  what skipping it cost last time.
- **Verified by deliberately breaking it:** removing `src/anim_palettes.h` from the manifest and
  re-running produced `EXPORT SET DOES NOT COMPILE` for both variants, exit 1, nothing staged. A
  gate nobody has watched fail is a gate nobody should trust.

### Fixed (tooling, found by testing the new gates)
- **A gate failure could exit looking like success.** Gate messages quote file content, and printing
  an arrow character out of `docs/CHANGELOG.md` raised `UnicodeEncodeError` on the default Windows
  console codepage. That killed the process before `sys.exit(1)` ran, so a real failure surfaced as
  a traceback with a misleading exit code. `stdout`/`stderr` are now reconfigured to UTF-8 with
  replacement. Pre-existing; only surfaced because the new gate generated enough output to hit it.

### Files changed
`src/web_html.h`, `src/anim_palettes.h` (regenerated), `tools/gen_palettes.py`,
`platformio.ini` (`FIRMWARE_VERSION` 2.31.1 -> 2.31.2, `default_envs` 15inch -> 8inch),
`tools/publish/export_public.py`, `tools/publish/export_manifest.json`, `README.md`,
`docs/FEATURES.md`, `docs/ANIMATIONS.md`, `docs/CHANGELOG.md`

## [2.31.1] - 2026-07-28 (Mood palettes get radial hue travel)

Data-only change: `tools/palettes/palettes.json` re-authored, `src/anim_palettes.h` regenerated by
`tools/gen_palettes.py`. No firmware logic touched. Build-verified; **not yet observed on hardware**
— the on-strip look is what decides these values, so expect a live-tuning pass.

### Changed
- **All four mood palettes now travel hue from ring to ring.** Every mood was previously a single
  hue that only got lighter toward the center (Golden hour was amber on amber on amber), so a bloom
  animation on any mood read as one flat wash — most visibly on nudges, where Golden hour is the
  factory default and Bloom Ripple came out one red-orange no matter what. Each palette now steps
  hue outward-to-inward while still brightening toward the core:
  - Golden hour: red-orange rim → amber → gold → pale gold core (38° of hue travel)
  - Moonlight: violet rim → periwinkle → ice blue → cool white core (77°)
  - Dawn: rose rim → coral → peach → cream core (57°)
  - Twilight: indigo rim → blue → sky → pale cyan core (55°)

  Authored gamma-aware as before (`rings` = inverse-gamma of `target`); the `target` field in
  `palettes.json` now records the intended on-strip appearance for every ring.

## [2.31.0] - 2026-07-28 (Launch-audit fixes: the nudge story made true, first-run un-broken)

Overnight implementation of the ultra launch audit's confirmed findings. Every change below is
build-verified on both variants and the web UI was exercised against a mock device in a browser;
none of it has been observed on hardware yet — flash and check before shipping it to a stranger.

### Added
- **Nudge escalation.** The second and later unacknowledged reminders play a second swell ~6s
  after the first, so a nudge that went unnoticed asks twice. RAM-only counter; nothing persists.
- **Button acknowledgment.** Pressing either clock button during a nudge (or within 15s after)
  now reads as "seen it": it clears the escalation counter and restarts the interval. It no
  longer adjusts the time — the old behavior corrupted the clock as the only physical response
  to a reminder. Time adjustment works exactly as before outside the ack window.
- **First-run time zone banner.** When no zone has ever been saved (new `tzConfigured` flag in
  `/settings` JSON, backed by NVS), the web UI shows a banner with the browser's detected zone
  and a one-tap apply. Dismissable; never returns once a zone is saved.
- **Quick nudge control.** On/off + interval + save, in Quick controls, two taps from landing.
  Preset buttons (Pomodoro 25m / Check-in 30m / Hourly) in the reminder section.
- **Time-truth cue.** Until NTP lands or the user sets the time by hand, a short amber inner-ring
  chase fires every 10s — "plausible but unconfirmed" is now visibly different from "set".
  Respects the status-blips toggle. New `STATUS_TIME_UNSET` status color.
- **Offline DST tick.** Local time is re-derived from the epoch once a minute while WiFi is down,
  so a DST flip lands on time offline. Suppressed after a manual time set — offline, the user's
  hands are the better truth.

### Changed
- **Factory reminder days: none → all seven.** daysMask 0 meant enable+save silently never fired —
  the audit's top story-killer. Reminders still ship disabled; nothing fires unasked. The UI also
  guards the same trap: enabling with zero days checked auto-selects all seven and says so.
- **Start hour == end hour now means a 24-hour window** (was: silently never fires).
- **Save saves everything.** The main Save button now collects reminder and animation-style
  fields too; it used to silently revert unsaved edits in those sections on completion. The
  sectional save buttons remain.
- **Save/error feedback.** Every save path now shows a toast ("Saved" / "Could not reach the
  clock"); fetch failures no longer fail silently.
- **Portal timeouts.** Fresh-flash first boot: 10-minute provisioning window (was 2, shorter than
  a stranger's join-the-AP fumble). Factory reset: 15 minutes (was forever — a reset clock hung
  dead until provisioned; it now falls through to AP mode and an offline clock).
- **Mobile usability.** 16px inputs (stops iOS focus auto-zoom), 42px touch targets, savebar wraps.
- **Labels de-jargoned.** "Outer sec/min" → "Second/Minute hand", "Status" → "Wi-Fi status blips",
  "Hourly bloom" → "Hour-top center bloom", GW/RSSI → gateway/signal. Page and title now say
  ChronoBloom, not "ESP32 Ring Clock". POSIX TZ field hidden unless "Other" is picked.
- **Reminder preview fix.** Previewing "Use quarter/half/hour animation" (modes 0-2) works; the
  0-is-Off guard now applies only to the interval selects.

### Hardened (same session, after a 7-agent adversarial review of the diff)
- **Ack window redesigned.** The first cut re-armed the window on every acknowledgment, so
  holding a button to adjust time got eaten as endless acks. The window now opens only at fire
  time and closes on the first ack; the next press adjusts time normally. Signed-delta compare
  makes a stale window harmless across millis() wrap.
- **Escalation moved inside the day/hour window** (an edge-straddling repeat is dropped, never
  played into quiet hours) and all reminder RAM state clears on disable, so nothing can strand
  across a disable/re-enable.
- **Portal classification fixed:** captive-portal/Improv-provisioned units (credentials only in
  the WiFi-stack NVS) were misread as never-provisioned and would have sat 10 minutes in the
  portal on every boot-before-router power blip; `getWiFiIsSaved()` now counts.
- **Save refuses to run from a page that never finished loading** (would have posted browser
  defaults over the deployed config). The daysMask auto-repair on the main Save is now visible
  (checks the boxes, toasts) instead of silent. Quick nudge confirmation names the active hour
  window, so an evening enable outside it doesn't read as broken. Timezone banner only
  dismisses when the save landed; error toasts distinguish "clock rejected it" (shows the
  reason) from "unreachable". Brisbane zone option added; delegated-chime previews explain
  themselves when the chime is Off; checkboxes exempted from the 42px mobile rule.
- Web NTP "Sync to internet" now lifts the manual-time override inside syncNow() itself, so
  the offline DST tick resumes after any accepted network sync.

### Verified
- Both variants compile clean (8" 61.1% flash). Web UI reconstructed from PROGMEM: tags balance,
  JS parses under node, and every new behavior (banner apply, quick save, 0-days guard, unified
  Save payload, presets, toasts, the loaded-page save gate, window text, chime-off hint)
  exercised against a mock device server in a real browser.
- NOT yet verified on hardware: escalation timing, ack window feel, portal timeout fallthrough,
  offline DST tick, amber time-unset cue.

## [2.30.1] - 2026-07-27 (On-wall verdict fixes: ChronoBloom hand contrast + Sunflower export honored)

The operator flashed 2.30.0 to both units and judged it on the wall — the real gate. Two failures,
both fixed the same evening:

### Changed
- **ChronoBloom inner hour hand: magenta → periwinkle `#6eb9ff`.** Both hour-hand segments had been
  the identical magenta since v2.4.8 ("unified for visual continuity"), so the middle/inner pair had
  ZERO hue contrast — and the 2.22.1 gamma pipeline shifted that magenta's emit toward hot pink,
  which is why the operator remembers the hands carrying "a tone of blue" that is now gone. The
  periwinkle echoes the outer marks (theme identity), reads azure `(40,126,255)` against the warm
  inner face (164 deg separation, 8.9x luminance pop), and sits 102 deg from the magenta middle
  hand. Emit-verified through the exact pipeline. `defaults()` updated to match (defaults ARE the
  ChronoBloom theme).
- **ChronoBloom face scales 55/55 → 39/39** — the same D/255 lift rebalance already applied to
  Ember/Lotus, restoring the lifted crest to the canonical 55-equivalent luminance so the middle
  hand keeps its authored 4.7x pop instead of the 3.3x the 2.30.0 lift left it.
- **Sunflower petalDepth 40 → 0.** The theme chip was forcing petal texture onto the operator's
  hardware-tuned export (whose exported petalMode was OFF): depth 40's lift pushed the huge face
  scales (181/244) to near-max and drowned the dark-red silhouette hands — observed live on the 15"
  wall clock as "contrast between hour hands is poorer." The export is now honored verbatim; the
  depth slider remains for anyone who wants texture on it.

### Deployed
- OTA to both units the same evening (15" wall clock first — it is the display the verdict came
  from — then the 8"), plus a one-time `petalDepth=0` settings restore on the 15" to undo the value
  the 2.30.0 chip-apply had already persisted into its EEPROM.

## [2.30.0] - 2026-07-27 (Petal depth that actually reads + two honest brightness sliders + capture pre-roll)

What the 8" demo-reel shoot needed. "Scalloped" is gone as a term: it reads as a cooking technique,
not an amount of shading. The feature is **Petal depth** everywhere now -- firmware field, web UI
label, theme key, narration. And the three-slider auto-brightness stack ("Darkest / Brightest /
Overall dimness") collapses to the two sliders that mean something.

### Changed
- **Petal shading applies to all three rings, from one shared profile.** Before, the outer 60 had
  none at all and the two inner rings used different profiles -- middle 24 a `[70%,100%,70%]` triangle,
  inner 12 a `[100%,60%]` every-other-LED alternation that reads as dither rather than petals. That is
  the "not all rings convey it equally" complaint, and it was literally true. Now every ring runs the
  same crest-to-seam profile off `PETAL_SHADE_*` + `petalFactor()`, so at any depth all three sit at the
  identical seam/crest ratio (verified by simulation at depths 0/30/45/60/70/100).
  - outer 60: 12 petals x 5 LEDs, crest **on** the 5-minute marker. **Markers are never shaded**, so the
    hour marks stay crisp and gain contrast against the shaded filler either side of them.
  - middle 24: 8 petals x 3 LEDs, crest at `i%3==1` (the v17 phase, unchanged).
  - inner 12: **4 petals x 3 LEDs** (was 6 x 2). Same cell as the middle ring -- identical profile is what
    makes them read equally -- and phased so its crests land on the same radial spokes as the middle
    ring's (middle `2i+1` faces inner `i`). Result: four strong spokes at 12/3/6/9 with finer petals
    filling in between.
- **`petalMode` (0/1) → `petalDepth` (0-100), SETTINGS_VERSION 18→19.** Same byte, same offset, no
  struct growth. Depth 0 makes `petalPixel()` collapse to the plain flat fill, so the old solid-fill
  branch is gone entirely -- one render path instead of two to keep in sync. `PETAL_SHADE_MAX = 170`
  caps a full-depth seam cut: deep, never black.
- **The contrast math got a real fix, not just a knob** (`petalPixel()`, replacing the first-pass
  post-gamma multiply). Measured on ChronoBloom's middle face at day brightness 44, the v17-style cut
  produced a crest of (6,0,4) against a seam of (4,0,2) -- quantization noise, not a petal, which is
  why the default theme "really has no contrasting petals." Two changes, both simulated end-to-end
  through the exact emit pipeline before landing:
  - **The seam shades the COLOR before gamma** -- a linear-light cut reads at roughly half its size
    perceptually; pre-gamma it reads at face value. The level multiply itself stays post-gamma, so
    this does NOT reintroduce the v2.22.0 pre-gamma-level crush (only the deliberate petal shading
    term moves).
  - **The crest is lifted by 255/D** (D = deepest seam factor), so depth adds contrast instead of only
    ever dimming the face: the crest gains what the seam loses.
  - Net effect on ChronoBloom's middle face, perceptual (sRGB) channel delta crest-to-seam: 11→18 at
    global brightness 44, 12→29 at 128, 17→39 at 255. Roughly 2.3x, and it scales with depth.

- **Auto-brightness is two sliders now: Darkest and Brightest.** The third slider ("Overall dimness",
  the v18 gain) is retired -- its label read backwards (lower = dimmer), and mathematically it
  multiplied the lux curve BEFORE the min/max clamp, so it could shove the whole response under the
  Darkest floor and pin the face there with the sensor effectively ignored. The new response
  (`autoSpanMap()`, one shared definition used by the renderer, `/diag`, and the serial status log)
  stretches the sensor curve's native 15..255 output across exactly
  [Darkest..Brightest]: pitch black lands ON the Darkest slider, full daylight ON the Brightest
  slider, and neither slider can ever be silently defeated. "Dim the whole clock" is now simply
  "pull Brightest down."
  - **Migration folds the stored gain into Brightest** so no deployed unit's daylight peak jumps:
    old peak = clamp(255 x gain%, min, max) becomes the new max exactly. Simulated against every
    real config (factory 60%, operator 51%, edge 0%/100%) across the full curve: endpoints exact,
    worst mid-curve deviation 5 counts of 255. Factory default Brightest becomes 153 -- the same
    daylight peak the old defaults (max 255 x gain 60%) actually produced.
  - The gain byte stays in the struct as `reservedGain` (zeroed) so the EEPROM layout is untouched;
    `autoBrightnessGain` is gone from the web UI, `POST /settings`, `GET /settings`, and `/diag`.

### Added
- **"Petal depth" slider (0-100) in Ring colors**, replacing the "Petal texture" checkbox, and moved
  below the last ring row since it is no longer a rings-1-&-2 setting. Live WYSIWYG preview mirrors
  `petalPixel()` -- pre-gamma tint, truncating lift, same integer math -- and was verified to emit
  **byte-identical hex** to a Python simulation of the firmware pipeline at depths 0/45/100 on all
  three rings, crest and seam and the outer ring's edge shade alike.
- **Per-theme petal depth**, replacing the on/off flag: ChronoBloom 45, Moonflower 60, Cherry Blossom
  60, Ember Dahlia 70, Lotus Pond 65, Sunflower 40, Bird of Paradise 50. Chosen against each theme's
  own fill brightness -- bright/pale fills carry more shading before the seam muddies; dark fills need
  less. ChronoBloom and Sunflower were previously OFF and now carry a deliberately gentle amount.
- **Full-roster beauty audit through the emit pipeline** (all 7 themes x 12 emitted swatches x 2
  brightness regimes, scored against the project's own design rules: hand/face separation, 45-60
  face band, saturation floor, center-warmest, harmony template, channel-quantization health).
  Findings: the roster is sound under its own templates -- the analogous themes' sub-60-degree
  hand/face hue seps are their declared designs carried by luminance hierarchy, Lotus's soft aqua
  marks are the 2.24.0 author's deliberate choice, and Sunflower's inverted hierarchy is an
  operator hardware-tuned export (untouched on principle). One real defect found and fixed: **the
  B+C crest lift broke the "dim petal wash, bright stamen" hierarchy on three rings** -- Ember
  Dahlia's inner hand fell to 0.6x its lifted face crest (the red hand drowned in the gold corona),
  Ember middle to 1.7x, Lotus middle to 1.2x. Fixed by rebalancing those face scales so the LIFTED
  crest lands exactly at the 2.24.0-authored luminance (`scale_new = scale_old x D/255`): Ember
  middleFaceScale 55→29, innerFaceScale 60→32; Lotus middleFaceScale 50→28. Verified restored to
  the authored ratios to one decimal (3.2/1.2 vs 3.1/1.2; 2.2 vs 2.1). The themes.json design-rule
  comment now states the 45-60 face band applies to the lifted crest (`scale x 255/D`), so a stored
  sub-45 scale under high depth is legitimate. Known and accepted: at day brightness 44, seam
  bottoms quantize small channels to 1-2 counts (hue purifies toward the dominant channel) -- an
  inherent 8-bit floor, invisible on the diffuser at those counts and gone at daylight peak.
  Proof sheet with every emitted swatch delivered to the operator; on-wall eye check remains the
  final gate per FLORAL_COLOR_DESIGN's own guardrail.
- **Demo-reel capture pre-roll.** `POST /demo/start?delay=<seconds>` (0-60) holds the clock **fully
  dark** before the reel opens, so a camera can be rolling and settled and frame one is a fade-up out
  of clean black. Web UI: a "Pre-roll" seconds box next to the Demo button (default 5, remembered in
  localStorage), with a live countdown in the status line. `/demo/status` gains `preroll` +
  `preroll_ms`; `/demo/overlay` treats pre-roll as "not running" and stays blank, so no subtitle is
  ever composited onto the black lead-in. Handled on-device rather than by a browser timer so the
  countdown survives the tab being closed or slept.

### Fixed
- **`tools/themes/themes.json` had silently drifted from what ships.** It declares itself the single
  source of truth and `tools/gen_themes.py` stamps it into both `src/web_html.h` and
  `docs/publish/demo_reel_designer.html` -- but it still held the **pre-2.24.0** colors for Moonflower,
  Cherry Blossom, Ember Dahlia and Lotus Pond, and never carried `petalMode` at all. Running the
  generator would have silently reverted the shipped botanical palettes (e.g. cherry ring-3 back from
  burgundy `#662d3f` to `#64143c`). Rebuilt from the shipped values, verified field-by-field that no
  colour or level changed.
- **Sunflower and Bird of Paradise are real theme entries again.** They were hand-appended JS lines in
  `web_html.h`, so they existed in the clock's own UI but were **absent from the demo reel designer's
  roster entirely**. Both now live in `themes.json`; the two hand-appended lines are gone and all seven
  themes come from one generated line in each consumer.

### Migration
`SETTINGS_VERSION` 18→19 changes no field offsets and adds no bytes -- two bytes change MEANING.
The petal byte: a stored `1` read back as a v19 depth would mean "1% depth", i.e. silently off, so
`widenPetalFlag()` maps the old flag onto the default depth in the v17 and v18 branches; units at v15
and v16 never had the feature and are seeded flat (0). The gain byte: folded into `maxAutoBrightness`
in the v18 branch (see above) and zeroed; v15-v17 units never had a gain, so their max is already
their true peak and only the byte is zeroed. No settings wipe on any deployed unit.

### Files changed
- `src/main.cpp` -- `ClockSettings.petalMode` → `petalDepth`, `autoBrightnessGain` → `reservedGain`
  (retired); new `PETAL_SHADE_MAX` / `PETAL_DEPTH_DEFAULT` / `PETAL_SHADE_5` / `PETAL_SHADE_3` /
  `petalFactor()` / `petalPixel()` / `widenPetalFlag()` / `autoSpanMap()`; `SETTINGS_VERSION` 18→19;
  `SettingsStore::begin()` (v15/v16/v17 branches updated, new v18 branch with the gain fold),
  `defaults()` (Brightest 153), `sanitize()`; `ClockRenderer::renderFace()` (one precomputed-pixel
  shaded path across all three rings), `effectiveBrightness()` (span map); `/diag` and
  `logRuntimeStatus()` share `autoSpanMap()` and drop the gain field; `WebUi` settings POST parser +
  `settingsJson()`; `DemoMode::start()` / `stop()` / `loop()` / `rendersFaceNow()` / `statusJson()` +
  `preRollEndMs_`; `setupDemoModeRoutes()` (`?delay=`).
- `src/web_html.h` -- "Petal texture" checkbox → "Petal depth" slider (moved below the last ring row);
  `PETAL_S5` / `PETAL_S3` / `petalFactorJS()` / `petalTintJS()`; `draw()` B+C shading on all three
  rings; "Overall dimness" label + gain slider removed, auto helper text rewritten; `bindLive()`,
  `collectFaceParams()`, `saveBrightness()`, `loadSettings()`, `applyTheme()`; demo Pre-roll input,
  `startDemo()`, `updateDemoStatus()`; `OVERLAY_HTML` stays blank during pre-roll; regenerated
  `THEMES` line.
- `tools/themes/themes.json` -- rebuilt from shipped values, `petalMode` → per-theme `petalDepth`,
  sunflower + birdofparadise folded in, `_comment` palette names refreshed to the v2.27.0 set.
- `docs/publish/demo_reel_designer.html` -- regenerated `THEMES` line (now carries all seven themes).
- `platformio.ini` -- `FIRMWARE_VERSION` 2.29.0 → 2.30.0.
- `scripts/webui_mock_server.py`, `scripts/walkthrough/local_serve.py` -- mock `/settings` carries `petalDepth`.
- `scripts/walkthrough/callouts.json`, `narration.json`, `SCRIPT_DRAFT.md` -- `#petalMode` selector and
  "scalloped" wording replaced (the stale selector would have made the walkthrough miss the control).
- `docs/publish/DEMO_MODE.md` -- `?delay=` pre-roll, `preroll` / `preroll_ms` status fields.
- `docs/symmap.json`, `docs/FUNCTION_INVENTORY.md` -- regenerated.

### Verified / NOT verified
- **Verified:** clean warning-free builds, BOTH envs (`esp32c3_v3_8inch` + `esp32c3_v3_15inch`,
  61.1% flash). Petal math simulated end-to-end through the exact emit pipeline (truncating integer
  math, gamma LUT, sRGB re-encode): profile equality across rings, marker exemption, spoke alignment,
  depth-0 collapse to flat fill, and the perceptual-contrast numbers quoted above. Web UI driven live
  in a browser against `scripts/webui_mock_server.py`: zero console errors; preview emits
  **byte-identical hex** to the firmware simulation at depths 0/45/100 (mid/inner crest+seam, outer
  seam and edge shade); gain slider and label gone; `collectFaceParams()` / `saveBrightness()` /
  `loadSettings()` all exercised without throwing after the element removal (the first patch left a
  `qs('autoBrightnessGain').value` reference in `collectFaceParams` that WOULD have broken face saves
  -- caught by running the page, not by reading it). Gain-fold migration simulated across the full
  curve for factory 60% / operator 51% / 0% / 100%: endpoints exact, worst deviation 5/255. Pre-roll
  countdown + status lines render; `?delay=` clamps 0-60 both sides. Theme round-trip vs
  `git show HEAD`: no pre-existing value changed. `tools/theme_emit_check.py` PASS.
- **NOT verified on hardware.** Nothing in this release has been flashed or seen on LEDs. The
  per-theme depth values and the B+C look are authored judgements; the operator's eye on the 8" is
  the real check, and the sliders exist precisely so both can be retuned live. The auto-brightness
  span map has not been watched against a real lux sweep.

## [Docs] - 2026-07-17 (Launch item 6: README becomes a replication document. No firmware change; FIRMWARE_VERSION stays 2.29.0)

### Changed
- **README** is now a build-it-from-scratch guide, not a feature list. New "Build it, step by step"
  with six numbered steps, each carrying an observable verify gate, keyed to a new "If it does not
  work" troubleshooting table. BOM filled from `docs/publish/PROJECT_FACTS.md` §5: real links for the
  WESIRI 241-LED ring kit (~$26) and the VEML7700; four rows keep marked placeholder links; added the
  missing M3 heat-set inserts + bolts row. Diffuser set to 0.6mm printed PLA throughout (operator's
  2026-07-17 decision), replacing parchment/0.3mm language.
- **`docs/publish/PROJECT_FACTS.md`** §6 diffuser corrected 0.3mm → 0.6mm to match.
- **build_help issue template** now asks which numbered build step failed.

### Added
- **`docs/PRINTING.md`**: 8" print settings (monotonic top/bottom fill, full-coverage shells, speed
  caps) and the 0.6mm diffuser spec; ring outer diameters flagged as caliper-pending.
- **`.github/FUNDING.yml`**: Buy Me a Coffee sponsor-button scaffold, line commented until the owner
  supplies a username (a placeholder would render a 404 button). README Support carries a matching
  commented line. Not on the flasher page (someone mid-flash should not get a donation ask, and
  GitHub Pages prohibits payment processing anyway).
- Both new shippable files added to the export manifest; gate PASSES at 49 files.

### Outstanding operator data (item 6 is structurally complete; these are fill-ins)
- Four BOM purchase links (XIAO, buttons, PSU, resistor), the Buy Me a Coffee username, a wiring
  photo, and caliper-verified ring dimensions. The Amazon Associates ID `maestro8484-20` exists in
  PROJECT_FACTS; whether to append affiliate tags (with the required disclosure) is an owner decision,
  left untouched.

## [2.29.0] - 2026-07-17 (Improv Wi-Fi: configure Wi-Fi from the browser at flash time)

Pairs with the new browser flasher (`docs/flasher/`): ESP Web Tools can now also hand the freshly
flashed device its Wi-Fi credentials over the same USB-serial connection, no captive-portal detour
required for the common case.

### Added
- **Improv Wi-Fi serial support.** On a device with no saved Wi-Fi yet (fresh flash or post
  factory-reset), the clock listens for the [Improv](https://www.improv-wifi.com/) protocol over
  USB-serial for a bounded 10-second window before falling back to the existing WiFiManager
  captive portal. A browser-side Improv client (ESP Web Tools' own "Configure Wi-Fi" dialog) can
  supply SSID/password directly; the clock connects, saves the credentials to the same `wifi` NVS
  namespace the `/wifi` web page already uses, and reports success with the device's
  `http://<hostname>.local/` URL.
  - Protocol parsing/framing: official `improv-wifi/sdk-cpp`, pinned as `improv/Improv @ 1.2.6` in
    `platformio.ini`. That SDK ships packet parsing + frame building only (no Arduino serial glue
    is published upstream); the byte-framing in `ImprovSerialHandler::sendFrame()` (`src/main.cpp`)
    is ported from ESPHome's `improv_serial` component, the reference production implementation
    built on the same SDK.
  - Serviced non-blocking and byte-at-a-time inside `loop()`, only while the device is
    unprovisioned or in AP fallback — once connected, USB-serial can no longer silently
    reconfigure a running clock's Wi-Fi. The pre-flash window itself sits before `setupWiFi()` in
    `WebUi::begin()` and only runs when no credentials are already saved, so a normally configured
    clock's boot time is unaffected.
  - WiFiManager's captive portal (`esp32c3-clock-setup`, 192.168.4.1) is unchanged and remains the
    fallback for clients without Improv support.

### Unchanged
- `SETTINGS_VERSION` stays 18 — `ClockSettings` was not touched. Wi-Fi credentials, like the
  timezone string (2.28.0), live in NVS (Preferences), not in the fixed-size settings blob.

### Deferred (not verified this session)
- Button-hold factory-reset re-test against the new pre-window (should be unaffected — it forces
  the portal directly and never enters the Improv gate — but not exercised on hardware).
- End-to-end browser Improv dialog test against a bare device (no serial monitor "type the SSID by
  hand" substitute exists; needs ESP Web Tools' actual dialog).

## [2.28.0] - 2026-07-17 (Runtime timezone: the clock is no longer locked to the maintainer's zone)

The last setting that required a compiler. Until now `NTP_TIMEZONE_TZ` was a build flag, so every
binary (and every future web-flashed image) displayed US Mountain time and a builder in another zone
had to install a toolchain and recompile to fix it. That blocked the browser-flasher path from being
worth shipping. Now it is a runtime setting.

### Added
- **Time zone picker** in the web UI (Time & light → Time zone): 18 common zones plus an "Other"
  escape hatch that accepts any POSIX TZ string. Every shipped option is verified to pass the
  firmware's own validator, so the UI cannot offer a zone the device would reject.
- `tzone` namespace in `src/main.cpp`: `valid()` / `get()` / `apply()` / `save()` / `clear()`.
- `TimeSync::setTimezone()`. Changing zone re-derives local time from the UTC epoch already on the
  chip, so it takes effect **immediately, with no reboot and no NTP round trip** (the ESP keeps the
  system clock in UTC; only `tzset()` has to re-run).
- `timezone` exposed in `GET /settings` and `GET /diag`; accepted by `POST /settings`.

### Changed
- `NTP_TIMEZONE_TZ` in `platformio.ini` is now the compile-time **default** only: what a fresh or
  factory-reset unit starts on. Behavior for anyone who never touches the setting is unchanged.
- Factory reset clears the `clock` NVS namespace, so a reset unit returns to the build-time default,
  matching what the `wifi` namespace already does.

### Design note
The TZ string lives in **NVS (Preferences), not `ClockSettings`** — hence **`SETTINGS_VERSION` stays
18 and no unit migrates or loses settings**. Prior art decided this: the firmware already keeps
user-set strings in NVS (the WiFi credentials, `wifi` namespace), while `ClockSettings` is a fixed
84-byte POD blob behind a hard 128-byte EEPROM ceiling. A ~40-byte string would have consumed most of
the remaining 44 bytes of headroom and forced a migration on every deployed unit, buying nothing.

### Validation
`tzone::valid()` is a sanity check, not a POSIX parser: an invalid TZ string does not fail loudly in
the C library, it silently resolves to UTC, reaching the user as "the clock is just wrong by N hours"
with no diagnostic. It requires a plausible charset, a zone name, and at least one digit (every real
TZ string carries an offset). That rejects the two realistic failures: `GARBAGE`-class typos, and
IANA names like `America/Denver`, which users will try and which would otherwise silently mean UTC.
It also rejects quotes and backslashes, which keeps the unescaped `"timezone":"%s"` in
`settingsJson()` from being able to emit invalid JSON. `POST /settings` answers **400** on a rejected
string rather than storing it.

### Files changed
- `src/main.cpp` (tzone namespace, TimeSync::setTimezone, /settings POST, settingsJson, /diag, factory reset)
- `src/web_html.h` (Time zone row, `tzPicked`/`tzSync`/`saveTz`, loadSettings)
- `platformio.ini` (FIRMWARE_VERSION 2.27.3 → 2.28.0; NTP_TIMEZONE_TZ documented as a default)
- `docs/symmap.json`, `docs/FUNCTION_INVENTORY.md` (regenerated)

### Verified / NOT verified
Both variants build clean (8" and 15"). Validator logic checked against 14 real POSIX TZ strings
(including the `<+0330>` Iran and Lord Howe quoted forms) and 9 hostile inputs: all pass/reject as
intended. Web UI reconstructed from the PROGMEM chunks: tags balance (94/94 div, 14/14 select), the
30 KB of index JS parses under node, and all 18 zone options pass `tzone::valid()`.
**NOT verified on hardware** — no flash performed. The operator flashes OTA; confirm via `/diag`
that `timezone` reports the set zone and that the displayed time moves immediately without a reboot.

## [Docs] - 2026-07-17 (Launch audit session 2 part 1: export gate unjammed, docs fact-refreshed, two new ship gates. No firmware behavior change; FIRMWARE_VERSION stays 2.27.3)

### Fixed
- **Export gate was failing, blocking any re-publish.** Reworded the LAN IP out of the `LED_GAMMA`
  comment (`src/main.cpp`) and the v2.22.x gamma note (this file). Gate now passes at 44 files.
- **Shipped config carried maintainer machine defaults.** `upload_port = COM6/COM9` and the
  `upload_protocol` duplicates removed from both envs in `platformio.ini`; both shipped
  `scripts/upload_*.bat` echoed the same ports in their USB-fallback hint. Ports moved to the
  gitignored `platformio.local.ini` and documented in `platformio.local.ini.example`. PlatformIO
  auto-detects when `upload_port` is absent. Verified: maintainer ports still resolve, build clean.
- **Shipped docs contradicted shipped firmware.** `docs/ANIMATIONS.md`: palette table still listed
  the flower palettes removed in v2.27.0; reminder heading said modes 6-10 when Firefly is 11;
  Firefly had no entry despite being in the UI. `docs/FEATURES.md`: demo sequence claimed 8 steps /
  96 s / "8 color palettes" when `DemoMode::steps[]` is 9 steps / ~131 s with no palette step;
  theme list said "Classic, Aqua, Magenta" when the real list is 7 presets; reminder modes corrected.
- **Four dead links** in shipped docs pointed at `REVIEW.md` / `WORKFLOW.md`, which never ship.

### Added
- **Untracked-file gate** in `tools/publish/export_public.py`. The include globs walk the filesystem,
  not git, so any file dropped into a globbed directory shipped silently (this is how two scratch
  test-print 3MFs and one unreviewed STL entered the set). Checks source paths, not destination keys,
  which differ under the manifest's `relocate` map.
- **Relative-link gate**: every markdown link in a shipped doc must resolve inside the export set.
- Both gates were verified by injecting the exact failure they exist to catch.

### Changed
- Untracked 3D scratch files moved out of the ship path to `docs/3d_testprints/` (preserved, not
  deleted). One of them, `chronobloom-8inch-base-cutout (1).stl`, is NOT a duplicate of the tracked
  cutout and needs an operator decision on whether it is a real revision.
- `docs/LAUNCH_GAPS.md`: G2 (Windows clone failure) **refuted**. Session 1's clone failed only
  because the scratchpad it cloned into was ~140 characters deep; a clone to a normal path succeeds
  with long-path support off. The audit had measured its own environment, not the repo.

## [Docs] - 2026-07-16 (Launch audit session 1: gap manifest + README pass. No firmware change; FIRMWARE_VERSION stays 2.27.3)

### Added
- `LAUNCH_AUDIT_TEMPLATE.md` (audit doctrine, razor table, session plan) and `docs/LAUNCH_GAPS.md`
  (classified gap manifest: hard blockers file:line, stranger-walk verdicts G1-G19, session-2 build
  list, session-3 clean-room test plan).

### Changed
- `README.md`: fact-fix ("8 color palettes" was stale since the v2.27.0 palette simplification;
  now describes per-ring controls + theme presets + mood palettes) plus a dash/style pass with
  computed verification (digit/URL/link/code multisets identical, fenced blocks byte-identical).

### Found, not fixed (session 2 executes; see docs/LAUNCH_GAPS.md)
- Export gate currently FAILS on a LAN IP in `src/main.cpp:221` + `docs/CHANGELOG.md:277`
  (this file, the v2.22.x gamma note); public repo is 19 minor versions stale at v2.8.0.

## [2.27.3] - 2026-07-14 (Motion & nudges consolidation — de-dup preview/save, co-locate anim style)

Web-UI reorganization (web_html.h only; no firmware-logic or settings change). Addresses the R2-R4/R6
findings in `docs/UI_REDUNDANCY_2026-07-14.md`.

### Changed
- **All animation-style controls now live together** under Motion & nudges → "Animation style":
  Animation colors (chimes) · Speed · Brightness · Trail length · Reminder colors (nudges), with one
  Preview and one Save. Previously colors+speed were in Quick controls and brightness+trail+reminder-colors
  were in Motion — you had to touch two cards to tune one thing (R4).
- **Quick controls** slims to what you actually touch often: Theme chips + Brightness (with its own
  **Save brightness** button). Theme chips already set the whole animation style in one click.
- Second/minute-effects **"Trail length" → "Second-hand trail length"** to disambiguate it from the
  animation trail length (R6).

### Removed
- **Redundant "Preview slot" selector + its Preview button** (R2). The per-row ▶ buttons next to each
  Quarter/Half-hour/Hour/Reminder animation already preview that slot with the current unsaved style, so
  the slot-picker was a third, weaker way to do the same thing. The single "Preview" in Animation style
  previews the configured interval chime (hour → half-hour → quarter) in the selected colors.
- **Redundant second Save button** (R3). Quick "Save" and Motion "Save style" both persisted the same five
  animation fields. Now: "Save style" (Motion) saves the animation style; "Save brightness" (Quick) saves
  the brightness settings — one non-overlapping save per concern.

## [2.27.2] - 2026-07-14 (Firefly nudge — fix double-dimming, denser swarm)

### Fixed
- **Firefly reminder was ~`animBr`× too dim (root cause).** `animRem6` multiplied brightness by
  `animBr()` explicitly *after* `bandColor()` had already rendered at `animBr()` — a double application of
  animation-brightness that no other nudge does. At the default brightness that left Firefly rendering at
  ~0.6² instead of ~0.6 of a ring color, i.e. roughly `animBr×` weaker than its siblings. Removed the
  redundant factor so Firefly's peak matches the other nudges (still capped at `NUDGE_CEIL`).
- **Saved "Firefly" reminder reset to "quarter animation" on every reboot.** `sanitize()` clamped
  `focusReminder_animation > 10` to 0, but Firefly is value **11** (and POST already accepts 0-11), so a
  stored Firefly was wiped on the next boot. Changed the bound to `> 11`. (Firefly is the only option that
  was affected; the "(alt)" 3-5 removed in 2.27.1 were never > 10.)

### Changed
- **Denser Firefly swarm** so it reads as a clear cue: 9 → 14 twinkle points, hit rate ~43% → ~55%,
  period 1.6s → 1.4s; outer points placed on filler (non-marker) LEDs so a firefly isn't hidden under a
  bright hour marker. Warmer breathing core (amplitude 40±40 → 60±50).
- Still bounded — peak capped at `NUDGE_CEIL` (unchanged) and it repaints the idle face underneath, so it
  stays a gentle overlay, not an alert. **Perceptual result needs confirming on the 15" — tune the point
  count / hit rate / `NUDGE_CEIL` if it now overshoots.**

## [2.27.1] - 2026-07-14 (Web UI: smart Preview, scope labels, drop dead reminder options)

Low-risk web-UI clarity pass (web_html.h only; no firmware-logic or settings change).

### Changed
- **Quick-controls Preview is now honest.** It previewed a *hardcoded* "Galaxy spin" (hour mode 2)
  regardless of configuration. It now previews your **configured interval chime** — Hour, else Half-hour,
  else Quarter (first not "Off") — in the selected animation colors. Falls back to Galaxy spin only if all
  three interval slots are Off.
- **Scope labels** on the two color pickers so their purpose is explicit: `Animation colors (interval
  chimes)` (Quick controls) and `Reminder colors (nudges)` (Motion & nudges), each with a tooltip pointing
  at the other. They share one palette list but are independent selections (per v2.27.0).

### Removed
- **Dead "(alt)" reminder-animation options.** The `Reminder animation` dropdown listed *Use quarter/
  half-hour/hour animation (alt)* (modes 3-5), which call the identical firmware path as modes 0-2 (see
  `triggerReminderDirectAnimation`, main.cpp) — no behavioral difference. Dropped the three duplicates
  (12→9 options). Safe/non-destructive: a unit with a stored value of 3-5 is normalized on load to its
  identical 0-2 option (no empty dropdown), and firmware still renders 3-5 the same as 0-2.

## [2.27.0] - 2026-07-14 (Animation-palette simplification — one shared mood list)

Occam pass on the animation colors (operator directive: *"too many options is the same as poor
options"*). Theme-specific animation palettes made no sense — you already picked a theme; the
animation should follow it. The two separate palette systems collapse onto **one shared 5-option
list** that applies to both interval chimes and reminders.

### Changed
- **One shared palette list** replaces the 10 flower palettes + 4 separate reminder palettes:
  `Clock colors (default)` + 4 temperature/mood palettes — **Golden hour (warm)**, **Moonlight (cool)**,
  **Dawn (soft-warm)**, **Twilight (muted-cool)**. Both the **Animation colors** dropdown (chimes) and the
  **Reminder colors** dropdown (nudges) now offer the *same* five options, so a nudge can still be set to
  read differently from a chime (design option b).
- **Reminders can now use Clock colors** (index 7) — previously reminders were locked to the mood set;
  the `pal==7` face-mapping now resolves in the reminder render path too.
- **Renamed** the cool mood `Moonflower`→`Moonlight` (it collided with the *Moonflower* clock theme name,
  a real source of confusion); re-authored `blush`→`Dawn (soft-warm)` and `calm`→`Twilight (muted-cool)`
  with new values.
- **Gamma-aware palette values.** The mood palettes are now authored through the gamma pipeline
  (`gammaColor`, gamma 2.2) — seeds are inverse-gamma of the intended on-strip appearance, replacing the
  pre-gamma (v2.21.0-vintage) values that had been rendering too dark since gamma landed in v2.22.1. The
  generator/header no longer claim "no gamma". **Seeds need live confirmation on the 15" — they will
  render brighter than the current (gamma-darkened) moods.**
- **Palette handling unified.** New `sanitizePaletteValue()` is the single definition of a valid palette
  ({0-3 moods, 7 Clock colors}); used by `sanitize()`, POST `/settings`, and the preview path. Any
  unknown/removed/out-of-range value → 7 (Clock colors), uniformly (fixes the stale-client-POST and
  theme-import edge cases where an out-of-range index could land on the wrong palette or an empty dropdown).
- **`tools/palettes/palettes.json`** → single `mood_palettes` array; **`tools/gen_palettes.py`** emits one
  `MOOD_PALETTE_RINGS` + `MOOD_PALETTE_COUNT`. `main.cpp` renderer resolves both palettes through a shared
  `curPalette()`/`anchorColor()`.

### Removed
- The 10 flower animation palettes (`Ember, Coral, Lagoon, Dusk, Nocturne, Tropic, Prism, Thunderstorm,
  Sunny, Blue Paradise`) and the 4 old reminder palette definitions. The `Sunflower` and
  `Bird of Paradise` clock themes now point their `animationPalette` at Clock colors (7).

### Notes
- **No `SETTINGS_VERSION` change** (stays 18): the `ClockSettings` struct layout is unchanged —
  `animationPalette`/`reminderPalette` are the same bytes, only their value *meaning* changed. Deployed
  units keep every setting; stored values self-correct via `sanitizePaletteValue()` (removed flower
  indices → Clock colors; old reminder 0-3 → same-index new mood).
- **Reversible:** all removed palette data (json, generated C, swatches, dropdown labels) archived verbatim
  in `docs/archive/flower_palettes_2026-07-14.md` with a re-import checklist.

## [2.26.1] - 2026-07-14 (Remove "Go Pack" theme + "Green & Gold" animation palette)

Removed the NFL "Go Pack" clock theme and its paired "Green & Gold" animation palette (index 11) for
aesthetic consistency with the clock's botanical identity. Non-destructive and reversible.

### Removed
- **`THEMES.gopack`** preset (web UI theme chips are generated from `THEMES`, so the chip disappears
  automatically) and its `animationPalette` dropdown option + swatch.
- **"Green & Gold" animation palette** (idx 11) from `tools/palettes/palettes.json`; regenerated
  `src/anim_palettes.h` (`ANIM_PALETTE_COUNT` 12→11).

### Notes
- **Non-destructive to deployed units:** no `SETTINGS_VERSION` change (palette count is compile-time, not
  struct layout). A unit currently set to `animationPalette 11` falls back to 7 (Clock colors) via
  `sanitize()`; stored face colors are untouched.
- **Fully reversible:** every value (theme preset, palette RGB, swatch, dropdown) is archived verbatim in
  `docs/archive/gopack_theme_2026-07-14.md` with a re-import checklist.
- Also refreshed two stale `animationPalette` enumeration comments in `main.cpp` to match the real palette
  names (they still listed long-renamed palettes like "Snowstorm"/"Wildflower").

## [2.26.0] - 2026-07-14 (Auto-brightness gain — dimmer & hue-safe, lux keeps directing brightness)

Acts on the 2.25.1 diagnosis. A live lux sweep on the 15" confirmed the mechanism was **Hypothesis C**
(the `maxAutoBrightness` clamp pinning the top of the response flat — `effective` stuck at 108 from
300→10000 lux), **not** the current limiter (est. draw peaked ~261 mA vs the 1800 budget — B ruled out).
The operator's unit had `maxAutoBrightness=108`, i.e. it was already using the clamp as a dimmer, which is
exactly what flattens the high end. This release replaces that with a proper downward scale.

### Added
- **`autoBrightnessGain` setting (SETTINGS_VERSION 17→18,** appended byte, in-place v17→v18 migration —
  deployed units keep every setting, no wipe; seeded to **60%**). A 0–100% multiplier applied to the
  lux-derived auto-brightness curve *before* the min/max clamp. Because it scales the whole curve down, it
  (a) dims the display overall and (b) pulls the top of the curve back under `maxAutoBrightness`, so lux
  keeps directing brightness across the full range instead of clamping flat. Multiplicative → the response
  *shape* (relative intensity between rings/elements) is preserved.
- **Web UI:** "Overall dimness" slider in Brightness → Auto, wired through preview/save/quick-save and
  reflected in `/diag` (`auto_brightness_gain`) and the serial runtime log.

> Note: as with every `SETTINGS_VERSION` bump, a **saved user-defaults** block from v17 is not carried
> across (the user-defaults slot is version-gated and has no migration). If you'd used "Save as my
> defaults", re-save it after flashing so `/settings/reset` restores your profile instead of factory.

### Changed
- **The global auto-brightness dim is now hue-safe.** The face `render()` path draws at full brightness,
  then dims via a new `scaleStripBufferVideo()` (WLED `color_fade`-style: any originally-nonzero channel
  stays ≥1) instead of baking the dim in through Adafruit `setBrightness()`, whose per-channel truncation
  drops small color channels to 0 first and walks saturated colors toward their primary as the clock dims —
  the reported "lux shifts hue, not brightness" artifact. `masterFade` keeps the exact scaler (a dissolve
  genuinely wants true black at f=0). Animation frames are unchanged (they manage their own envelopes).

## [2.25.1] - 2026-07-13 (Lux-override diagnostics — instrument the brightness/lux path)

Instrumentation-only release to disambiguate the operator's lux→brightness report ("lux changes
affect hue more than brightness; response varies by ring"). No change to the rendering or color
pipeline. Enables a full-range remote lux sweep + makes the current limiter observable.

### Fixed
- **`POST /demo/brightnessCycle` self-cancelled and drove no brightness change** (observed live on
  2.25.0). `DemoMode::loop()` computed `se = now - standaloneBrightnessStartMs_` with `now`
  snapshotted at loop-top, but `startBrightnessCycle()` sets the start stamp *later in the same
  iteration* (inside `webUi.loop()`'s POST handler), so `now < startMs` and the unsigned subtraction
  underflowed to ~4.29e9 — tripping the done-branch and disabling the cycle before it ever called
  `setLuxOverride()`. Now clamped to 0 on that first iteration. (Also un-breaks the reel designer's
  Live Run brightness segment, which shares this path.)

### Added
- **`GET /lux/override?lux=X` / `?clear=1`** — diagnostic route to pin the sensor to any lux value
  (full 0.1..10000 range; the built-in demo sweep only covers 1..220) so brightness response can be
  swept remotely and held steady for photos. Reuses the existing `setLuxOverride`/`clearLuxOverride`.
- **`/diag` limiter fields: `est_milliamps`, `limiter_brightness`, `max_milliamps`.** The current
  limiter (`ledShowBudgeted`) rescales brightness at `show()` time and was invisible to `/diag`;
  when `limiter_brightness` drops below `effective_brightness`, the limiter is actively fighting the
  lux-driven brightness (Hypothesis B). `est_milliamps` vs `max_milliamps` shows the headroom.

## [2.25.0] - 2026-07-13 (Petal texture — scalloped ring fills like real petal whorls)

New user-facing feature (ships in the same flash as the 2.24.0 color work below).

### Added
- **`petalMode` setting (SETTINGS_VERSION 16→17,** appended byte, v16→v17 in-place migration in
  `SettingsStore::begin()` — deployed units keep every setting, no wipe). 0 = solid fills (default).
- **Firmware:** `renderFace()` petal branch — middle 24 = 8 petals of 3 LEDs `[70%,100%,70%]`, inner 12 =
  6 petals of 2 LEDs `[100%,60%]`, phase-offset so the whorls interleave like real petal layers. Factors are
  brightness ops on the already-corrected ambient (single-gamma invariant preserved).
- **Web UI:** "Petal texture" checkbox (Ring colors), full wiring (`petalMode` POST arg, `/settings` JSON,
  live WYSIWYG preview renders the scallop). Themes: ON for Moonflower / Cherry Blossom / Ember Dahlia /
  Lotus Pond / Bird of Paradise; OFF for ChronoBloom and the operator-tuned Sunflower / Go Pack exports.
- Note: `Reset` with pre-v17 user-defaults falls back to factory defaults (stored block is version-checked).

## [2.24.0] - 2026-07-13 (WYSIWYG web preview + theme remap: operator exports + crushed-fill lifts)

Gamma-2.2-on-color/linear-brightness pipeline (2.22.1/2.23.0) verified byte-identical to WLED source
(`docs/WLED_PARITY_2026-07-13.md`) and untouched. This release fixes the two broken halves of the color
CONTRACT (`docs/RETRO_COLOR_2026-07-13.md`): stale theme data and a preview that lied.

### Changed
- **Web-UI clock preview is now WYSIWYG.** `setLed()` renders each LED through the exact firmware pipeline
  (`ledDisp()`: round-half-up gamma-2.2 → integer-truncated level scale → sRGB re-encode for the monitor);
  `draw()` folds `outerRingBrightness` into ring-3 marker/filler exactly as `renderFace()` does. The on-screen
  clock now shows what the LEDs emit — dark-crushed fills look dark on screen too.
- **Sunflower + Go Pack re-authored from the operator's hardware-tuned Export-Theme json (verbatim).**
  Sunflower is now a light-face/dark-hands design (bright gold fills, deep red hands, dim markers).
- **Moonflower / Cherry Blossom / Ember Dahlia / Lotus Pond / Bird of Paradise re-authored from RESEARCH-SOURCED
  botanical palettes** (color-hex.com, SchemeColor photo-extractions, etc. — cited in the session log). Each
  sourced display color was inverted through the exact firmware transform (gamma → level → ring-brightness) so
  the LED emits the intended hue. Notable: cherry ring-3 is now burgundy `#662d3f` (was bright red), Bird ring-2
  is a slate blue-gray bract (operator spec; no botanical hex exists) and ring-1 deep foliage green.
- **New ship-gate: `tools/theme_emit_check.py`** — byte-exact emit simulation of every THEMES field; fails any
  field whose dominant emitted channel is below 10 at day brightness. Current tree: PASS (all 8 themes).

**NOT yet hardware-verified** — operator flash + eye is the check. ChronoBloom + Ember/Cherry hands & several
markers are original (not yet reviewed on the corrected pipeline); Sunflower + Go Pack are operator exports.

## [2.23.0] - 2026-07-13 (Unified color pipeline: one correction chokepoint for every color — precision first)

Guiding philosophy going forward: **precision (consistency + reproducibility) before accuracy (closeness to
truth).** Every raw sRGB *design* color in the firmware now routes through ONE chokepoint — `gammaColor(r,g,b)` —
so correction is applied exactly once and uniformly across the entire display. Previously face/hands/markers/
animation palettes were corrected (via `ringColor`) while 6 paths wrote raw `strip_.Color()` and bypassed
correction entirely (found by MAD/Codex): status indicators, hourly chime, bloom stamen core, Galaxy-Spin star
tints, WiFi-portal fill, factory-reset fills. That inconsistency is the "front falling off." Now unified.

WHAT the correction is (gamma value, future white balance) lives solely in `ledGamma()`/`ledGammaInit()` — change
it there and every color follows. That is the accuracy knob, deliberately separated from the plumbing.

Face/theme/animation colors are **mathematically unchanged** from 2.22.1 (`scale(gammaColor(r,g,b),level)` ≡ the
old inline `ledGamma`-then-×level). Only the 6 formerly-bypassed paths change appearance (now gamma-corrected).

**NOT yet hardware-verified.** Known accuracy follow-up: some low-value diagnostic colors (e.g. the idle status
head `40,40,40`) dim substantially under gamma and may need their raw values bumped for visibility — an accuracy
tweak, made in one place, not a precision regression.

### Changed
- New `gammaColor(uint8_t,uint8_t,uint8_t)` — the single color-correction chokepoint (packs 0x00RRGGBB via
  `ledGamma` per channel). Documented invariant: compositors (`blendMax`/`blendOver`) and brightness ops
  (`scale`/`dim`/`pulse`) receive already-corrected colors and must NOT re-route through it.
- `ringColor()` → `scale(gammaColor(r,g,b), level)` (identical result). `renderCenterIdle()` → same idiom.
- Routed through `gammaColor`: `renderStatus`, `renderHourlyChime`, `stamenColor`, Galaxy-Spin tints, WiFi-portal
  fill, factory-reset fills. `ledCorrect()` remains a no-op.
- `FIRMWARE_VERSION` 2.22.1 → 2.23.0.

## [2.22.1] - 2026-07-13 (Fix: gamma applied to color BEFORE brightness, not on output buffer — dark inner/middle rings)

2.22.0 applied the gamma-2.2 LUT to the finished output buffer (`ledCorrect`), which runs AFTER `renderFace`
pre-dims the ambient fills via `scale(ringColor(color,255), middleFaceScale≈55)`. Gamma then hit `0.22·color`
and crushed the scale factor itself (`0.22^2.2≈0.03`, ~6× extra dimming) → inner/middle ring fills emitted
near-black on hardware (observed on the 15" at 2.22.0; hour hands + center use level 255 so were unaffected).
Same failure class as the reverted gamma-2.8 attempt. Fix: gamma now applied to the pure COLOR before the
per-ring level/scale multiply — WLED's documented "gamma on color, brightness after" ordering (its own code
warns "applying gamma after brightness has too much color loss"). **NOT yet hardware-verified — needs operator
flash + visual check on both variants.**

### Changed
- `ringColor()` (`src/main.cpp`): gamma-correct r,g,b via `ledGamma()` before the `×level` multiply. Covers
  face, hands, markers, and all animation colors (which route through `bandColor`/`bloomColor`/`paletteColor`).
- `renderCenterIdle()`: center bypasses `ringColor`, so gamma its color before the `amount` scale too.
- `ledCorrect()`: now a no-op (was the buffer-gamma). Correction lives at the color stage; no double-gamma.
- New `ledGamma(uint8_t)` helper (LUT unchanged). Hardcoded status/chime diagnostic colors remain raw.
- `FIRMWARE_VERSION` 2.22.0 → 2.22.1.

## [2.22.0] - 2026-07-13 (WS2812B output pipeline → WLED reference: gamma 2.2, white-balance scaling removed)

Replaced the output color correction to match the operator's verified WLED "Color & White" reference config
(screenshot from a WS2812B WLED 16.x reference rig; gamma implementation verified against
github.com/wled/WLED `wled00/colors.cpp`). The former linear white-balance scaling (green×176/255, blue×240/255)
fought warm mid-tones (gold/amber skew); it is removed. In its place, a 256-entry output gamma LUT
`gammaT[i]=pow(i/255, 2.2)*255` is applied identically to R, G, B on the finished GRB buffer right before show(),
exactly as WLED does. Distinct from the animation-shaping `gamma8()` (unchanged). Version 2.22.0 (skips the
poisoned 2.21.2 stuck on the 15" unit). SETTINGS_VERSION unchanged (16); no migration. **NOT yet hardware-verified
— needs operator flash + visual check.** Theme hexes were hand-tuned against the old pipeline and may need
re-tuning after this lands (the downstream theme task).

### Changed
- `ledCorrect()` (`src/main.cpp`): linear G×0.69 / B×0.94 white-balance scaling → gamma-2.2 LUT on all channels.
- New build flag `LED_GAMMA` (default 2.2). `LED_CORRECT_ENABLED 0` still bypasses correction entirely.
- `FIRMWARE_VERSION` 2.21.1 → 2.22.0.

## [2.21.1] - 2026-07-13 (Theme fills redone as radial ring gradients — Bird of Paradise + Go Pack)

The three ring-fill fields (outerFiller → middleFace → innerFace) were painting near-identical hues, wasting the
3-ring + center radial structure. First two themes redone so the four fills form an intentional radial gradient
with visible ring-to-ring boundaries, tuned in a WS2812-honest mock (per-field level scaling → FastLED-style
warm correction G×176/255, B×240/255 → gamma-encoded to match the strip's linear output). Remaining 6 themes
pending hardware validation of this color model. FIRMWARE_VERSION 2.21.0→2.21.1; SETTINGS_VERSION unchanged (16);
theme recolor is wire-safe (no migration).

### Changed
- **Bird of Paradise** fills → real cobalt→azure→teal→fiery-orange sweep. Was 3 near-identical cobalt blues
  (`#10309C`/`#12369C`/`#0C2680`, mid-face scales 55/50). Now outerFiller `#0E28DC` (cobalt, level 120→135),
  middleFace `#1488D2` (azure, scale 55→95), innerFace `#10B48C` (teal, scale 50→90), center `#FF7A1E`→`#FF5A00`
  (fierier, level 190→205). Orange markers/hands unchanged in hue (marker level 230→225, hours `#FF6410`→`#FF7014`).
- **Go Pack** greens now brighten inward + golds deepened (were washing pale on hardware). Fills: outerFiller
  `#0E2A16`→`#08301A` (deep pine, level 120→130), middleFace `#16401F`→`#14702E` (forest, scale 55→90),
  innerFace `#0E2A16`→`#24B445` (emerald, scale 50→82, no longer muddy-dark), center `#E0A814`→`#D48806`
  (level 190→200). Golds deepened: outerMarker `#D4A017`→`#A86A00` (level 235→205), hours/minutes `#D4A017`/
  `#C8960C`→`#B47A06` (hours level 255→235), innerHour `#C8960C`→`#A86400` (level 255→235).

## [2.21.0] - 2026-07-12 (Go Pack gets true green/gold animations — new "Green & Gold" palette)

Follow-up to 2.20.0: Go Pack was animating gold-only (the "Clock colors" palette maps the gold hands/marks,
not the green fill). Added a dedicated green/gold animation palette so Go Pack's animations read green + gold.

### Added
- **"Green & Gold" animation palette** (index 11): forest-green rings + gold throat/core, no sparkle. Go Pack
  now uses it (animationPalette 7→11). `ANIM_PALETTE_COUNT` 11→12; palette VALUES unchanged for 0–10;
  SETTINGS_VERSION unchanged (16).

## [2.20.0] - 2026-07-12 (Sunflower + Bird of Paradise themes; drop Snowstorm/GreenNGold; UI polish)

Palette + theme roster tuned toward more vibrant, high-contrast looks; theme UI tightened.

### Added
- **Sunflower** clock-theme (gold ticks/hands, rustic-orange accents, deep-mahogany/burgundy face) + its
  **Sunny** animation palette (index 9): golden-yellow → rustic orange → mahogany → dark-burgundy core.
- **Bird of Paradise** clock-theme (fiery-orange ticks/hands, ivory second hand, cobalt-blue face) + its
  **Blue Paradise** animation palette (index 10): complementary cobalt blue vs fiery orange, ivory accent.

### Removed / Changed
- **Snowstorm** animation palette removed (too close to Thunderstorm) — index 9 reused for **Sunny**.
- **GreenNGold** animation palette removed and its **gold-shimmer overlay reverted** (`applyGoldShimmer`
  deleted from `renderAnimFrame`) — index 10 reused for **Blue Paradise**. **Go Pack** now animates in its own
  green/gold via "Clock colors" (animationPalette 7) instead of a dedicated palette.
- **Go Pack** recolored deeper: dark green `#0E2A16`/`#16401F`, dark gold `#C8960C`/`#D4A017`.
- Palette VALUES still 0–10, SETTINGS_VERSION unchanged (16); a saved `animationPalette` of 9/10 now maps to
  the new palettes.

### UI
- **Motion & nudges** drawer collapsed by default.
- **Theme chips** pack tighter (narrower min width, smaller gap/padding); their color dot uses
  marker→face→center so Go Pack + the new themes read as green/blue gradients, not flat gold.

### Note
Existing flower palettes (Ember/Coral/Lagoon/Dusk/Nocturne/Tropic/Prism) still lean pastel — not retuned this
pass. New-theme/palette hexes + the layout tightening are best judged on hardware / the operator's screen.

## [2.19.0] - 2026-07-12 (palette names decoupled from themes + custom named themes (P3, browser-stored))

Two things. (1) The animation palettes no longer share names with the theme chips — flower names belong to
the themes (true-to-life flower colors); the palettes get their own descriptive names. (2) You can now save
the clock's current settings as a named theme and recall it.

### Changed
- **Animation palettes 0–6 renamed** (colors unchanged), decoupling them from the flower theme names:
  Dahlia→**Ember**, Cherry Blossom→**Coral**, Water Lily→**Lagoon**, Iris→**Dusk**, Moonflower→**Nocturne**,
  Bird of Paradise→**Tropic**, Wildflower→**Prism**. (`palettes.json` + regenerated `anim_palettes.h` +
  dropdown labels.) With GreenNGold (10), no name now appears in both the palette dropdown and the theme
  chips. Palette VALUES unchanged — no wire/EEPROM change.

### Added
- **Custom named themes (P3, browser-stored).** A "＋ Save as theme…" button in Quick controls snapshots the
  clock's current settings (all-inclusive) under a name you choose; saved themes appear as chips beside the
  built-ins, each with a delete ✕, and clicking one applies the full snapshot. Stored in browser localStorage
  (the "both" plan — on-device NVS is the later half). Built-in "ChronoBloom" stays a first-class chip.

## [2.18.0] - 2026-07-12 (GreenNGold animation + gold sparkle shimmer + Go Pack clock-theme)

Reclassifies the Packers colors correctly: "Green Bay Packers" was an animation palette (wrong — it's a
whole-clock look). Now split into two distinct things: **Go Pack** (a full clock-theme) and **GreenNGold**
(its animation palette, with a live gold sparkle overlay).

### Added
- **Go Pack clock-theme** — a built-in theme chip: dark-green rings, gold hour ticks + hands, white second
  hand, gold breathing core. Sets the GreenNGold animation palette. Hardcoded like ChronoBloom, so it needs
  no custom-theme storage (that UI is still P3).
- **Gold sparkle shimmer** for GreenNGold: `applyGoldShimmer()` overlays sparse bright-/throwback-gold
  twinkles over whatever animation is playing while palette 10 is active — rides the existing twinkle engine
  (Galaxy Spin stars / Firefly nudge), max-blended so it only ADDS light, hooked once in `renderAnimFrame`
  after `tickAnimation`, gated out during reminder animations. **NOT yet observed on hardware** — the mock
  can't render firmware animations; the shimmer needs a flashed-device eyeball.

### Changed
- **Animation palette 10 renamed "Green Bay Packers" → "GreenNGold"** and recolored: dark forest-green rings
  (#183C1E / #22582E), deep throwback-gold throat (#8A6A16), shiny gold core (#FFC42A). Dropdown label +
  swatch updated. The `animationPalette` VALUE stays 10 — no wire/EEPROM change, no migration.

### Naming (in progress)
Flower names now belong to the themes (true-to-life flower colors); animation palettes move to their own
descriptive names (Go Pack theme → GreenNGold palette is the first). Renaming the remaining flower palettes
(0–6) to distinct descriptive names is proposed, not yet applied.

## [2.17.0] - 2026-07-12 (web UI consistency P2: "Preview on clock" — flash-safe transient settings overlay)

Adds a real hardware preview for the clock-face theme (and any settings tweak): see a change on the LEDs
before committing it. Reuses the existing non-persistent-override pattern, generalized from animation style
to the whole settings block. RAM only — no EEPROM writes, no settings migration (SETTINGS_VERSION stays 16).

### Added
- **▶ Preview in the save bar** (`previewOnClock()`): posts the current unsaved face settings to the new
  **`POST /settings/preview`** endpoint, which renders them on the clock for ~10 s then auto-reverts to the
  saved face. No flash write, so it is safe to repeat and safe during OTA.
- **`SettingsStore` preview overlay:** `setPreview()/clearPreview()/tickPreview()`; `get()` transparently
  returns the overlay while active so the renderer needs zero changes; `getPersisted()` gives the JSON API
  and `/diag` the saved state regardless of an in-flight preview. `loop()` expires the overlay and forces one
  re-render back to the saved face. `POST /settings/preview/clear` reverts on demand; a real Save/reset
  clears any active preview.

### Changed
- **DRY:** the ~50-line `/settings` POST arg parser is now a shared `applyPostedSettings()` helper called by
  both `/settings` and `/settings/preview`, so the two parsers cannot drift.

## [2.16.0] - 2026-07-12 (web UI consistency P1: theme naming + Quick-controls Preview/Save)

First pass of the web-UI ↔ firmware consistency work found during hardware testing of 2.15.0. Vocabulary
unified toward "theme"; every quick control now has a visible Preview and Save. Labels only — no JSON
key / POST arg / EEPROM changes, so existing backups, exported themes, and the demo-reel designer keep
working, and no settings migration (SETTINGS_VERSION stays 16).

### Fixed
- **Animation-theme preview now covers palettes 8/9/10.** `/previewAnimation` clamped the preview palette
  to 0–7, so Thunderstorm/Snowstorm/Green Bay Packers could never be previewed (silently fell back to 7).
  Widened to `0..ANIM_PALETTE_COUNT-1` (`src/main.cpp`).
- **The animation theme is no longer a silent no-op.** The Quick-controls animation dropdown had no way to
  be *seen* on the clock (a palette only colors trigger animations, invisible while the face is idle) — it
  now has a **▶ Preview** button that plays a sample animation on the clock in the selected theme.

### Added
- **Quick controls: ▶ Preview + Save.** Preview plays a sample hour animation in the selected animation
  theme as a non-persistent override (self-reverting, no flash write). Save persists the quick controls
  (animation theme, speed, animation brightness, trail, reminder theme, brightness mode + levels) in one
  request, with the on-device "settings saved" confirmation.

### Changed
- **"Palette" → "Theme" in the UI.** "Animation palette" → **Animation theme**, "Reminder palette" →
  **Reminder theme**. Internally these remain the `animationPalette` / `reminderPalette` fields — a theme is
  a bundle that *contains* a palette; users pick the theme, the palette stays an implementation detail.
- **"Chime" → "interval animation"** wording (the device has no speaker; "chime" implied sound). "Animation
  brightness (chimes & nudges)" → "(interval animations & nudges)". The distinct hourly visual-sweep
  accessory `hourlyChime` is relabeled **"Hourly bloom"** (kept as its own feature; id/wire key unchanged).
- **No auto-save on theme change.** Selecting an animation theme / speed no longer writes to the clock on
  change; it updates the UI, and you Preview and/or Save explicitly. Matches the preview-then-commit model
  and removes the old asymmetry (animation palette auto-saved, reminder palette did not).

## [2.15.0] - 2026-07-12 (dashboard web UI redesign + 3 new animation palettes)

Full `web_html.h` redesign to the "dashboard" layout the operator chose (sticky preview + visual quick
row + four category drawers), plus three new animation palettes. Verified in the mock-endpoint browser
harness (every control id present once, live-preview firing, no console errors); both variants build clean.

### Added
- **3 new animation palettes** (`tools/palettes/palettes.json` → `anim_palettes.h`): **8 = Thunderstorm**
  (storm slate + electric-blue + lightning core), **9 = Snowstorm** (cold blue → white), **10 = Green Bay
  Packers** (team green rings + gold accent). `ANIM_PALETTE_COUNT` 7→11; index 7 stays the "Clock colors"
  firmware sentinel via a placeholder entry, so **deployed clocks storing 7 are unaffected — no migration,
  no palette flip.** Input clamps widened (`animationPalette` accepts 0–10).
- **Mode-adaptive Brightness** in the quick row: single `dayBrightness` slider in Manual/Scheduled (and
  when no sensor is detected, auto-detected via `/lux`), or a min↔max dim-range (`minAutoBrightness`/
  `maxAutoBrightness`) in Auto (sensor) mode. Separate **"Animation brightness (chimes & nudges)"** slider
  (`animationBrightness`) in the Motion drawer.
- **Theme swatch chips** (replaces the theme dropdown) and a **persistent Save / Set-default / Reset bar**
  in the preview card (no longer buried in a collapsed card).

### Changed
- **Dashboard layout.** Sticky preview (clock +25%, network line, save bar) beside a control column of a
  visual **Quick controls** card (theme · palette · speed · brightness) and four collapsible category
  drawers: **Motion & nudges** (default-open, accented) · **Colors & rings** (default-collapsed, set-once)
  · **Time & light** · **System**. Emphasis shifted to animations/nudges; the static color/ring tuning
  tucks away.
- Palette picker gains the 3 new palettes; Time & light labels made more descriptive.

### Performance
- Confirmed the richer brightness UI adds **no** load to the lux poll or WS2812 render path: it only sets
  bytes consumed by `effectiveBrightness()`'s `constrain()`. Lux is polled in `loop()` (never an ISR),
  throttled ≥120 ms with a ~1–3 ms non-blocking NOWAIT read.

## [2.14.2] - 2026-07-12 (web UI: back to one scannable page — tabs removed, Ring colors collapsible)

Reverts the tabbed layout (2.14.0/2.14.1) back toward the original single scannable panel after
feedback that too many tabs/cards made it hard to grasp. Web-UI-only; verified in a browser.

### Changed
- **Tabs removed.** The 5-tab bar and tab panels are gone; every card is visible again in one
  scannable column beside the sticky preview (the layout kind that was liked originally), just
  without the one thing that made it too long.
- **Ring colors is now collapsible** (native `<details>`, default collapsed) — the 9-row block that
  was the only real space hog tucks away, so the page reads short and scannable but the manual
  per-ring tuning is one click away. No animation, no per-card accordion (that was the disliked
  2.13.3 approach); just this one oversized block.
- **Removed the "ADHD" references** from the UI: the Focus Reminders card is now titled "Focus
  Reminders" with softer copy ("A gentle nudge to look up and shift focus…"), and the Demo Mode
  card says "focus nudges" instead of "ADHD nudges".

### Notes
- Pure markup/CSS/JS-init reorg — no control ids added, removed, or duplicated; the `showTab`/
  `initTabs` tab JS was removed and every existing binding (loadSettings/bindLive/saveSettings/draw/
  applyTheme) is untouched. Card order preserved: Presets, Ring colors, Ring setup, Effects, Color
  Theme, Animation Style, Time Animations, Focus Reminders, Time, Display, Auto-Brightness, Network,
  Admin, Full backup, Demo.
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

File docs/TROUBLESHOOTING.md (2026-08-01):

# ChronoBloom ESP32-C3 -- Troubleshooting Guide

## Common Issues & Solutions

---

## Brightness Issues

### Display goes completely dark after saving settings

**Symptoms**:
- All LEDs off after a settings save
- Web UI still responds but nothing is visible
- Reloading the page shows brightness value of 0

**Cause**: `dayBrightness=0` (or `nightBrightness=0`) was submitted. In `autoBrightnessMode=0` (manual), `dayBrightness` is passed directly to the LED strip -- zero means off. Pre-v2.1.1 firmware had no floor on this field.

**Fix (v2.1.1+)**: `sanitize()` now floors `dayBrightness < 5` to 44 and `nightBrightness < 1` to 5. Upgrade firmware and re-save any settings to recover.

**Recovery on older firmware**: Use `/diag` to confirm the device is alive, then POST a non-zero brightness:
```
curl -X POST "http://esp32c3-v3-8inch.local/settings" -d "dayBrightness=150"
```
Or hold both buttons on boot for 3 seconds to factory reset EEPROM to defaults.

---

## WebUI / HTTP Issues

### 15inch variant reboots when loading the root page

**Symptoms**:
- Animations become laggy immediately before crash
- Device reboots with `boot_reason: watchdog` or `boot_reason: panic` in `/diag`
- 8inch variant is unaffected

**Root cause**: `htmlPage()` allocated a ~6KB `String` on the heap at request time.
On the 15inch variant (two NeoPixel strips, larger pixel buffer), heap headroom was too
tight to absorb the double-allocation during `server_.send()`.

**Fix**: Resolved in v2.1.0. All large HTML responses now use PROGMEM chunks streamed
via `sendContent_P()`. JSON handlers use `snprintf` into stack buffers. No heap
allocation occurs at page-load time. Confirmed free heap after fix: **236KB**.

**If still crashing after flashing v2.1.0**: Check `/diag` for `free_heap`. If below
~80KB, another allocation source is the culprit -- check for long-running String builds
elsewhere in the loop.

---

## WiFi Connection Problems

### Clock won't connect to WiFi

**Symptoms**:
- Red spinning dot on inner ring (STATUS_WIFI_FAIL animation)
- Serial output shows "Wi-Fi connect failed. Status: X"
- Web UI not accessible

**Diagnostic steps**:
1. Check serial monitor output (`pio device monitor`)
2. Verify WiFi credentials in `platformio.ini`:
   ```ini
   -D WIFI_SSID=\"YourSSID\"
   -D WIFI_PASSWORD=\"YourPassword\"
   ```
3. Check router DHCP table for device (hostname: `esp32c3-v3-8inch`)
4. Verify SSID is 2.4GHz (ESP32-C3 does NOT support 5GHz)

**Common fixes**:
- Special characters in password need escaping: `\"` for quotes, `\\` for backslash
- SSID/password case-sensitive
- Router may be blocking new devices (check MAC filter)
- WiFi signal too weak (try closer to router during first boot)

**Workaround**: Add temporary debug output
```cpp
WiFi.begin(WIFI_SSID, WIFI_PASSWORD);
Serial.print("Connecting to: ");
Serial.println(WIFI_SSID);
Serial.print("Password length: ");
Serial.println(strlen(WIFI_PASSWORD));
```

---

### mDNS hostname not resolving

**Symptoms**:
- `http://esp32c3-v3-8inch.local/` times out
- Direct IP access works

**Fixes**:
1. **Windows**: Install Bonjour Print Services (Apple) for mDNS support
2. **Linux**: Ensure `avahi-daemon` is running
3. **macOS**: Should work natively
4. **Alternative**: Use direct IP address from serial output or router DHCP table

**Check mDNS status**:
```cpp
// In setup(), after MDNS.begin()
Serial.print("mDNS started: ");
Serial.println(mdnsEnabled_ ? "YES" : "NO");
```

---

## Button Issues

### Spurious button presses / time jumping backward

> **Resolved v2.0.6**: Buttons moved to GPIO5(UP)/GPIO9(DOWN) with polled reads. Original root cause documented below for reference.

**Symptoms (historical -- ISR-based buttons on GPIO3/GPIO4)**:
- Time jumps backward by 5 minutes without physical button press
- Most common when USB cable connected
- Less common when powered via 5V-only supply

**Root cause**: GPIO3/GPIO4 are JTAG TCK/TDI pins on ESP32-C3. USB data connection can trigger JTAG subsystem, causing FALLING edge interrupts.

**Diagnostic test**:
1. Power clock via 5V-only supply (no USB data pins connected)
2. Observe if spurious presses stop
3. If yes, confirms JTAG interference

**Fixes** (in priority order):

**Option 1: Revert to polled buttons** (recommended)
```cpp
// Replace ISR-based ButtonInput with polled version
void poll(uint32_t now) {
  bool upNow = (digitalRead(BUTTON_UP_PIN) == LOW);
  bool downNow = (digitalRead(BUTTON_DOWN_PIN) == LOW);
  
  if (upNow && !lastUp_ && now - lastUpMs_ > debounceMs_) {
    upPressed_ = true;
    lastUpMs_ = now;
  }
  if (downNow && !lastDown_ && now - lastDownMs_ > debounceMs_) {
    downPressed_ = true;
    lastDownMs_ = now;
  }
  
  lastUp_ = upNow;
  lastDown_ = downNow;
}

// Call in loop():
buttons.poll(millis());
```

**Option 2: Move buttons to safe pins** (requires rewiring)
- Use GPIO6, GPIO7, GPIO8, or GPIO9
- Note: GPIO6/7 currently used for I2C (VEML7700)
- Viable if sensor not installed

**Option 3: Add stable-LOW guard** (software-only, partial fix)
```cpp
// In main loop, when consuming button flag:
if (buttonUpPressed_) {
  if (digitalRead(BUTTON_UP_PIN) == LOW) {  // Verify still pressed
    timeModel.addMinutes(1);
  }
  buttonUpPressed_ = false;
}
```

---

### Buttons not responding at all

**Symptoms**:
- Physical button press does nothing
- No animation, no time change

**Checks**:
1. Verify pull-up resistors: buttons should connect pin to GND when pressed
2. Check `INPUT_PULLUP` mode set in `pinMode()`
3. Test with multimeter: pin should read 3.3V when not pressed, 0V when pressed
4. Verify button wiring: Common = GND, NO (normally open) = GPIO pin

**Debug code**:
```cpp
// In loop():
Serial.print("UP: ");
Serial.print(digitalRead(GPIO3));
Serial.print(" DOWN: ");
Serial.println(digitalRead(GPIO4));
delay(500);
```
Should print `1 1` when not pressed, `0 1` or `1 0` when single button pressed.

---

## LED Display Problems

### All LEDs off / no display

**Checks**:
1. **Power supply**: Verify 5V present at LED strip VCC/GND
2. **Data connection**: Check 300 ohm resistor inline with GPIO10 -> LED DIN
3. **Strip polarity**: Ensure VCC/GND not swapped (can damage LEDs)
4. **Index 0**: On both variants, physical index 0 is the first active ring LED (`RING_PIXEL_OFFSET=0`). If upgrading the 15" from a pre-v2.0.2 build, rewire GPIO10 data line directly to DIN of first ring LED.
5. **First LED misbehaving specifically** (flickers, wrong colour, or sparkle that clusters at the start of the chain while the rest is fine): that pattern points at logic levels, not a dead LED. The C3 drives data at 3.3 V and WS2812Bs want about 3.5 V off a 5 V supply, so the first LED is reading a marginal signal. Watch for the counter-intuitive version: a *better*, truer 5 V supply can break a chain that worked on a sagging one, because the threshold scales with supply voltage. Keep the run from the board to the first LED short, keep a ground alongside the data wire, and if it persists fit a 74AHCT125 buffer **at the board end** - a level shifter only helps if the weak signal reaches it before travelling any distance. `src/main.cpp` carries the full explanation above the LED geometry constants.

**Serial output check**:
```
ChronoBloom v3 booting...
Build target: esp32c3-v3-8inch
LED count: 97
Ring pixel offset: 0
Center pixel: enabled at physical index 96
```

**Test code**:
```cpp
// In setup(), after strip_.begin():
strip_.fill(strip_.Color(255, 0, 0), 0, CLOCK_PIXEL_COUNT);  // All red
strip_.show();
delay(2000);
```

---

### Center pixel not lighting (15" variant)

**Symptoms**:
- All rings work
- Center pixel remains dark

**Checks**:
1. Verify `CENTER_PIXEL_SEPARATE_OUTPUT=1` in build flags
2. Check `CENTER_PIXEL_PIN=20` wired correctly
3. Confirm GPIO20 not shorted to GND
4. Test center strip separately:
```cpp
centerStrip_->setPixelColor(0, centerStrip_->Color(255, 255, 255));
centerStrip_->show();
```

---

### Wrong colors / colors shifted

**Symptoms**:
- Red appears green, green appears blue, etc.

**Cause**: NeoPixel color order mismatch

**Fix**: Change `NEO_GRB` to `NEO_RGB` (or vice versa) in NeoPixel initialization:
```cpp
Adafruit_NeoPixel ledStrip(CLOCK_PIXEL_COUNT, LED_DATA_PIN, NEO_RGB + NEO_KHZ800);
```

Common orders: `NEO_GRB`, `NEO_RGB`, `NEO_GRBW` (if RGBW strip)

---

### Flickering during web requests

**Symptoms**:
- LEDs flicker or dim briefly when accessing web UI
- Most noticeable during long HTTP responses

**Cause**: WiFi interrupt preemption delays `strip_.show()` timing

**Mitigations**:
1. Reduce web UI polling frequency (increase `setInterval` from 1000ms to 2000ms)
2. Use longer delays between animation frames
3. Disable WiFi during critical animations:
```cpp
WiFi.mode(WIFI_OFF);
renderAnimation();
WiFi.mode(WIFI_STA);
```

---

## Sensor Issues

### VEML7700 not detected

**Symptoms**:
- Serial output: "VEML7700 not found on I2C"
- `/lux` endpoint returns `{"available":false}`

**Diagnostic I2C scan**:
```cpp
Wire.begin(6, 7);
Serial.println("Scanning I2C bus...");
for (uint8_t addr = 1; addr < 127; addr++) {
  Wire.beginTransmission(addr);
  if (Wire.endTransmission() == 0) {
    Serial.print("Found device at 0x");
    Serial.println(addr, HEX);
  }
}
```
Expected output: `Found device at 0x10`

**Common fixes**:
- Check SDA/SCL not swapped (green=SDA/GPIO6, yellow=SCL/GPIO7)
- Verify 3.3V and GND connected
- Try different I2C address if using non-standard VEML7700 breakout
- Check solder joints on sensor breakout board

---

### Auto-brightness not working

**Symptoms**:
- Lux reading shown in web UI
- Brightness doesn't change with room lighting

**Checks**:
1. Verify `autoBrightnessMode = 1` (auto) in web UI, not 0 (manual) or 2 (scheduled)
2. Check min/max brightness limits (if both set to same value, no change visible)
3. Confirm lux reading actually changing (cover sensor, shine flashlight)

**Debug output**:
```cpp
Serial.print("Lux: ");
Serial.print(luxSensor.lux());
Serial.print(" -> Brightness: ");
Serial.println(luxSensor.autoBrightness());
```

**Calibration**: If brightness changes too slowly/quickly, adjust logarithmic curve in `LuxSensor::autoBrightness()`.

---

## Settings & EEPROM

### Settings not persisting after reboot

**Symptoms**:
- Change settings in web UI, reboot, settings reset to defaults

**Checks**:
1. Verify "Save display" button clicked (not just changing values)
2. Check serial output for "Settings saved" confirmation
3. Verify `EEPROM.commit()` called after `EEPROM.put()`

**Force EEPROM reset** (if corrupted):
```cpp
// In setup(), before settingsStore.begin():
EEPROM.begin(256);
for (int i = 0; i < 256; i++) {
  EEPROM.write(i, 0x00);
}
EEPROM.commit();
Serial.println("EEPROM cleared");
```

---

### Settings reset unexpectedly

**Cause**: Settings version mismatch (firmware update changed `ClockSettings` struct)

**Expected behavior**: When `SETTINGS_VERSION` increments, all settings reset to defaults. This is by design to ensure clean state.

**Check version**:
```cpp
Serial.print("Stored settings version: ");
Serial.println(storedSettings.version);
Serial.print("Current firmware version: ");
Serial.println(SETTINGS_VERSION);
```

---

## Web UI Issues

### Web UI loads but controls don't work

**Symptoms**:
- Can access web page
- Buttons/sliders do nothing
- No errors in browser console

**Checks**:
1. Hard refresh browser (Ctrl+Shift+R) to clear cached JavaScript
2. Check browser console for JavaScript errors (F12 -> Console tab)
3. Verify `/settings` POST endpoint responding (Network tab in F12)

**Test endpoint directly**:
```
POST http://192.168.1.XXX/settings
Content-Type: application/x-www-form-urlencoded

dayBrightness=200&nightBrightness=20
```

---

### Live clock preview not updating

**Symptoms**:
- SVG clock visible but frozen
- Time doesn't advance

**Checks**:
1. Verify `/time` endpoint responding (check Network tab, should poll every 1 sec)
2. Check JavaScript console for fetch errors
3. Confirm `setInterval(refresh, 1000)` running

**Test `/time` endpoint**:
```
GET http://192.168.1.XXX/time
```
Should return JSON: `{"hour":14,"minute":30,"second":45,...}`

---

## Build & Flash Issues

### Upload fails: "Port not found"

**Symptoms**:
- `pio run -t upload` fails
- Error: "Please specify `upload_port`"

**Fixes**:
1. Check USB cable (data-capable, not charge-only)
2. Verify XIAO board drivers installed (CH340 or CP210x)
3. Manually specify port:
```powershell
pio run -e esp32c3_v3_8inch -t upload --upload-port COM3
```
4. Windows: Check Device Manager -> Ports (COM & LPT)
5. Linux: Check `ls /dev/ttyUSB*` or `ls /dev/ttyACM*`

---

### Compilation errors after updating

**Common errors**:

**"LuxSensor was not declared"**:
- Missing `#include` or class definition
- Check `LUX_SENSOR_ENABLED=1` in build flags

**"Adafruit_VEML7700.h: No such file"**:
- Library not installed
- Add to `platformio.ini` lib_deps:
```ini
adafruit/Adafruit VEML7700 Library @ ^2.1.6
```
- Run `pio lib install`

**"Multiple definition of..."**:
- Function/variable defined in header without `inline` or `static`
- Move implementation to `.cpp` or add `inline` keyword

---

## Animation Issues

### Animations not triggering at expected times

**Symptoms**:
- Top of hour passes, no animation
- Quarter-hour passes, nothing happens

**Checks**:
1. Verify `intervalAnimationsEnabled = 1` in web UI
2. Confirm specific animation not set to "Off" (mode 0)
3. Check time is actually advancing (NTP sync working)

**Debug trigger logic**:
```cpp
if (time.minute != lastMinute && time.second == 0) {
  Serial.print("Minute changed: ");
  Serial.print(time.minute);
  Serial.print(" Animation enabled: ");
  Serial.println(settingsStore.get().intervalAnimationsEnabled);
}
```

---

### Animation runs but clock display wrong after

**Symptoms**:
- Animation plays correctly
- Afterward, clock shows wrong time or frozen

**Cause**: Animation didn't call `timeModel.markDirty()` at end

**Fix**: Add to end of animation function:
```cpp
void renderMyAnimation(uint32_t now) {
  // ... animation code ...
  
  timeModel.markDirty();  // Force full redraw
}
```

---

## Demo Mode

### Demo Mode won't start

**Symptoms**:
- Click "Start" button in web UI, nothing happens
- Status shows "Idle" and doesn't advance

**Checks**:
1. Verify device is connected and web UI loading normally
2. Check browser console (F12) for JavaScript errors on `startDemo()` call
3. Confirm `/demo/start` endpoint is reachable: `curl -X POST http://esp32c3-v3-8inch.local/demo/start`
4. Check `/demo/status` response (should return `{"active":true,...}` after starting)

**Test response**:
```
GET http://esp32c3-v3-8inch.local/demo/status
```
Should return JSON with `"active": true` and current `"step"` number.

---

### Demo Mode stops abruptly

**Symptoms**:
- Demo starts (status updates)
- Stops mid-sequence
- Clock returns to normal display

**Checks**:
1. Verify WiFi still connected (demo stops if OTA or other network event interrupts)
2. Check serial output for watchdog resets or exceptions
3. Confirm device free heap > 80KB (large allocations during demo can cause issues)
4. Verify step duration timings not being overridden by user interaction

**Debug output**:
```cpp
// In DemoMode::loop():
Serial.print("Demo step: ");
Serial.print(currentStep_);
Serial.print(" Elapsed: ");
Serial.println(elapsedMs_);
```

---

### /demo/overlay not displaying correctly in OBS

**Symptoms**:
- OBS browser source shows blank or wrong content
- Text not fading in/out smoothly
- Subtitles lag behind demo sequence

**Checks**:
1. Verify OBS browser source URL: `http://esp32c3-v3-8inch.local/demo/overlay`
2. Confirm OBS browser source dimensions: 1920x1080 (as per spec)
3. Check OBS browser source cache disabled (may cause stale HTML load)
4. Verify `/demo/status` polling responding (overlay polls every 500ms)
5. Confirm browser zoom set to 100% in OBS properties

**Test `/demo/overlay` in browser**:
- Open directly: `http://esp32c3-v3-8inch.local/demo/overlay`
- Should display full-screen white text on black pill background
- Text should fade in/out as demo progresses

---

### Lux override not working during demo

**Symptoms**:
- Auto-brightness demo step (step 3) runs but brightness doesn't change
- Lux reading in web UI shows real sensor value, not override

**Cause**: `LuxSensor::setLuxOverride()` called during demo should temporarily bypass hardware read.

**Checks**:
1. Verify auto-brightness mode enabled in web UI (`autoBrightnessMode = 1`)
2. Confirm lux limits allow room to change (min/max brightness differ)
3. Check `/lux` endpoint during demo: should return override value, not hardware value

**Debug output**:
```cpp
// In LuxSensor::lux():
if (luxOverrideActive_) {
  Serial.print("Override active: ");
  Serial.println(luxOverrideValue_);
}
```

---

### Buttons not responsive during demo

**Expected behavior**: Physical buttons are ignored during demo playback.

**If buttons still control time**:
1. Verify demo is actually running (`/demo/status` shows `"active": true`)
2. Check `ButtonInput::poll()` respects demo state -- should consume button events without acting on them
3. Confirm buttons weren't pressed before demo started (state machine may have pending press)

---

## Performance Issues

### Sluggish web UI / slow response

**Symptoms**:
- Web page takes seconds to load
- Button clicks delayed

**Causes**:
- WiFi signal weak (clock too far from router)
- Too many concurrent connections
- ESP32 busy with animation rendering

**Mitigations**:
1. Move clock closer to router
2. Reduce SVG preview refresh rate (2000ms instead of 1000ms)
3. Disable animations during web UI usage
4. Increase web server timeout in code

---

### Clock loses time / drifts

**Symptoms**:
- Clock slow by minutes/hours
- No NTP sync happening

**Checks**:
1. Verify NTP sync enabled: `ENABLE_NTP=1` in build flags
2. Check WiFi connected (NTP requires network)
3. Monitor serial for "NTP sync" messages
4. Verify timezone string correct: `MST7MDT,M3.2.0,M11.1.0` for Mountain time

**Force NTP sync** via web UI or POST:
```
POST http://192.168.1.XXX/syncNtp
```

---

## Hardware Damage Prevention

### Precautions
1. **NEVER power LEDs from 3.3V** -- Will damage ESP32 voltage regulator
2. **Check polarity before connecting** -- Reversed VCC/GND can destroy LED strip
3. **Use 300 ohm resistor on data line** -- Prevents voltage spikes from damaging first LED
4. **Limit initial brightness** -- Test with low brightness before full power
5. **Proper power supply sizing** -- 5V 2A is enough: firmware caps total LED draw at 1800mA (`MAX_LED_MILLIAMPS`) by dimming any frame that would exceed it

### If LEDs won't light after assembly
1. Check LED strip not damaged during fabrication (measure resistance VCC-GND, should be >1k ohm)
2. Verify data direction (DIN -> DOUT, chain must be correct direction)
3. Test with single LED first (disconnect strip, connect one LED directly)

---

## Getting Help

### Before asking for help, collect:
1. Serial monitor output (full boot sequence)
2. Web UI screenshot showing current settings
3. Build target (`esp32c3_v3_8inch` or `esp32c3_v3_15inch`)
4. Firmware version (check serial: "SETTINGS_VERSION")
5. Symptoms and steps to reproduce

### Useful diagnostic commands
```powershell
# Full serial output
pio device monitor -e esp32c3_v3_8inch

# Clean build (remove cached files)
pio run -e esp32c3_v3_8inch -t clean
pio run -e esp32c3_v3_8inch

# List connected devices
pio device list
```

---

## WiFi AP Fallback
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

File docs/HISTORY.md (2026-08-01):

# ChronoBloom ESP32-C3 -- Project History

## From Steve Manley's 2015 design to a decade of builds

---

## Steve Manley (2015-2016) -- where it started

### The original 3-ring NeoPixel clock

**Hardware**
- **Microcontroller**: Arduino Nano
- **Timekeeping**: DS3234 SPI RTC module with CR2032 backup battery
- **Display**: NeoPixel rings (60/24/12 LEDs)
- **Input**: Two push buttons (polled, no interrupts)
- **Enclosure**: 3D-printed base and face plates, wooden cabinet frame (lathe-turned)
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

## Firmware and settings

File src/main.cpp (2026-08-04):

#include <Arduino.h>
#include <EEPROM.h>
#if !defined(ESP32)
#error "ChronoBloom v3 requires an ESP32-family Arduino core."
#endif
#include <ESPmDNS.h>
#include <WiFi.h>
#include <WebServer.h>
#include <Update.h>
#include <Adafruit_NeoPixel.h>
#include <time.h>
#include <esp_sntp.h>
#include <WiFiManager.h>
#include <ArduinoOTA.h>
#include "esp_task_wdt.h"
#include "esp_ota_ops.h"
#include <Preferences.h>
#include <improv.h>  // improv-wifi/sdk-cpp — official protocol parser (PlatformIO improv/Improv @ 1.2.6)
#include "web_html.h"
#include "anim_palettes.h"  // shared mood palette LUTs — generated by tools/gen_palettes.py
#if LUX_SENSOR_ENABLED
#include <Adafruit_VEML7700.h>
#endif

using ClockWebServer = WebServer;

// ===================== Build-time configuration =====================
#ifndef LED_DATA_PIN
#define LED_DATA_PIN 10
#endif

#ifndef STATUS_LED_PIN
#define STATUS_LED_PIN -1
#endif

#ifndef CLOCK_PIXEL_COUNT
#define CLOCK_PIXEL_COUNT 98
#endif

#ifndef CENTER_PIXEL_ENABLED
#define CENTER_PIXEL_ENABLED 1
#endif

#ifndef CENTER_PIXEL_INDEX
#define CENTER_PIXEL_INDEX 1
#endif

#ifndef CENTER_PIXEL_SEPARATE_OUTPUT
#define CENTER_PIXEL_SEPARATE_OUTPUT 0
#endif

#ifndef CENTER_PIXEL_PIN
#define CENTER_PIXEL_PIN -1
#endif

#ifndef CENTER_PIXEL_STRIP_COUNT
#define CENTER_PIXEL_STRIP_COUNT 1
#endif

#ifndef RING_PIXEL_OFFSET
#define RING_PIXEL_OFFSET 2
#endif

#ifndef DEFAULT_OUTER_RING_OFFSET
#define DEFAULT_OUTER_RING_OFFSET 0
#endif

// ---------------------------------------------------------------------------
// FYI, for anyone wiring addressable LEDs to a 3.3 V board
//
// This clock does NOT use a "sacrificial" first LED, and this firmware has no
// support for one. The original 8" prototype had one for a while; it came out
// on 2026-08-01 and the code went with it. The idea is worth knowing anyway,
// because it explains a whole class of "my strip flickers / shows the wrong
// colours / only the first few light up" problems.
//
// WS2812B-family LEDs run off 5 V and want roughly 3.5 V before they will read
// a bit as a "1". An ESP32-C3 drives its data pin at 3.3 V. That is under the
// threshold, so the very first LED in the chain is being asked to read a signal
// that is marginal by design. Sometimes it works, sometimes it works until the
// room warms up or the wire gets longer.
//
// The trick: every LED in a chain does not pass the signal along, it re-reads
// it and re-transmits a fresh copy at its own 5 V supply level. So the first LED
// cleans up the weak 3.3 V signal for free. Wire one extra LED ahead of the
// rings, never light it, and every LED after it receives a proper 5 V signal.
// You have "sacrificed" one LED to act as a level shifter (level shifter =
// something that converts a low-voltage signal to a higher voltage one).
//
// What it looks like when the levels are NOT sorted out. The tell is that the
// damage clusters at the START of the chain, because the first LED is the only
// one reading the weak signal - everything past it reads a clean 5 V copy:
//   * the first LED, or first few, flicker or show a wrong colour while the
//     rest of the strip is perfect
//   * random sparkle or single wrong pixels that move around frame to frame
//   * the whole strip freezes on one bad frame until the next refresh
//   * it works on the bench and fails once the data wire gets longer
//   * it works cold and starts glitching once the room or the LEDs warm up
//   * it works one boot and not the next, with nothing changed
//
// The counter-intuitive one, worth knowing because it sends people down the
// wrong path: a BETTER power supply can break a strip that used to work. The
// threshold for a "1" is a fraction of the supply voltage, so feeding the LEDs a
// true 5.0 V raises the bar the 3.3 V signal has to clear, while a sagging 4.5 V
// supply lowers it. If a strip worked on a weak supply and started glitching on
// a good one, this is why, and the answer is a level shifter, not a worse PSU.
//
// Placement is the whole trick, and it is what makes this a distance fix too.
// Put the sacrificial LED right at the board, beside the 5 V rail. The weak
// 3.3 V signal then only has to survive a couple of centimetres before it is
// re-transmitted as a clean, full-swing 5 V one, and it is that strong signal
// that makes the long run out to the rings. You have not boosted the far end;
// you have shrunk the fragile part to almost nothing and made everything after
// it robust. Same reasoning as a proper buffer chip: it belongs at the board
// end, not out at the strip.
//
// Put it at the far end instead and you get nothing, because the marginal
// signal has already made the whole journey by the time it arrives.
//
// Worth doing either way: run the data wire with a ground alongside it, and fit
// a resistor of roughly 330-470 ohms in the data line at the board end to soften
// the signal edge and stop it reflecting back down the wire.
//
// The purpose-built version of the same idea: a 74AHCT125 buffer chip. It is a
// real level shifter, costs well under a pound, sits in the same place for the
// same reason, and does not cost you an LED. That is what to reach for if a long
// run misbehaves.
// ---------------------------------------------------------------------------

#ifndef ENABLE_WIFI_UI
#define ENABLE_WIFI_UI 1
#endif

#ifndef ENABLE_NTP
#define ENABLE_NTP 1
#endif

#ifndef TEMP_SENSOR_ENABLED
#define TEMP_SENSOR_ENABLED 0
#endif

#ifndef WIFI_SSID
#define WIFI_SSID "clock-ssid"
#endif

#ifndef WIFI_PASSWORD
#define WIFI_PASSWORD "clock-password"
#endif

#ifndef DEVICE_HOSTNAME
#define DEVICE_HOSTNAME "esp32c3-ringclock"
#endif

#ifndef DEVICE_TITLE
#define DEVICE_TITLE "ChronoBloom v3"
#endif

#ifndef WIFI_CONNECT_TIMEOUT_MS
#define WIFI_CONNECT_TIMEOUT_MS 20000
#endif

#ifndef NTP_TIMEZONE_TZ
// Mountain time with US daylight saving rules.
#define NTP_TIMEZONE_TZ "MST7MDT,M3.2.0,M11.1.0"
#endif

#ifndef BUTTON_UP_PIN
#define BUTTON_UP_PIN 5
#endif

#ifndef BUTTON_DOWN_PIN
#define BUTTON_DOWN_PIN 9
#endif

// Shared logical ring order. RING_PIXEL_OFFSET selects where logical outer LED 0
// lands in the physical chain for each clock variant.
struct RingConfig {
  uint8_t count;
  uint16_t offset;
  bool clockwise;
};

constexpr RingConfig RING_OUTER_60 = {60, RING_PIXEL_OFFSET, true};
constexpr RingConfig RING_MIDDLE_24 = {24, RING_PIXEL_OFFSET + 60, true};
constexpr RingConfig RING_INNER_12 = {12, RING_PIXEL_OFFSET + 84, true};

#if CENTER_PIXEL_ENABLED && CENTER_PIXEL_SEPARATE_OUTPUT && (CENTER_PIXEL_PIN < 0)
#error "CENTER_PIXEL_PIN must be set when CENTER_PIXEL_SEPARATE_OUTPUT is enabled."
#endif

#if CENTER_PIXEL_ENABLED && CENTER_PIXEL_SEPARATE_OUTPUT && (CENTER_PIXEL_INDEX >= CENTER_PIXEL_STRIP_COUNT)
#error "CENTER_PIXEL_INDEX must be inside CENTER_PIXEL_STRIP_COUNT when CENTER_PIXEL_SEPARATE_OUTPUT is enabled."
#endif

#if CENTER_PIXEL_ENABLED && !CENTER_PIXEL_SEPARATE_OUTPUT && (CENTER_PIXEL_INDEX >= CLOCK_PIXEL_COUNT)
#error "CENTER_PIXEL_INDEX must be inside CLOCK_PIXEL_COUNT when CENTER_PIXEL_ENABLED is set."
#endif

#if (RING_PIXEL_OFFSET + 96) > CLOCK_PIXEL_COUNT
#error "RING_PIXEL_OFFSET leaves too few pixels for the 60+24+12 ring chain."
#endif

#if (DEFAULT_OUTER_RING_OFFSET < 0) || (DEFAULT_OUTER_RING_OFFSET >= 60)
#error "DEFAULT_OUTER_RING_OFFSET must be in the 0-59 LED range."
#endif

#if CENTER_PIXEL_ENABLED && !CENTER_PIXEL_SEPARATE_OUTPUT && (CENTER_PIXEL_INDEX >= RING_PIXEL_OFFSET) && (CENTER_PIXEL_INDEX < (RING_PIXEL_OFFSET + 96))
#error "CENTER_PIXEL_INDEX overlaps the ring pixel range."
#endif

static void configureWiFiHostname() {
  WiFi.config(INADDR_NONE, INADDR_NONE, INADDR_NONE);
  if (!WiFi.setHostname(DEVICE_HOSTNAME)) {
    Serial.println("Wi-Fi hostname set failed");
  }
}

static void writeStatusLed(bool on) {
#if STATUS_LED_PIN >= 0
  digitalWrite(STATUS_LED_PIN, on ? HIGH : LOW);
#else
  (void)on;
#endif
}

// ===================== LED current budget (H1) =====================
// The XIAO ESP32-C3 is USB-powered (typical source 0.5–2 A). 96 WS2812B at full
// white would draw ~5.76 A — far past that — which sags the rail and browns the
// board out (observed 2026-07-08 on the 15" unit: froze mid-preview, went dark,
// stable only on a 4 A hub). Adafruit_NeoPixel has no current limiter, so we add
// one: before every show(), estimate the commanded current from the pixel buffer
// and, if it exceeds the per-variant budget, scale the strip's brightness down
// for that frame only. It is a ceiling — normal (dimmer) frames pass through
// untouched, and the next frame re-sets its own intended brightness.
#ifndef MAX_LED_MILLIAMPS
#define MAX_LED_MILLIAMPS 1800  // usable LED share of a 5 V / 2 A supply
#endif

// A fully-lit WS2812B color channel draws ~20 mA (white ≈ 60 mA = 3 × 20).
static constexpr uint16_t LED_MA_PER_CHANNEL_FULL = 20;

// WS2812B color pipeline — matches the WLED "Color & White" reference config
// (github.com/wled/WLED, verified against wled00/colors.cpp): gamma correction
// for color ON at gamma 2.2, applied identically to R, G, B; White Balance /
// per-channel scaling OFF. This REPLACES the former linear green×0.69 / blue×0.94
// white-balance scaling, which fought warm mid-tones (gold/amber skew).
//
// CRITICAL ordering (WLED: "gamma on color, brightness after"; its own code warns
// "applying gamma after brightness has too much color loss"): gamma is applied to
// the COLOR at ledGamma() — inside ringColor() and renderCenterIdle() — BEFORE the
// per-ring level/scale multiply. It is NOT applied to the finished output buffer.
// v2.22.0 did the latter and gamma-crushed pre-scaled face fills (middleFaceScale
// ~55) to near-black: gamma(0.22·c) = 0.22^2.2·gamma(c) ≈ 0.03·gamma(c). Applying
// gamma before the scale keeps fills at scale·gamma(c) — their intended level.
// Set LED_CORRECT_ENABLED 0 to bypass; tune LED_GAMMA to taste.
#ifndef LED_CORRECT_ENABLED
#define LED_CORRECT_ENABLED 1
#endif
#ifndef LED_GAMMA
#define LED_GAMMA 2.2f  // WLED "Use Gamma value" (WLED 16.x reference rig)
#endif

// 256-entry gamma LUT, built once (powf is not constexpr). Mirror of WLED's
// gammaT[]=pow(i/255,gamma)*255. NOTE: distinct from the animation-shaping gamma8()
// (v*v/255, ≈gamma-2.0) used inside FX math — this LUT is the color correction.
static uint8_t ledGammaLut[256];
static bool ledGammaLutReady = false;
static void ledGammaInit() {
  for (int i = 0; i < 256; ++i) {
    ledGammaLut[i] = static_cast<uint8_t>(powf(static_cast<float>(i) / 255.0f, LED_GAMMA) * 255.0f + 0.5f);
  }
  ledGammaLutReady = true;
}

// Gamma-correct one channel at full scale, BEFORE any brightness/level multiply.
// Lazy LUT init is safe: LEDs are driven only from loop() on the single-core C3
// (no ISR/second task), and re-init is idempotent.
static inline uint8_t ledGamma(uint8_t v) {
#if LED_CORRECT_ENABLED
  if (!ledGammaLutReady) ledGammaInit();
  return ledGammaLut[v];
#else
  return v;
#endif
}

// THE single color-correction chokepoint. Every raw sRGB *design* color in the
// firmware — face, hands, markers, animation palettes, status, chime, and the
// boot/portal/reset indicators — is packed through gammaColor() EXACTLY ONCE, so
// correction is uniform and reproducible across the whole display (precision).
// WHAT the correction is (gamma value, future white balance) lives entirely in
// ledGamma()/ledGammaInit() — change it there and every color follows (accuracy).
// INVARIANT: downstream compositing (blendMax/blendOver) and brightness ops
// (scale/dim/pulse) receive ALREADY-corrected colors and must NEVER be routed
// back through gammaColor() — that would double-correct. Packs 0x00RRGGBB exactly
// like Adafruit_NeoPixel::Color(r,g,b).
static inline uint32_t gammaColor(uint8_t r, uint8_t g, uint8_t b) {
  return (static_cast<uint32_t>(ledGamma(r)) << 16) |
         (static_cast<uint32_t>(ledGamma(g)) << 8)  |
          static_cast<uint32_t>(ledGamma(b));
}

// Intentionally a no-op: color correction happens once at the color stage
// (gammaColor()), before per-ring brightness — never on the finished buffer.
// Retained so existing show() call sites need no change.
static inline void ledCorrect(Adafruit_NeoPixel &strip) { (void)strip; }

// Q3 seam trial (2026-08-04). RAM-only, never persisted, reboot resets to 0.
// The deep-dim scaler keeps a lit pixel visible through its dominant channel
// (pure-ember seams); the operator is weighing that against letting such
// pixels go black (shadow seams). 0 = ember floor, 1 = black. Set with
// seamTrial=0/1 on POST /settings or /settings/preview, read back as
// seam_trial in /diag. Exists so the two candidate laws can be A/B'd on the
// wall; after the ruling, the loser AND this switch get deleted.
static uint8_t g_seamTrialBlack = 0;

// Hand-contrast trial (2026-08-04, same contract as the seam trial: RAM-only,
// never persisted, reboot resets, losers deleted after the ruling). The
// unification of hand colors exposed same-hue hands vanishing into their
// faces (chronobloom magenta-on-magenta; Ember Dahlia's minute hand 1.2x the
// LIFTED outer crests). Three candidate mechanisms, bit-maskable so the wall
// judges each in isolation via handTrial=0..7 on POST /settings[/preview],
// read back as hand_trial in /diag:
//   bit 1 - lift cap: petal lift stops at 128, faces never climb into the
//           hands' 255 ceiling (the Ember minute-hand erosion, measured L=215)
//   bit 2 - shadow halo: the LEDs flanking the minute hand (60-ring) and the
//           middle hour hand (24-ring) dim to 15%, a dark notch the hand sits
//           in - geometric contrast, immune to hue overlap and deep dim
//   bit 4 - whitened hands: hour/minute colors pulled 55% toward white, the
//           cream-second-hand trick applied to the time hands
static uint8_t g_handTrialMask = 0;
static inline uint8_t handWhiten1(uint8_t c) {
  return (uint8_t)(c + ((255u - c) * 140u) / 255u);
}

// Canonical palette-value sanitizer (v2.27.0). Both animationPalette and
// reminderPalette share ONE 5-option list: indices 0..MOOD_PALETTE_COUNT-1 are
// mood palettes (MOOD_PALETTE_RINGS), 7 is "Clock colors" (face-mapped, handled
// in the renderer). ANY other value — an EEPROM-stored removed flower index
// (0-10 old scheme), a stale client POST, a bad import — collapses to 7, the
// safe default. Used uniformly by sanitize(), POST /settings, and the preview
// path so there is exactly one definition of "valid palette".
static inline uint8_t sanitizePaletteValue(long v) {
  if (v >= 0 && v < MOOD_PALETTE_COUNT) return static_cast<uint8_t>(v);
  return 7;  // Clock colors (default)
}
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
void loop() {
  esp_task_wdt_reset();
  const uint32_t now = millis();
  buttons.poll(now);

  // Improv stays serviced only while the device is unprovisioned/disconnected (matching the
  // pre-window above and WiFiManager's own AP fallback) — once connected, USB-serial can no
  // longer silently reconfigure a running clock's Wi-Fi. Cheap to evaluate every iteration;
  // improvSerial.loop() itself is a no-op unless active.
  {
    const bool shouldBeActive = webUi.apMode() || WiFi.status() != WL_CONNECTED;
    if (shouldBeActive && !improvSerial.active()) improvSerial.begin();
    else if (!shouldBeActive && improvSerial.active()) improvSerial.deactivate();
    improvSerial.loop();
  }

  while (now - lastTickMs >= 1000) {
    timeModel.tickOneSecond();
    lastTickMs += 1000;
  }

  timeSync.loop();
  webUi.loop();
  // Expire the non-persistent "Preview on clock" overlay when its TTL is up and
  // force one re-render so the face snaps back to the saved settings.
  if (settingsStore.tickPreview(now)) timeModel.markDirty();
  demoMode.loop(now);
  // Drive the reel Live Run's latched reel mode + auto-dissolve (see tickReelMode).
  // Gated on !demoMode.active() since DemoMode drives the same masterFade_
  // channel itself while it's running; the two features are never used
  // together in practice (on-device Start Demo vs. the reel designer), but
  // this keeps them from fighting over masterFade_ if they ever overlap.
  if (!demoMode.active()) renderer.tickReelMode(now);
  logRuntimeStatus(now);

  // H2: once the firmware has run steadily (~10 s) and rendered at least one
  // frame, treat the boot as known-good and confirm the OTA image. No-op unless
  // a rollback-capable bootloader is in use (see markBootValid()).
  if (lastAnimationRenderMs != 0 && now >= 10000) markBootValid();

  // Check and fire focus reminders
  reminderScheduler.checkAndFire(now);

  // Trigger interval animations (quarter, half-hour, hourly)
  const ClockTime time = timeModel.get();
  const ClockSettings &settings = settingsStore.get();

  if (settings.intervalAnimationsEnabled && !renderer.animating()) {
    if (time.minute != lastMinute && time.second == 0) {
      lastMinute = time.minute;
      if (time.minute == 0) {
        renderer.triggerHourAnimation(now);
      } else if (time.minute == 30) {
        renderer.triggerHalfHourAnimation(now);
      } else if (time.minute % 15 == 0) {
        renderer.triggerQuarterAnimation(now);
      }
    }
  }

  {
    int upDelta = buttons.consumeUp();
    int downDelta = buttons.consumeDown();
    // The buttons set the time, and that is all they do. v2.31.0 briefly made a
    // press during a nudge mean "I saw it" instead; removed in v2.33.0, see the
    // note in FocusReminderScheduler for why. A nudge is not something you call
    // off, so a press near one is just someone setting the clock.
    if (upDelta != 0) { timeModel.addMinutes(upDelta); timeSync.noteManualSet(); renderer.setStatus(STATUS_BUTTON, 700); }
    if (downDelta != 0) { timeModel.addMinutes(downDelta); timeSync.noteManualSet(); renderer.setStatus(STATUS_BUTTON, 700); }
  }

  // Time-truth cue (v2.31.0): until NTP lands or the user sets the time by
  // hand, the face is showing a confidently wrong time. A short amber chase
  // every 10 s makes "plausible but unset" visibly different from "set".
  // Respects the status-blips toggle.
  {
    static uint32_t lastUnsetCueMs = 0;
    if (!timeSync.synced() && !timeSync.manuallySet() && settings.statusAnimations &&
        now - lastUnsetCueMs >= 10000UL) {
      lastUnsetCueMs = now;
      renderer.setStatus(STATUS_TIME_UNSET, 900);
    }
  }

  if (renderer.animating()) {
    if (now - lastAnimationRenderMs >= 25) {  // cap at ~40fps; keeps loop fast for handleClient()
      renderer.renderAnimFrame(millis());  // fresh millis(): animStartMs_ may be newer than loop's now
      lastAnimationRenderMs = now;
    }
    if (!renderer.animating()) {
      timeModel.markDirty();
    }
  } else if (demoMode.active()) {
    // Demo is running with no animation on screen. The demo OWNS the display
    // here — we never fall through to the consumeDirty()/needs* branches below,
    // which would render the live clock face and cause exactly the flash we're
    // eliminating. Render at ~40fps so the master-fade dissolve animates; hold
    // the last frame between renders. Only draw the face when the demo says it
    // is legitimate content (a face-based step or a fade-out of one) — during
    // animation-step breathers we draw pure black.
    if (now - lastAnimationRenderMs >= 25) {
      if (demoMode.rendersFaceNow()) renderer.render(timeModel.get());
      else                           renderer.renderTransitionBlack();
      lastAnimationRenderMs = now;
    }
  } else if (renderer.reelModeActive()) {
    // Demo-reel Live Run owns the display (see tickReelMode). While latched we
    // never fall through to the face-render branches — so the live clock face
    // can't flash between reel animations. Draw the live face only while
    // dissolving the face itself OUT (reel open) or back IN (reel close); every
    // other idle beat between animations is the dark breather → pure black.
    if (now - lastAnimationRenderMs >= 25) {
      if (renderer.reelRendersFaceNow()) renderer.render(timeModel.get());
      else                               renderer.renderTransitionBlack();
      lastAnimationRenderMs = now;
    }
  } else if (timeModel.consumeDirty()) {
    renderer.render(timeModel.get());
    lastAnimationRenderMs = now;
  } else if (renderer.needsFullAnimationFrame(now) && now - lastAnimationRenderMs >= 80) {
    renderer.render(timeModel.get());
    lastAnimationRenderMs = now;
  } else if (renderer.needsBrightnessRampFrame(now) && now - lastAnimationRenderMs >= 60) {
    // Keep re-rendering at ~16fps while auto-brightness is ramping so the
    // lux->brightness ramp actually shows up instead of only advancing once
    // per second on the idle time-tick render.
    renderer.render(timeModel.get());
    lastAnimationRenderMs = now;
  } else if (renderer.needsCenterAnimationFrame() && now - lastAnimationRenderMs >= 50) {
    // Full render instead of center-only: renderCenterAnimationFrame() called
    // setBrightness() every 80ms which re-scales the whole pixel buffer via
    // lossy integer division. Over ~12 frames/sec, ring pixels drifted ~7 units
    // darker than their correct value. render() on tick snapped them back —
    // creating a 1Hz brightness pulse on the outer ring. Inner ring ambient
    // pixels (scale 22-24/255) were too dim to show the drift, making them
    // appear "not in sync" with the outer ring. Full render here is safe:
    // strip_.clear() only zeroes RAM — it never calls show() — so no blank frame.
    renderer.render(timeModel.get());
    lastAnimationRenderMs = now;
  }
}

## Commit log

2026-07-07 ChronoBloom v2.8.0 — initial public release
    ESP32-C3 3-ring NeoPixel wall clock: WiFi/NTP, web UI, OTA updates,
    ambient-light auto-brightness, and Focus Reminder nudges for ADHD
    hyperfocus interrupts. Curated export of the maintainer's private
    development repo — see NOTICE for the full design lineage
    (Steve Manley -> Mike van der Sluis -> ChronoBloom).
    Hero image, demo video, BOM purchase links, and caliper-verified STL
    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
    [ChronoBloom-15inch-3-ring-clock(all).3mf, ChronoBloom-8inch-3-ring-Clock(ALLl).3mf, chronobloom-8inch-3-ring-CORE-(remixed-SteveManley-v2).stl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]
2026-07-07 docs: fix stale HISTORY.md tech table, add doc cross-links
    - docs/HISTORY.md: corrected comparison table (EEPROM v7 -> versioned,
    GPIO3/4 ISR -> polled GPIO5/9) which contradicted the current README;
    updated "What's Next" roadmap to stop listing already-shipped features
    (OTA, WiFi provisioning portal) as upcoming.
    - README.md: added missing links to HISTORY/CHANGELOG/ARCHITECTURE/
    FOCUS_REMINDERS.md and a 3D print files section pointing at
    ChronoBloom_3D_Files/, with a note that ring dimensions aren't yet
    caliper-verified.
2026-07-18 ChronoBloom v2.29.0 launch
    [ChronoBloom-8inch-3-ring-Clock(ALL).3mf]
2026-07-18 README replication pass, printing guide, donation button
2026-08-01 ChronoBloom v2.31.5
    Catches the public repo up from the v2.29.0 era. The headline fix: this repo
    did not compile. src/main.cpp includes anim_palettes.h and that file was never
    published, so anyone who cloned and built it hit a fatal error on line 20. The
    file ships now, and both variants are verified to build from exactly this file
    set before anything is published.
    Firmware since 2.29.0:
    - Time zone is set in the web UI and applies immediately. No compiler, no
    reflash, and a first-run banner asks for it rather than showing a confidently
    wrong hour.
    - Focus nudges escalate, and pressing either button tells the clock you saw it.
    - Auto brightness is two honest sliders: how dim in a dark r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
    [ChronoBloom-8inch-3-ring-Clock(ALL).3mf, Chronobloom-8inch-all-v11-Assembly.3mf, Chronobloom-8inch-v11-backCover(alt-w-buttons).stl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]
2026-08-01 Ring diameters, measured
    The exact ring outer diameters were never written down, only the kit listing's
    estimates, and two of those three were wrong. Calipered off the physical rings:
    outer 60-LED ring 172 mm
    middle 24-LED ring 92 mm
    inner 12-LED ring 52 mm
    center 6 mm opening for a single LED
    The listing had middle at ~88 mm and inner at ~50 mm. If you are substituting
    rings rather than using the WESIRI kit from the BOM, those 2 mm matter.
    PRINTING.md now carries the table under Ring fit, where an HTML comment used to
    sit admitting the numbers were guesses, which rendered as nothing at all. The
    README says them in the ring-seating paragraph.
2026-08-01 v2.32.0: remove sacrificial-pixel support, keep the explanation
    The maintainer's 8" prototype had one extra WS2812B spliced in ahead of the
    rings, kept dark, whose only job was to re-drive the board's 3.3 V data signal
    at a full 5 V for the LEDs behind it. It came out of the hardware on
    2026-08-01, so the firmware option went with it. Every build is now the same
    97-LED chain: 60 + 24 + 12 rings plus one centre pixel.
    Removed: the SACRIFICIAL_PIXEL_ENABLED / SACRIFICIAL_PIXEL_INDEX build flags,
    three #error geometry guards, setSacrificialPixelDark() and its three call
    sites, the sac= field in the boot LED summary, the boot serial block, and
    sacrificial_enabled from GET /diag.
    Added in its p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
    [main.cpp]
2026-08-01 docs: correct the sacrificial-pixel explanation - placement is the point
    The previous wording claimed the trick does nothing for data-line distance.
    That was wrong.
    Sited at the board beside the 5 V rail, the sacrificial LED converts the C3's
    marginal 3.3 V signal into a clean full-swing 5 V one after only a couple of
    centimetres, and it is that strong signal which then makes the long run out to
    the rings. So it buys distance as well as reliability: not by boosting the far
    end, but by shrinking the fragile stretch to almost nothing. Put it at the far
    end instead and it achieves nothing, because the weak signal has already made
    the whole journey. Same reason a 74AHCT125 belongs at the board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
    [main.cpp]
2026-08-02 v13 parts, and the assembly is bolts now
    The fastening changed. If you built an earlier one, this supersedes it.
    Before filament offcuts as alignment pins, superglue, 2mm coarse screws
    Now M2.5 fine thread bolts, and nothing else
    The ring is the spine at 21mm thick and takes thread from both sides. One bolt
    runs from the front through the diffuser, the reflector and the spacer into the
    ring. The back cover bolts into the same ring from behind. Pass-through holes
    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
    [Chronobloom-8inch-all-v11-Assembly.3mf, Chronobloom-8inch-all-v13-Assembly.3mf, Chronobloom-8inch-v11-backCover(alt-w-buttons).stl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]
2026-08-02 Stand exported for v13
    Replaces the v11 stand file that was standing in for it. Same geometry, exported
    fresh alongside the rest of the v13 parts, and named to match them.
    PRINTING.md parts table updated.
    [Chronobloom-8inch-v11-stand.stl, Chronobloom-8inch-v13-stand.stl]
2026-08-03 Re-export the v13 assembly view
    [Chronobloom-8inch-v13-AssemblyView.3mf]
2026-08-04 Sync public repo at v2.35.0
    Firmware 2.32.0 to 2.35.0: hand-contrast trial behind a wall switch, the
    last green path in deep dimming closed, one hand color everywhere, petal
    seams no longer going green, and the nudge acknowledgment removed because a
    nudge is not something you call off.
    Docs: the web UI moves to the top of the README with a screenshot, and the
    ring mapping is corrected everywhere. Seconds and minutes share the outer
    60 the way they share one track on a real clock, and the hour hand is a
    spoke across the 24 and the 12. It had been described as 60/24/12 for
    seconds/minutes/hours, which is not what the firmware does.
    Print guide gains the desk-versus-wall back plate choice. Th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
    [Chronobloom-8inch-all-v13-Assembly.3mf, Chronobloom-8inch-v13-All-AssemblyView.3mf]

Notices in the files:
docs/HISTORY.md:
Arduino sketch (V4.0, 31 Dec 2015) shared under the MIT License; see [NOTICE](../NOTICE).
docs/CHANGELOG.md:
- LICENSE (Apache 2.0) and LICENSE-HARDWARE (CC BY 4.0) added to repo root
